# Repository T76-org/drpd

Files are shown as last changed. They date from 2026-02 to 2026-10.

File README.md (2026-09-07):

# Dr. PD - Open-source USB Power Delivery Analyzer and Programmable Sink

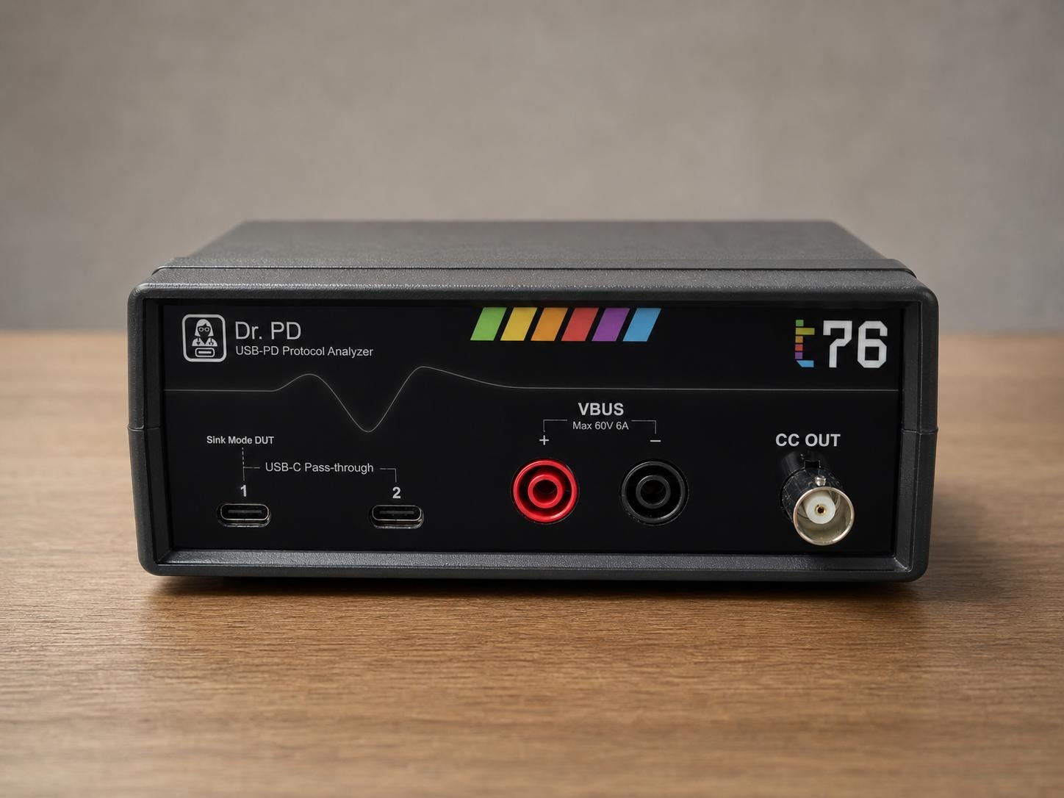
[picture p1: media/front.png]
DRPD Case Render


Dr. PD is a fully-featured USB Power Delivery (USB-PD) analyzer and programmable sink. It is designed to help characterize and troubleshoot USB-PD devices like chargers, cables, and sink devices. 

> [!NOTE]
> **Dr. PD will be available for crowdfunding soon through Crowd Supply.** Visit our [prelaunch page](https://www.crowdsupply.com/t76-org/dr-pd) to sign up and receive updates on the project, including the crowdfunding launch.
>
> Have any questions? [Drop us a note](mailto:hello@t76.org)!

## Features

Dr. PD can capture and decode USB-PD messages, measure voltage and current, and even emulate a USB-PD sink device to test chargers and cables under various conditions.

You can find out more about its features in the [online datasheet](./media/datasheet.md), but here are some important highlights:

### USB-PD protocol analysis

- Real-time message decoding with detailed protocol analysis
- Correlation of messages with VBUS voltage and current measurements
- Sophisticated search and trigger capabilities based on message types, device attach/detach events, power level changes, or external signals

### Programmable sink mode

- Emulate specific sink behavior, trigger faults, or test edge cases without a dedicated test fixture
- Analyze and test modern USB-PD implementations **up to 48V / 5A / 240W** with support for standard power delivery (SPR), extended power range (EPR), and programmable power supply modes (PPS/AVS)

### Software

- Real-time control software that runs in Chrome or Edge on Windows, macOS, Linux, and Android with no drivers or installation required
- First-class automation support with Python and JavaScript host libraries, plus support for industry-standard SCPI and USBTMC command interfaces
- Open-source hardware, firmware, and software with schematics and source code available on in this repo
- USB-PD stack implemented in firmware (instead of depending on a dedicated external chip) for maximum flexibility and updatability

## Documentation

You can access the full documentation for Dr. PD [on the T76 website](https://t76.org/drpd/docs). The documentation includes a user manual, hardware and firmware design files, and software API references.

Downloadable hardware schematics in PDF and KiCAD format are available in the [hardware folder](./hardware) of this repository. The current hardware version is [R2605-A](./hardware/R2605-A).

**Interactive online schematics and PCB layout** are available in [the docs](https://t76.org/drpd/docs/category/internals), which also contain a detailed, step-by-step description of the hardware design.

## Screenshots

Click on the images below to view them in full size.

<table width="810">
  <tr>
    <td width="270" align="center"><a href="./media/front.png">Dr. PD front panel</a></td>
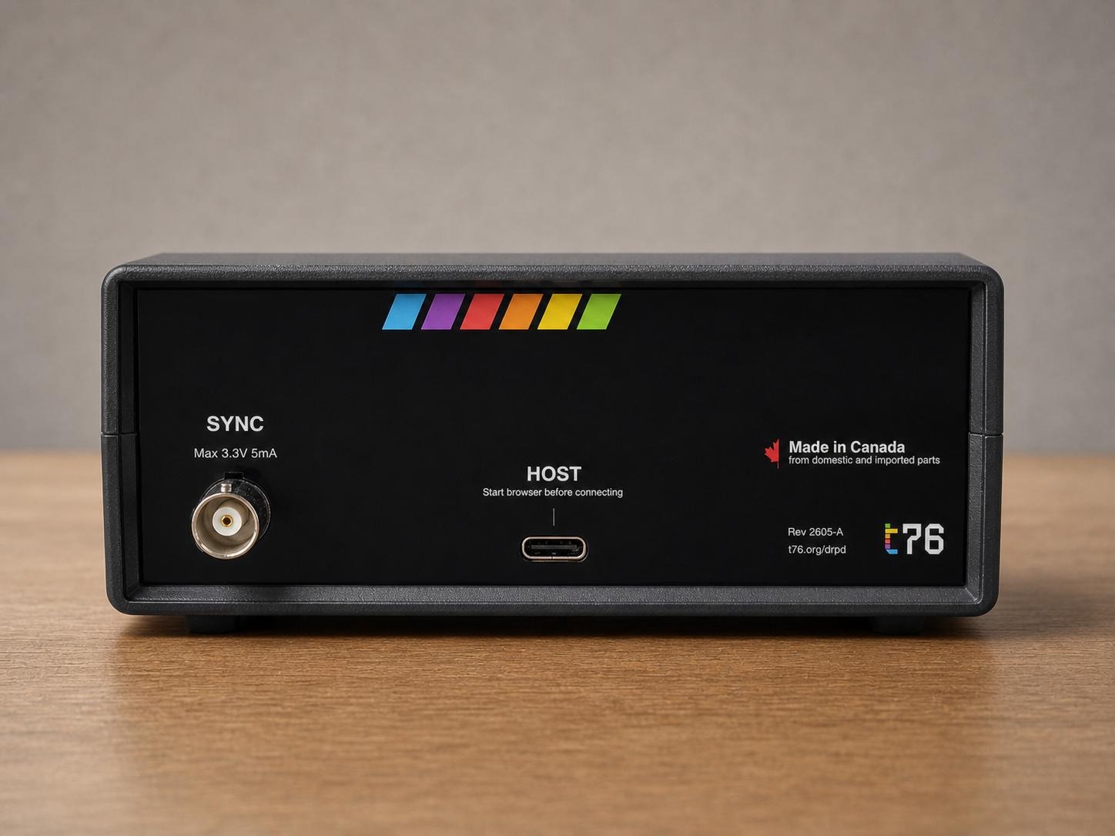
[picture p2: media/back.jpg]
Dr. PD back panel
    <td width="270" align="center"></td>
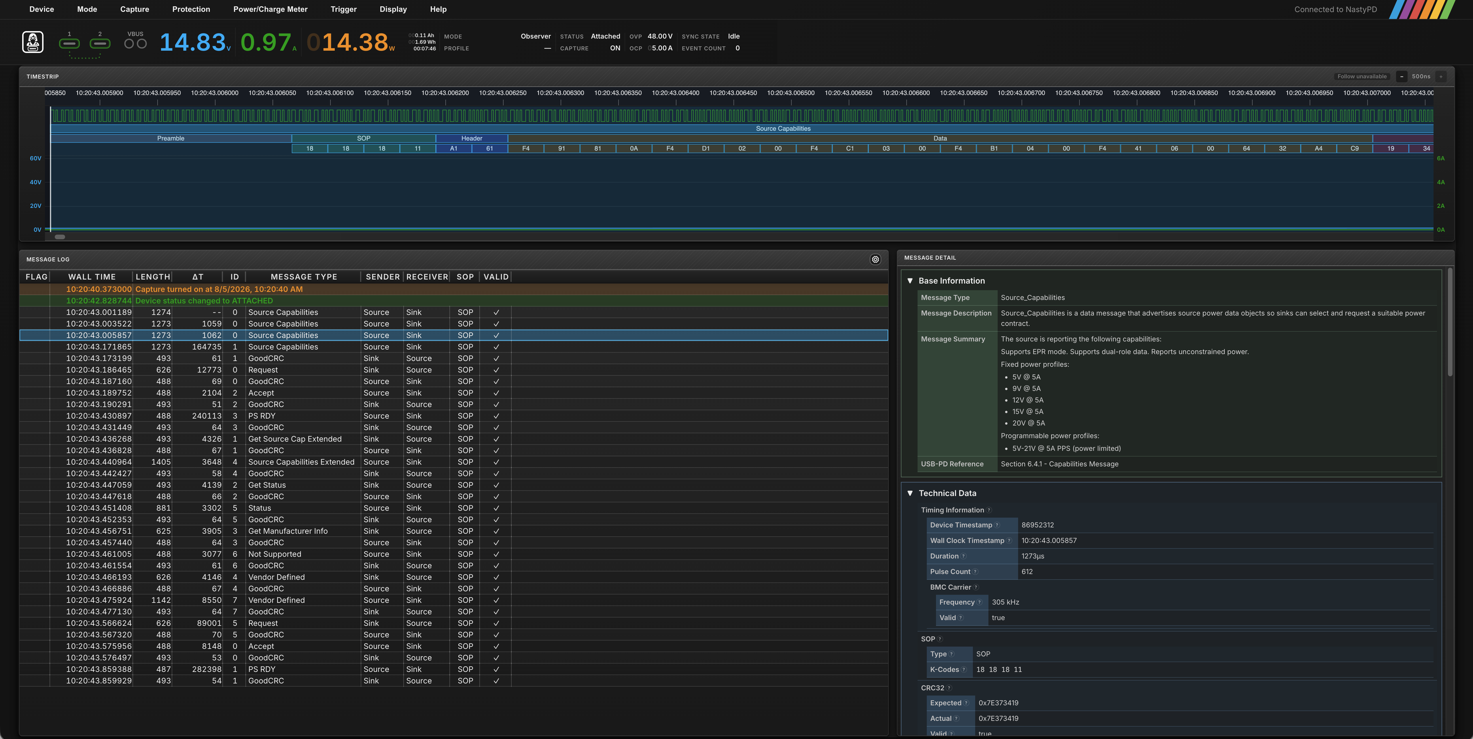
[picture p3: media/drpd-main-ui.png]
Dr. PD main interface
    <td width="270" align="center"></td>
  </tr>
  <tr>
    <td width="270" align="left" valign="top"><sub><strong>Front panel</strong></sub></td>
    <td width="270" align="left" valign="top"><sub><strong>Back panel</strong></sub></td>
    <td width="270" align="left" valign="top"><sub>The <strong>Main interface</strong> runs in your browser and shows live analog measurement, message capture, and analysis.</sub></td>
  </tr>
  <tr>
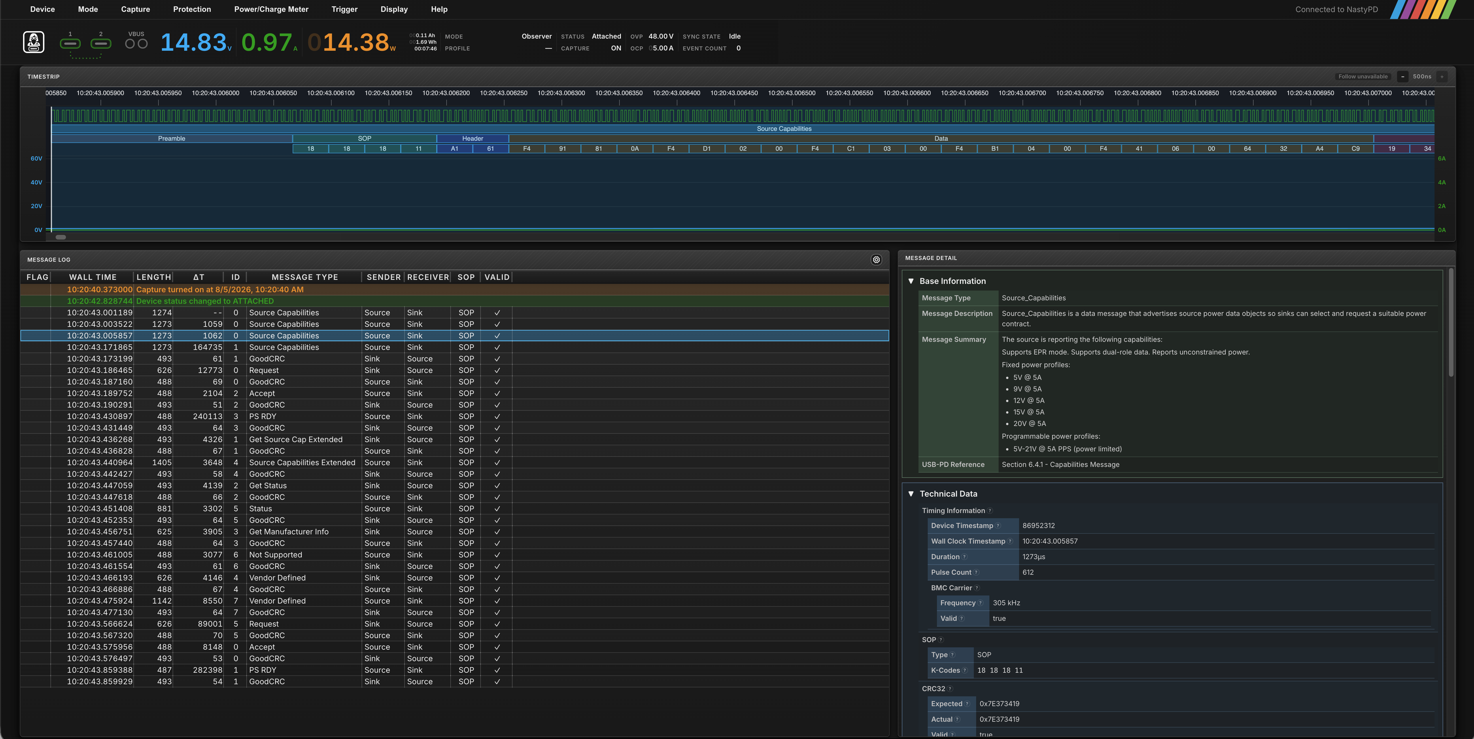
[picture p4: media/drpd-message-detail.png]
USB-PD message details
    <td width="270" align="center"></td>
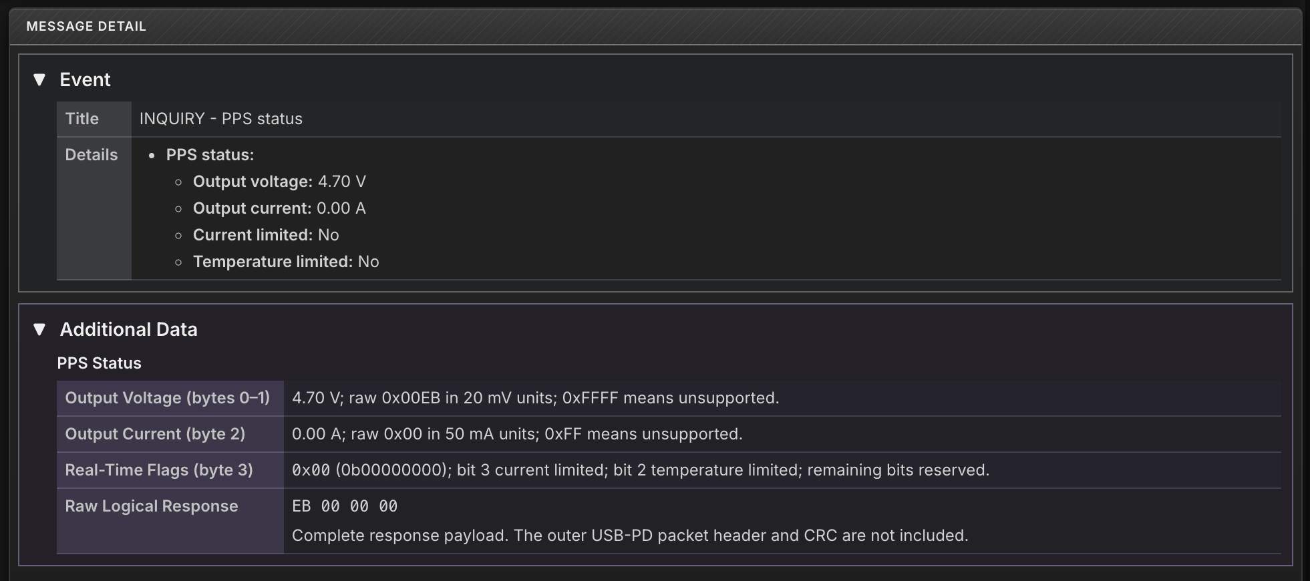
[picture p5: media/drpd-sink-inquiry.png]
Sink inquiry workflow
    <td width="270" align="center"></td>
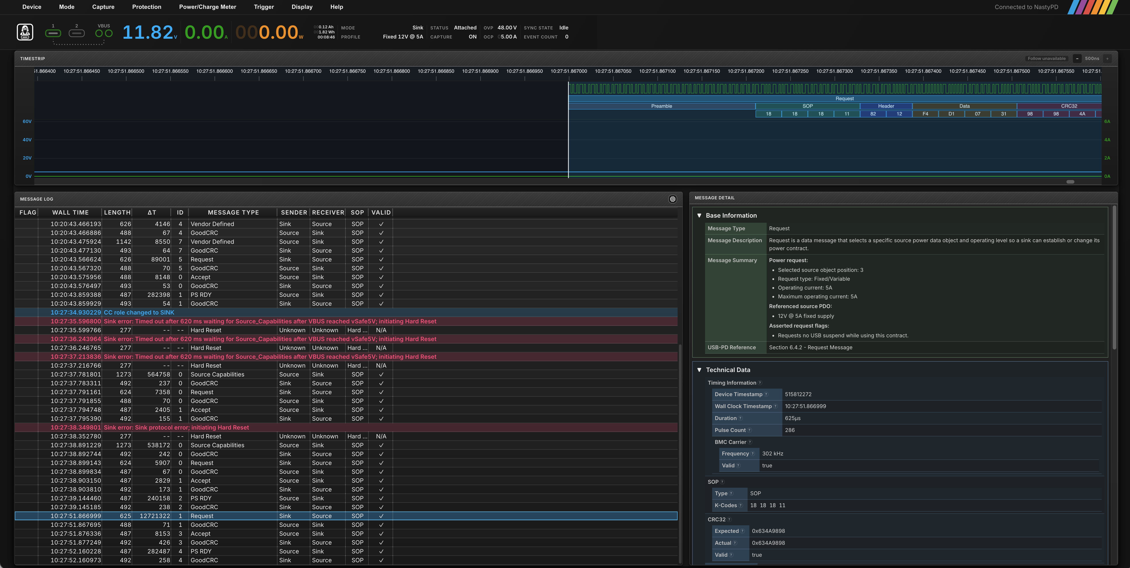
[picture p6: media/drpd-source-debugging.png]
Source debugging workflow
    <td width="270" align="center"></td>
  </tr>
  <tr>
    <td width="270" align="left" valign="top"><sub>The <strong>Message Detail</strong> breaks down each message into its constituent fields, timing data, CRC checks, and specification references.</sub></td>
    <td width="270" align="left" valign="top"><sub>In <strong>Sink Mode</strong>, Dr. PD can interrogate the source by sending arbitrary messages to it.</sub></td>
    <td width="270" align="left" valign="top"><sub><strong>Source debugging:</strong> Dr. PD can correlate protocol traffic, electrical activity, errors, and recovery attempts to help troubleshoot connectivity between sources and sinks.</sub></td>
  </tr>
  <tr>
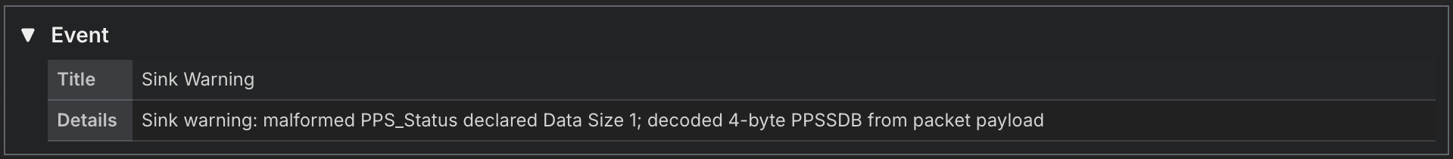
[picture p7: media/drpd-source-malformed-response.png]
Malformed source response analysis
    <td width="270" align="center"></td>
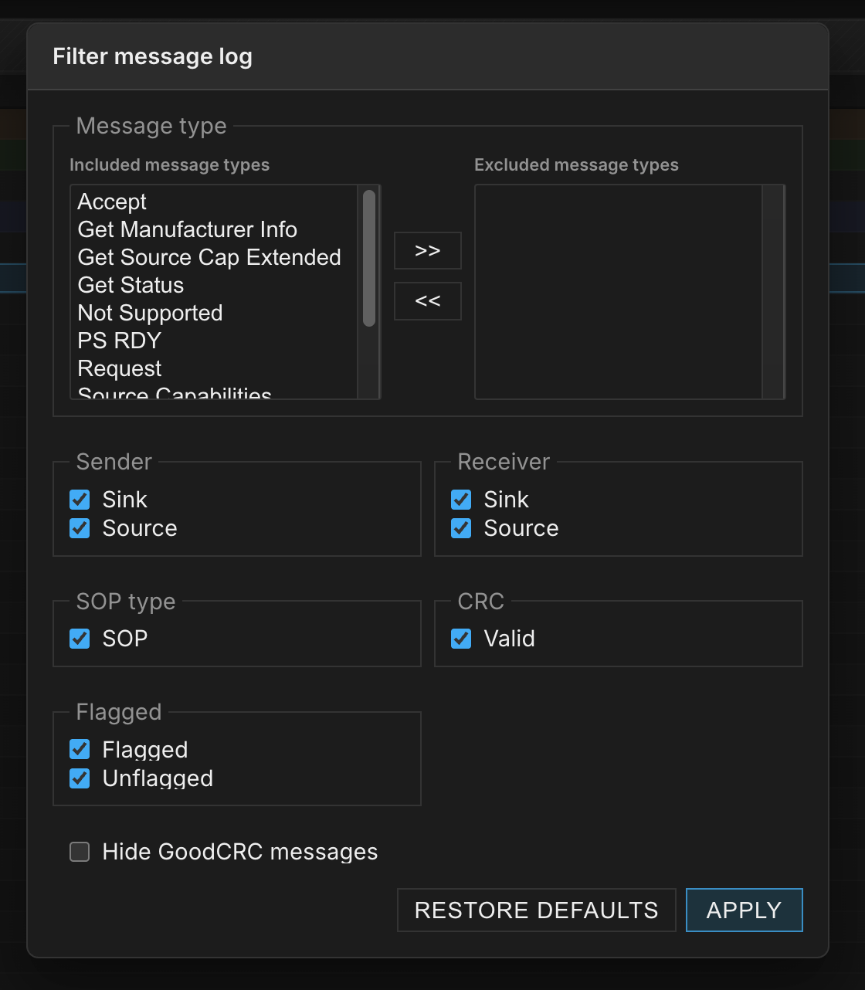
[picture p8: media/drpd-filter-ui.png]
Message log filters
    <td width="270" align="center"></td>
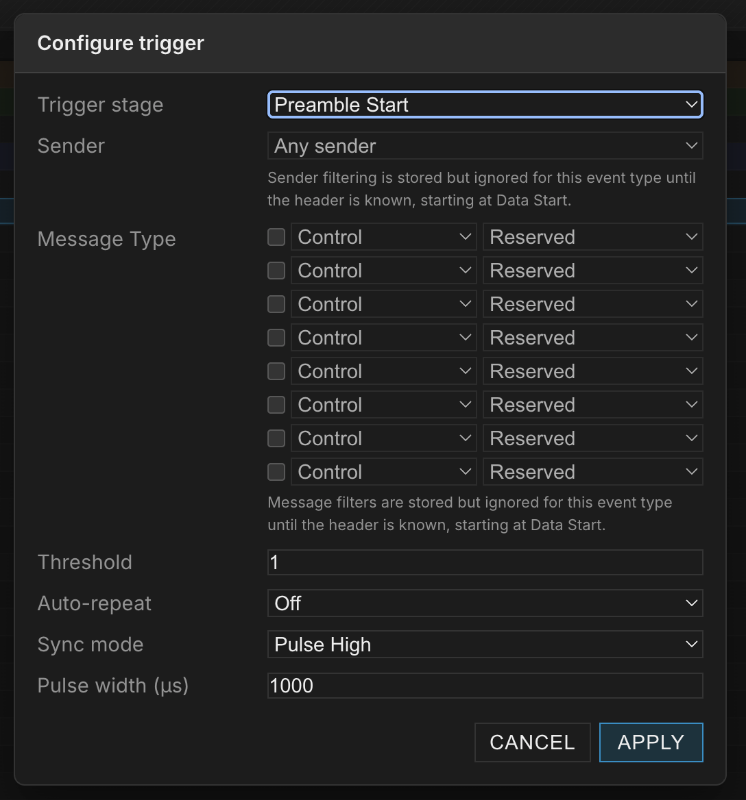
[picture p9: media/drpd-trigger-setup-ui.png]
Capture trigger setup
    <td width="270" align="center"></td>
  </tr>
  <tr>
    <td width="270" align="left" valign="top"><sub><strong>Response analysis:</strong> Here, Dr. PD has discovered that the connected source sent a non-compliant response.</sub></td>
    <td width="270" align="left" valign="top"><sub><strong>Message log filters</strong><br>Filter by message type, sender, receiver, SOP type, CRC, and flags.</sub></td>
    <td width="270" align="left" valign="top"><sub><strong>Capture trigger setup</strong><br>Trigger on protocol stages, message types, thresholds, or synchronized pulses.</sub></td>
  </tr>
</table>

## Project status

Dr. PD is currently undergoing device validation testing and will be available for crowdfunding soon through Crowd Supply. Visit our [prelaunch page](https://www.crowdsupply.com/t76-org/dr-pd) to sign up and receive updates on the project, including the crowdfunding launch.

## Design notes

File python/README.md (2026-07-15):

# `t76` Python Package

Python tooling for DRPD devices, including:

- A Python API for device discovery and control
- USB-PD message decoding helpers
- A Textual terminal app UI

Requires Python 3.11 or newer.

## Install from PyPI

> **Publication status:** `t76` is not published on PyPI yet. Until the first
> release is available, use the repository installation below.

```bash
python -m pip install t76
```

## Install from the Repository

From a clone of the repository:

```bash
python3 -m venv .venv
source .venv/bin/activate
python -m pip install --upgrade pip
python -m pip install -e ./python
```

For development dependencies:

```bash
python -m pip install -e "./python[dev]"
```

To leave the environment:

```bash
deactivate
```

Maintainers publish releases locally using the process in
[RELEASING.md](RELEASING.md).

## Run the Textual App

Launch the Dr. PD terminal app with:

```bash
drpd
```

The module entry point remains available:

```bash
python3 -m t76.drpd
```

If your `.venv` is active, `python -m t76.drpd` works as well.

You can also list available top-level apps with:

```bash
python -m t76 --apps
```

## Library Usage

### Discover and Connect to a DRPD Device

```python
import asyncio

from t76.drpd.device import find_drpd_devices

async def main() -> None:
    devices = find_drpd_devices()
    if not devices:
        print("No DRPD devices found.")
        return

    device = devices[0]
    await device.connect()
    try:
        mode = await device.mode.get()
        print(f"Connected to {device.name}, mode={mode}")
    finally:
        await device.disconnect()

asyncio.run(main())
```

### Decode USB-PD Messages

The `t76.drpd.message` package exposes message classes and decoding helpers.

Example imports:

```python
from t76.drpd.message import Message, SourceCapabilitiesMessage, VendorDefinedMessage
```

For captured BMC/PD data, see `BMCSequence.from_scpi_response(...)` in `t76.drpd.message.bmc_sequence`.

## Run Tests

With the `.venv` active:

```bash
bash run_tests.sh
```

Or directly:

```bash
python -m pytest t76/drpd/tests/ -v --tb=short
```

## License

The `t76` Python package is licensed under the GNU Affero General Public
License v3.0 only (`AGPL-3.0-only`). Source is available from the
[T76-org/drpd repository](https://github.com/T76-org/drpd).

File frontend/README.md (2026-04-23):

# Frontend

Primary docs:

- [Designer getting started](./docs/designer-getting-started.md)
- [Rack and instruments](./docs/rack-instruments.md)
- [Dr. PD device model](./docs/drpd-device.md)
- [Dr. PD worker runtime](./docs/drpd-worker-runtime.md)
- [Dr. PD firmware updater](./docs/drpd-firmware-updater.md)

Run locally:

```bash
npm run dev
```

For LAN debugging from another machine, start the HTTPS dev server:

```bash
npm run dev:https
```

The server stays on port `5173`. If you want to use the generated development
certificate, set `DRPD_DEV_PUBLIC_HOST` to a hostname that resolves to the dev
machine and use the exact HTTPS URL Vite prints, for example
`https://drpd.local:5173/`. If you want to use a raw LAN IP or a different
certificate name, point `DRPD_DEV_HTTPS_CERT` and `DRPD_DEV_HTTPS_KEY` at a
certificate whose SANs include that address or hostname.

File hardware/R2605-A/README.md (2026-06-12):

# Hardware revision R2605-A

Revision 2605-A is the first PVT revision of the Dr. PD hardware. It is based largely on R2603-A, with some important changes:

- The host port is now USB-C, rather than microUSB.
- The OVC/OCP circuit is bidirectional
- The banana connectors now include reverse-polarity protection
- There is a new slew control circuit for the BMC encoder outputs, which should better conform to the USB-PD standard and reduce EMI.

You can use the [virtual BOM](./virtual-bom/bom.html) to see the components used in this revision and how they are placed on the board.

The schematic is available in [PDF format](./pdf/Dr.PD.pdf) and in [KiCad format](./kicad/DrPD.kicad_sch), which can be viewed using [KiCanvas](https://kicanvas.org/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).

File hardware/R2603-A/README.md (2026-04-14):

# Hardware revision R2603-A

Revision 2603-A is the final prototype revision before production. It is the version that is in the hands of beta testers as of March 2026.

You can use the [virtual BOM](./virtual-bom/bom.html) to see the components used in this revision and how they are placed on the board.

The schematic is available in [PDF format](./pdf/Dr.PD.pdf) and in [KiCad format](./kicad/DrPD.kicad_sch), which can be viewed using [KiCanvas](https://kicanvas.org/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).

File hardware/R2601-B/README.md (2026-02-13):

# Hardware revision R2601-B

This was an early Dr. PD prototype that is unlikely to be in anyone's hands, so this schematic and layout is here primarily for historical reasons.

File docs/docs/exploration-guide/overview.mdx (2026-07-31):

---
sidebar_position: 1
---

# Start exploring Dr. PD

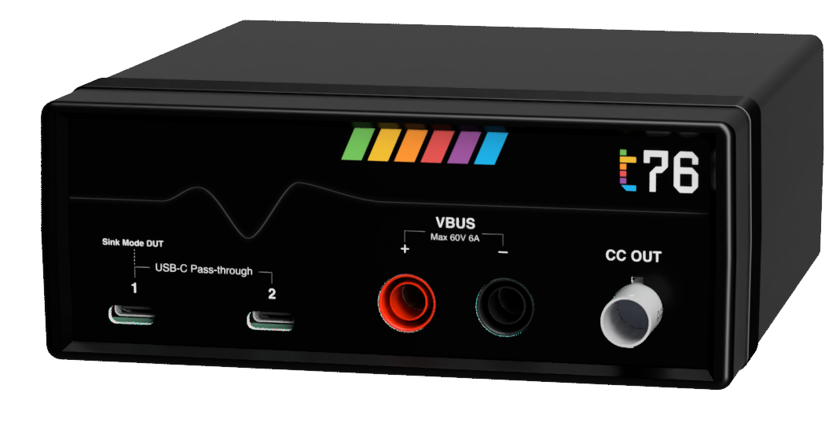
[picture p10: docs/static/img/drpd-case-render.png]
Dr. PD case render


Dr. PD is an open-source USB Power Delivery analyzer and programmable sink for
characterizing USB-PD sources, sinks, and cables. It captures decoded USB-PD
traffic, correlates protocol activity with VBUS voltage and current
measurements, and can act as a controllable sink when you want to see how a
source responds to different power requests.

This guide is a map of useful paths through the instrument. You can follow one
path end to end, skip to the workflow that matches your bench setup, or use the
links as a starting point before branching into your own tests.

## What you can explore

- **Protocol captures:** watch Source Capabilities, Requests, Accepts, PS RDY,
  GoodCRC messages, resets, and errors in the Message Log.
- **Power behavior:** correlate those messages with VBUS voltage and current
  while a source attaches, changes contract, disconnects, or trips protection.
- **Sink mode:** connect a USB-PD source to Port 1 and request advertised fixed,
  PPS, AVS, or EPR contracts when the source and cable support them.
- **Observer mode:** put Dr. PD inline between an existing source and sink to
  watch what those devices negotiate with each other.
- **Bench integration:** use the banana connectors, protection settings, sync
  output, exports, and automation interfaces when you want deeper measurements.

Dr. PD can work with USB-PD sources and cables up to 48 V / 5 A / 240 W when
the source, cable, negotiated protocol state, load, and safety setup all support
those conditions. EPR, PPS, and AVS behavior depends on what the attached source
and cable advertise and what you explicitly enable.

## Your first capture

For a first look, use a known-good USB-PD charger and cable.

1. Connect Dr. PD to the host computer with a USB-C cable capable of USB 2.0 communications, open the control software
   in Chrome or Edge, and pair the device. If your browser offers it, you can
   [install Dr. PD as an app](../how-to/installing-as-app.mdx) and launch the
   same control software in a standalone app window later.
2. Select **Capture → Enable Capture**.
3. Select **Mode → Sink**.
4. Connect the USB-PD source to Port 1.
5. Watch the Message Log populate with decoded USB-PD messages and correlated
   VBUS measurements.
6. Open **Mode → Choose power contract...** if you want to compare another
   contract that the source advertises.
7. Select a few messages and use **Capture → Export Selected → CSV...** or
   **Capture → Export Selected → JSON...** if you want data for notes or
   external analysis.

If the source was already connected when capture started, select **Mode → Cycle
USB Connection** before reviewing the log so the attach and initial negotiation
are captured.

For an inline observation path, put Dr. PD in **Mode → Observer**, connect it
between a source and sink with two USB-C cables, select **Capture → Enable
Capture**, and then attach the second device to capture the negotiation.

## Useful next paths

- [Front and back panels](./front-and-back-panels.mdx) for a visual tour of
  every physical connection on Dr. PD.
- [Quickstart overview](../quickstart/overview.mdx) for basic setup and first
  connection.
- [Testing a USB-PD source](../quickstart/testing-usb-source.mdx) for the first
  Sink mode walkthrough.
- [Capturing USB-PD messages](../how-to/capturing-messages.mdx) for capture,
  filtering, message details, and export.
- [Operating Dr. PD as a sink](../how-to/operating-as-sink.mdx) for programmable
  sink behavior, contract selection, PPS/AVS, and EPR notes.
- [Observing a USB connection](../how-to/observing-connection.mdx) for inline
  Observer mode setup.
- [Important warnings and safety precautions](../important-warnings.mdx) before
  high-power or unknown-device tests.

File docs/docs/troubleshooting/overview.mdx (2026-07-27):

---
sidebar_position: 1
title: Troubleshooting Dr. PD
---

# Troubleshooting Dr. PD

Start with the symptom that best matches what you see:

- If Dr. PD does not appear in the browser's device picker, disconnects from the control software, or cannot be paired, see [Computer connection](./computer-connection).
- If the control software opens but does not update or behave as expected, see [Control software](./control-software).
- If Dr. PD cannot attach to a source or negotiate the power contract you expect, see [Sink mode](./sink-mode).
- If the devices on either side of Dr. PD do not connect, or the capture is missing messages, see [Observer mode](./observer-mode).
- If you need to report a problem, see [Diagnostics and support](./diagnostics-and-support) for the information to collect.

## Basic checks

Before investigating a specific symptom:

1. Confirm that the control cable is connected to Dr. PD's control port, not Port 1 or Port 2.
2. Use a control cable that supports USB 2.0 data. A charge-only cable can power Dr. PD without making it available to the computer.
3. Disconnect and reconnect Dr. PD, then reopen the control software.
4. Confirm that Chrome or Edge is up to date.
5. Remove other USB-C devices and test with the simplest possible setup.

Change one cable, port, device, or setting at a time. This makes it much easier to identify which part of the setup caused the problem.

## Use the status indicators

The control software's MODE and STATUS indicators are useful starting points. First confirm that MODE shows the intended operating mode. Then note the exact STATUS value, such as **Unattached**, **Source Found**, or **Attached**, before changing the setup.

Also note whether VBUS, PROFILE, and the Message Log change when you attach a device. These observations help distinguish an electrical attachment problem from a power-negotiation or capture problem.

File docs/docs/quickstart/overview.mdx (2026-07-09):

---
sidebar_position: 1
---

# Get started in 5 minutes (or less)

Connecting Dr. PD to your computer and getting your first USB-PD capture is quick and easy. This guide will walk you through the steps to get up and running in no time.

## Things you will need

1. A computer with a recent version of Chrome or Edge and a USB port. Dr. PD runs on Windows, macOS, Linux, and Android.
2. A USB-C cable to connect Dr. PD to your computer or tablet. This cable must support USB 2.0 communications in order to run the control software, but it does not need to support USB-PD or high-speed data transfer.
3. A USB-PD source to test, such as a charger, power bank, or USB-C port on a laptop.
4. A USB-C cable.

## First steps

1. [Connecting Dr. PD](./connecting-dr-pd)
2. Pairing your device
3. Testing a USB-PD source

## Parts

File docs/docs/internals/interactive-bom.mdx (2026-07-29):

---
sidebar_position: 2
slug: /internals/interactive-bom/
hide_table_of_contents: true
title: Interactive BOM
description: Explore the Dr. PD R2605-A bill of materials and board placement.
---

import InteractiveBom from '@site/src/components/InteractiveBom';

# Interactive BOM

Use the component table and board view together to inspect the R2605-A bill of materials and locate parts on the PCB.

<InteractiveBom />

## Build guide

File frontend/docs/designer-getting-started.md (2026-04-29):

# Designer Getting Started

## What USB-PD Is

USB Power Delivery (USB-PD) is the negotiation protocol that runs over a USB-C connection so two devices can agree on power direction, voltage, current, and, in some cases, data mode changes. Instead of a cable always delivering one fixed power level, USB-PD lets a source and a sink negotiate profiles such as 5 V, 9 V, 15 V, or 20 V and coordinate capabilities, requests, and status updates.

For this project, the important UX implication is that the UI is not just showing static electrical readings. It is showing an active conversation between two USB-C partners: what power is available, what was requested, what role each side is playing, and what messages are moving across the link.

## What Dr. PD Does

Dr. PD is the hardware device this frontend talks to. In the codebase it appears as the device identifier `com.mta.drpd` and the display name `Dr. PD`.

At a high level, Dr. PD acts as a USB-PD analysis and control instrument. It can:

- monitor live VBUS measurements such as voltage and current
- observe CC line state
- capture USB-PD messages
- expose message logs and time-based visualizations
- let the operator configure sink behavior, triggers, and related test settings

That is why the UI looks more like a bench instrument rack than a conventional dashboard. It is presenting several specialized views onto one physical device.

## Core UI Concepts

### Rack

The main UI metaphor is a rack. A rack is the top-level visual workspace. It contains:

- a list of physical devices attached to the rack
- a list of rows
- persisted flex weights for rows and instruments
- draggable splitters between adjacent instruments and rows

The rack definition is persisted in local storage, so layout changes survive reloads.

### Device

A device is a physical hardware entry known to the rack. Right now the main device is Dr. PD. Devices are stored separately from instruments so multiple UI panels can bind to the same hardware record.

### Instrument

An instrument is one UI panel. Examples in this frontend include:

- `VBUS`
- `Device Status`
- `CC Lines`
- `Sink Control`
- `Sync Trigger`
- `Message Log`
- `Timestrip`
- `Message Detail`

Each instrument has a default flex weight plus minimum CSS width/height constraints. Users can resize instruments freely without a grid.

### Row

A row is a horizontal strip in the rack. Instruments sit side by side inside a row. The space between instruments is a draggable splitter that shifts flex weight from one neighbor to the other.

Rows also determine height. The space between rows is a draggable splitter. Dragging it grows one row and shrinks the adjacent row while honoring instrument minimum heights.

### Edit Mode

The rack has an edit mode for layout changes. In edit mode:

- instruments become draggable
- close buttons appear
- drop zones appear between rows
- drag operations can reorder within a row or create new rows
- changes are transactional until the user saves

Resize splitters are always active, even outside edit mode.

This matters for design work because layout affordances, focus states, glow treatments, and empty/drop states all live in this mode.

## How The Frontend Is Organized

### Main entry points

- `src/main.tsx`: bootstraps the app
- `src/App.tsx`: very thin shell around the rack view
- `src/index.css`: global design tokens, colors, typography, spacing, and rack sizing tokens
- `src/App.css`: root viewport layout

### Rack feature area

Most layout and UX work happens in `src/features/rack/`.

- `RackView.tsx`: page-level rack experience, header, theme toggle, add-device and add-instrument menus, edit mode, and persistence wiring
- `RackRenderer.tsx`: rack canvas sizing, scroll/fit behavior, row rendering, full-screen overlay handling
- `RowRenderer.tsx`: per-row instrument sizing, resize splitters, drag/drop insertion logic, and dispatch to concrete instrument views
- `layout.ts`: legacy unit helpers plus flex/min-size helpers
- `rackCanvasSize.ts`: computes the base rack canvas width and height
- `rackSizing.ts`: reads sizing tokens from CSS so TypeScript layout logic and CSS stay aligned

### Instrument implementations

Concrete instrument UIs live in `src/features/rack/instruments/`.

Each instrument typically has:

- a `.tsx` file for behavior and structure
- a `.module.css` file for scoped styling

If you are redesigning the chrome shared by all instruments, start with:

- `src/features/rack/InstrumentBase.tsx`
- `src/features/rack/InstrumentBase.module.css`

If you are redesigning a specific panel, work in that instrument’s `.tsx` and `.module.css`.

### Data and definitions

- `src/lib/rack/types.ts`: rack, row, instrument-instance, and device-record data model
- `src/lib/rack/loadRack.ts`: local storage persistence
- `src/lib/instrument/types.ts`: instrument definition model including default flex and minimum CSS sizes
- `src/features/rack/instrumentCatalog.ts`: the catalog of supported instruments and their default sizes
- `src/lib/device/drpd.ts`: Dr. PD device definition

## How Layout Works

### Flex-based layout

The rack uses CSS flex for instruments and rows. Legacy unit fields still exist for compatibility, but the renderer no longer allocates space with a grid or explicit panel sizes.

Default sizing tokens are:

- 1 horizontal unit = `20px`
- 1 vertical rack unit = `100px`
- maximum row width = `60` horizontal units

In practice the standard bench layout keeps a 1200 px reference width for header alignment. The rack canvas itself fills the viewport, with row heights and instrument widths coming from CSS flex weights.

### Width allocation and resizing

Instrument widths come from `instrumentCatalog.ts`.

- `defaultFlex`: default horizontal weight for new or migrated instances
- `minWidth`: minimum width CSS length during resizing

`RowRenderer.tsx` renders a splitter between adjacent instruments. Dragging it increases one instrument's flex weight and decreases the neighbor's flex weight. The browser handles final sizing through CSS flex.

The saved `RackInstrument.flex` value wins over catalog defaults.

### Height allocation

Each row and instrument uses flex for height distribution. Instruments declare `minHeight`.

`RackRenderer.tsx` renders a splitter between rows. Dragging it shifts flex weight between adjacent rows.

### Full-screen mode

An instrument instance can be marked `fullScreen: true`. When that happens, `RackRenderer.tsx` stops showing the standard rows and instead renders a full-screen overlay for that instrument.

## CSS Setup

### Global tokens first

`src/index.css` is the foundation. It defines:

- typography tokens (UI font: **Inter** via Google Fonts, with system-ui fallbacks in `--font-family-base`)
- spacing tokens
- radius and border tokens (including `--radius-instrument` for instrument panels, `--radius-control` for buttons and controls)
- rack sizing tokens
- light and dark theme colors
- elevation shadows: `--shadow-instrument` (instrument panels; dark uses inset top highlight + outer shadow), `--shadow-rack-canvas` (rack canvas), `--shadow-header` (page header; light theme)
- dark default look: charcoal / neomorphic-inspired surfaces (`#121212` page, `#1e1e1e` panels, instrument body uses `--color-surface-instrument` gradient only); instrument **title bars** use `--texture-instrument-header` (subtle diagonal stripes) plus a light gradient; light theme restores a larger `--radius-instrument`

Most shared dimensions are expressed through CSS custom properties in `src/index.css`. Use those tokens directly instead of reintroducing global scaling.

### Scoped styles second

Feature and instrument styles use CSS modules:

- `RackView.module.css`
- `RackRenderer.module.css`
- `RowRenderer.module.css`
- `InstrumentBase.module.css`
- instrument-specific `*.module.css`

The intended layering is:

1. `index.css` defines the shared system
2. feature CSS modules apply structure and component-level styling
3. instrument CSS modules handle panel-specific layout and visuals

### Important styling conventions

- Use tokens from `src/index.css` instead of hardcoded pixel or `rem` values when possible.
- Header popovers should use the shared popup typography tokens, not custom font sizes per instrument.
- Most instrument spacing and sizing should inherit from shared tokens so the interface stays coherent across displays.
- Shared panel chrome belongs in `InstrumentBase.module.css`; avoid duplicating it inside each instrument.

## How The UI Scales Across Resolutions

### Fixed tokens

The app uses fixed design tokens from `src/index.css`. Browser zoom remains native browser behavior; the app does not compute or write a global UI scale.

Because the scale is written into CSS variables, typography, spacing, borders, splitters, popovers, and many instrument-specific measurements all scale together.

### Practical effect

On smaller screens:

- text, controls, gaps, and instrument dimensions shrink together
- the rack still preserves its proportional structure
- some instruments will feel denser rather than switching to a separate mobile layout

On larger screens:

- the same visual system expands proportionally
- flex panels render larger in the scaled UI
- popovers and dense data tables also scale up

This frontend is therefore better described as a scaled desktop instrument UI than as a breakpoint-heavy responsive website.

### Scroll versus fit behavior

`RackRenderer.tsx` also adapts vertically based on available viewport height.

- if the viewport is shorter than the computed rack canvas height, the rack enters scroll mode
- if the viewport is tall enough, the rack fits without vertical scrolling

The renderer lets CSS flex stretch the rack canvas to the viewport. If minimum sizes exceed the viewport, the containing viewport handles overflow.

### Popovers and overlays

Header menus and instrument popovers use viewport-aware positioning from `RackView.tsx` and sizing tokens from `rackSizing.ts`. Their dimensions come from fixed tokens, and their position is clamped so they stay on-screen.

## Where A Designer Should Start

If your task is mainly visual polish:

- start with `src/index.css` for tokens and theme values
- then inspect `src/features/rack/InstrumentBase.module.css` for shared panel chrome
- then adjust `RackView.module.css`, `RackRenderer.module.css`, and `RowRenderer.module.css` for overall composition

If your task is panel-specific UX:

- work inside the target instrument under `src/features/rack/instruments/`
- check whether the issue is structural in the `.tsx` file or purely visual in the `.module.css`

If your task is changing spatial behavior:

- inspect `instrumentCatalog.ts` for default widths/heights
- inspect `layout.ts` for row allocation rules
- inspect `rackCanvasSize.ts` and `rackSizing.ts` for global size math

## Useful Additional Context

### Persistence

The rack document is stored in local storage under `drpd:rack:document`. If a layout change seems to “stick” unexpectedly while you are iterating, you may be seeing persisted local state rather than code changes.

### Theme support

The app supports dark and light themes through root-level CSS variables in `src/index.css`. Theme switching happens in `RackView.tsx` by setting `data-theme` on the document root.

The **dark (default)** palette layers neomorphic-style elevation (inset highlight + drop shadow) on instruments and the rack canvas; instrument **headers** use `--texture-instrument-header` (subtle stripes). **Light** theme uses a larger `--radius-instrument`. You can archive reference mockups alongside the repo under `docs/assets/` if useful.

### Current design bias

The current UI is intentionally instrument-like:

- dense information
- strong borders
- compact uppercase headers
- panelized layout instead of card grids

When redesigning, it is usually better to preserve the rack metaphor and improve clarity, hierarchy, and task flow than to flatten the product into a generic dashboard.

### Running the frontend

From the `frontend/` directory:

```bash
npm run dev
```

The sample rack lives at `public/racks/sample-rack.json`, and the active rack state is then persisted locally in the browser.

## Related docs

- `docs/rack-instruments.md`: rack and instrument architecture
- `docs/drpd-device.md`: Dr. PD command groups and device model
- `docs/drpd-worker-runtime.md`: frontend runtime and worker architecture

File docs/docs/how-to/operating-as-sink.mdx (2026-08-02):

---
sidebar_position: 2
---

# Operating Dr. PD as a sink

In addition to [observer mode](./observing-connection.mdx), Dr. PD can also be used in _Sink Mode,_ where it acts as a USB-PD sink device that can be powered by a compatible source. 

This mode allows you to safely test and characterize source devices and cables without risking damage to your actual devices, and with more control over power contracts and energy use than you would have with a real sink.

## Set up

To enter sink mode, click on **Mode → Sink** from the menu, or press the `S` key on your keyboard. You should see the MODE indicator in the control app's header change to "Sink," and the STATUS indicator will read "Unattached" until you connect a source device.

Connect your source device to Port 1 (the left port) using a USB-C cable of your choice. If all goes well, you should see the STATUS indicator change to “Attached,” and the VBUS voltage and PROFILE indicator will show the current power contract between the source and Dr. PD, which will normally be the default 5V/3A contract that most sources will offer to a sink that does not have any special capabilities.

## Changing the power contract

In sink mode, Dr. PD takes note of the contracts that the source offers, and allows you to establish a new contract with the source by selecting one of the offered contracts from the Sink power contract selection dialog (**Mode → Choose power contract...**). This allows you to test the behavior of the source under different power conditions, and to perform energy measurements at different power levels.

## Sending inquiries to the source

While Dr. PD is attached as a sink, select **Mode → Sink behaviour → Send inquiry to source** to ask the source for information such as its capabilities, status, revision, manufacturer information, country information, battery information, supported USB modes, or Type-C authentication data. The available inquiries depend on the negotiated USB-PD revision and active power contract.

Each selection starts one explicit inquiry. The source may return the requested information, reject the request, report that it is not supported, or fail to respond. Dr. PD records the request, response, and final outcome in the Message Log; keep capture enabled if you want to inspect or export that evidence. These inquiries normally leave the active power contract unchanged.

:::caution

Some inquiries have protocol-defined side effects. In particular, **Get status** clears the source's latched overcurrent, overvoltage, and overtemperature event indicators after reading them. Dr. PD asks for confirmation before sending an inquiry with a known side effect.

:::

## Drawing power from the source

In sink mode, you can use the banana connectors to monitor the VBUS voltage with an external voltmeter, and to draw current from the source using an external load—for example, to perform energy measurements or test the source's protection mechanisms.

:::note

In this mode, Port 2 is disconnected from the USB-PD bus and VBUS line in order to protect any device that you might have inadvertently left connected to that port, and so you will not be able to use Port 2 for any USB-PD communication or power delivery while in sink mode.

:::

:::warning[Safety mechanisms]

In addition to the protection mechanisms implemented by your source device, Dr. PD implements its own set of [overvoltage/overcurrent protections](./protection-mechanisms). You can use them in tandem with native protections in order to make sure that you don't damage your source device or Dr. PD itself while testing, but Dr. PD does not automatically set any protection mechanisms for you (beyond the default 60V / 6A limits that are hardcoded into the firmware to prevent damage to Dr. PD itself), so you should make sure to set appropriate limits for your tests in order to avoid damage to your source device or Dr. PD.

:::

## Using PPS and AVS contracts

The USB-PD protocol includes some special types of power contracts that allow for more granular control over the voltage and current levels, which can be useful for testing sources that support these contracts:

- PPS (Programmable Power Supply) contracts allow the sink to request specific voltage and current levels within a certain range, which can be useful for testing sources that support PPS and for avoiding triggering the protection mechanisms of the source when drawing power at higher levels.
- AVS (Adjustable Voltage Supply) contracts similarly allow the sink to request specific voltage levels within a certain range, but they are designed for higher voltage levels (up to 48V) and are typically used for applications like USB-PD power delivery to laptops and other high-power devices.

Dr. PD is fully compatible with both PPS and AVS. If your source supports PPS or AVS contracts, you can use them to test the source's behavior under different voltage and current conditions, and to perform energy measurements at different power levels without triggering the source's protection mechanisms.

:::tip[Requesting PPS status information]
With an active PPS contract, select **Mode → Sink behaviour → Send inquiry to source → Get PPS status** to request the voltage, current, and operating status reported by the attached Source. This sends one explicit `Get_PPS_Status` inquiry.
:::

## Enabling support for EPR

Recent versions of the USB-PD protocols have introduced _Extended Power Range_ (EPR) contracts, which allow for power delivery at voltages up to 48V and currents up to 5A. Dr. PD is compatible with EPR, and we designed its hardware specifically to support voltage and current ranges _in excess_ of the USB-PD 3.1 specification in order to allow you to test EPR sources and cables without risking damage to Dr. PD itself.

:::warning
At 48V and 5A, high-end EPR sources pack quite the punch and can deliver some 240W of power (in our experience, they will often even _exceed_ this level by a small amount). This is more than enough to cause serious damage to devices that are not designed to handle such power levels, and even cause a fire if something goes wrong.

When you test EPR sources at high power levels, make sure to use appropriate safety precautions, such as using a high-quality USB-C cable that is rated for EPR, making sure that your source and Dr. PD are on a non-flammable surface, and keeping a fire extinguisher nearby just in case.
:::

EPR support is off by default. In order to enable it, choose **Mode → Sink behaviour → Support EPR mode**. Once you have enabled EPR support, Dr. PD will be able to negotiate EPR contracts with compatible sources, and you will be able to test the source's behavior under EPR conditions.

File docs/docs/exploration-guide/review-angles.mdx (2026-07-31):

---
sidebar_position: 3
---

# Choose an exploration path

Dr. PD can be approached from several directions. The paths below are not
scripts; they are starting points for deciding what you want to learn first.
Each one points to the parts of the instrument that tend to be most useful for
that kind of exploration.

## Embedded and software path

This path is useful when you care about repeatability, exported data, and how
USB-PD behavior can fit into a development workflow.

Things to try:

- Capture and decode USB-PD messages while a device attaches, negotiates, and
  changes state. The [message capture guide](../how-to/capturing-messages.mdx)
  explains the decoded fields, timing information, and export flow.
- Export selected captures as CSV for fixed summary columns, or as JSON for
  stored raw capture rows and annotations that can be imported and decoded
  again.
- Compare repeated attach or **Mode → Cycle USB Connection** runs to see
  whether the same source capabilities and contracts appear each time.
- Use Python, JavaScript, SCPI, or USBTMC for small repeatable checks, such as
  setting a mode, enabling capture, cycling the connection, and recording the
  resulting negotiation.

Look for how protocol state, exported data, and VBUS measurements line up. When
automation enters the picture, treat it as a way to repeat the same setup more
consistently, not as a guarantee that every attached source, sink, cable, and
load will behave identically.

## Bench power path

This path is useful when you want to understand how a USB-PD source behaves
under real load.

Things to try:

- Operate Dr. PD in [sink mode](../how-to/operating-as-sink.mdx), select an
  offered source contract, and draw current through the banana connectors using
  an external electronic load.
- Correlate USB-PD messages with VBUS voltage and current during contract
  changes, load steps, or disconnects.
- Configure [OVP/OCP protection](../how-to/protection-mechanisms.mdx) before
  tests that may exceed expected limits.
- Use the [calibration workflow](../how-to/calibrating.mdx) when absolute
  agreement with reference instruments matters.

Useful comparisons include requested contract versus measured VBUS, voltage sag
during load changes, recovery after a load step, and agreement between Dr. PD,
the electronic load, and any external meter or power analyzer.

## Diagnostics path

This path is useful when a charger, dock, cable, laptop, power bank, or adapter
does not negotiate the way you expect.

Things to try:

- Use [observer mode](../how-to/observing-connection.mdx) inline between two
  USB-C devices to watch their negotiation.
- Capture a working setup and a suspect setup, then compare Source
  Capabilities, Requests, GoodCRC behavior, resets, detach events, and VBUS
  changes.
- Add manual markers in the Message Log when you swap a cable, connect a load,
  or change the physical setup.
- Use sink mode separately when you want to isolate a source from the rest of a
  system.

This path is best at narrowing possibilities. A capture can point toward a cable
issue, a rejected request, repeated resets, or a missing capability, and the next
step is usually a comparison with known-good hardware.

## Protocol and signal path

This path is useful when you want to relate decoded USB-PD packets to physical
timing or external instruments.

Things to try:

- Configure the [sync output and triggers](../how-to/using-triggers.mdx) for
  packet starts, message completion, hard resets, CRC errors, runt pulses, or
  selected message types.
- Connect the sync output to an oscilloscope or logic analyzer alongside CC,
  VBUS, or an external load monitor.
- Compare the trigger event, decoded Message Log row, and VBUS change in the
  same run.
- Use **Capture → Filter...** to focus on the message types relevant to the
  case you are exploring.

The sync output is firmware-managed and has measurable latency. For precise
timing or signal-integrity work, pair Dr. PD's decoded log with a scope capture
of the relevant physical signals.

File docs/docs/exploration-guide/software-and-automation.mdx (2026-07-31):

---
sidebar_position: 6
---

# Software and automation tour

The browser app is the easiest place to begin. It lets you connect the
instrument, choose a mode, capture traffic, change USB-PD behavior, and export
evidence. Once a workflow is familiar, the same ideas can move into scripts for
repeatable exploration.

## Browser requirements and pairing

The control app runs in Chrome or Edge because it uses browser USB access to
talk to the instrument. Use a recent desktop browser on Windows, macOS, or
Linux, or a compatible Android browser setup, and connect Dr. PD to the host
through the control port on the back of the device.

A typical first connection looks like this:

1. Open the Dr. PD control software in Chrome or Edge.
2. Connect Dr. PD over the control port and wait for the browser to detect it.
3. Select **Device → Pair new device...**.
4. Choose the Dr. PD USB device in the browser permission prompt and approve
   the connection.
5. Confirm that the app shows the paired device and live instrument status.

Pairing is a browser permission step, not a driver install. Once paired, the app
can reconnect to the same instrument from the Device menu.

## Installing as an app

Chrome and Edge can offer Dr. PD as an installable web app when the current
browser, URL, and app state meet their installability requirements. When that is
available, choose **Help → Install Dr. PD as app...** and follow the browser
prompt.

Installing the app does not add a driver or change the USB permission model. It
gives the same control software a standalone app window and launcher entry. The
menu item is intentionally conditional: it is hidden when the browser has not
made installation available, when Dr. PD is already installed, or when the app
is already running in standalone mode.

See [Installing Dr. PD as an app](../how-to/installing-as-app.mdx) for the
step-by-step notes.

## App tour

With a known-good USB-PD source and cable, you can explore the main app surfaces
quickly:

1. Select **Mode → Sink**.
2. Select **Capture → Enable Capture** before attaching the source if you
   want the full attach and negotiation sequence.
3. Connect the USB-PD source to Port 1.
4. Watch the Message Log populate with decoded USB-PD messages, event rows, and
   correlated VBUS voltage/current samples.
5. Select a negotiation message to inspect decoded fields, raw data, warnings,
   and timing details in the message detail view.
6. Open **Mode → Choose power contract...** to explore **Sink power contract
   selection** and request one of the source's advertised contracts.
7. Select relevant rows and use **Capture → Export Selected → CSV...** or
   **Capture → Export Selected → JSON...** when you want output.

The **Sink power contract selection** dialog lists available PDOs and exposes
voltage/current inputs where the selected PDO type allows a user-selected value.
Fixed PDO voltage is shown read-only; PPS, AVS, variable, and battery style
entries expose the relevant editable request fields.

## Message Log workflow

The Message Log is the main surface for protocol evidence.

- **Capture → Enable Capture** starts recording decoded USB-PD traffic,
  analog VBUS samples, and app-injected events.
- Click the **Configure** button in the Message Log panel header to control
  visible table columns and capture buffer depth. Column widths and layout
  choices are remembered by the app.
- **Capture → Filter...** narrows the view by message properties, while
  the filter dialog also provides a **Hide GoodCRC Messages** control.
- **Capture → Hide GoodCRC Messages** keeps acknowledgements out of the
  working view without changing the underlying capture.
- **Capture → Add marker** inserts a manual event row when the physical
  setup changes, such as swapping a cable or adding load.
- **Capture → Export Selected → JSON...** exports stored capture rows,
  including raw data and annotations, for later re-import and decoding.
- **Capture → Export Selected → CSV...** exports a fixed,
  spreadsheet-friendly summary table.

JSON is useful for reopening a capture in the app or processing stored raw
records and annotations. It does not include the complete expanded Message
Detail field tree. CSV is useful for compact summaries and quick comparisons
between runs; its columns do not depend on the current Message Log layout.

## Sink and Observer paths

Sink mode makes Dr. PD the USB-PD sink. It is useful for exploring how a
charger, laptop port, power bank, or cable responds to specific contracts. The
app path is **Mode → Sink**, followed by **Mode → Choose power
contract...** when the source has advertised PDOs.

Observer mode puts Dr. PD inline between an existing source and sink so you can
capture a real device negotiation. Use **Mode → Observer**, select
**Capture → Enable Capture**, connect one side, and then connect the other
side to record the attach sequence.

In either Sink or Observer mode, **Mode → Cycle USB Connection** simulates a
USB detach and reconnect from the app. This is useful when you want another
negotiation capture without rewiring the bench.

## Protection and calibration

Set protection limits before high-voltage or high-current tests. Select
**Protection → Set thresholds...** to open **OVP/OCP settings**, then enter
overvoltage and overcurrent thresholds within the ranges shown by the dialog.
Treat those values as setup parameters, not as operating targets.

Calibration is exposed per paired device through the Device menu:

- **Device → [paired device] → Calibrate → Voltage...**
- **Device → [paired device] → Calibrate → Current...**

Use the calibration workflow when agreement with a reference DMM, load, or power
analyzer matters. For a general workflow tour, it is enough to know where
calibration lives and avoid relying on absolute accuracy without a cross-check.

## Triggers and sync output

The Trigger menu controls the external sync output and protocol-event triggers.
Select **Trigger → Configure...** to choose the trigger stage, sender filter,
optional message-type filters, auto-repeat behavior, sync output mode, and pulse
width. Select **Trigger → Reset** after a one-shot trigger fires.

One useful path is to connect the sync output to an oscilloscope or logic
analyzer and compare three things in the same run: the physical trace, the
Message Log row, and any VBUS change. The sync output is firmware-managed and
has measurable latency, so it should not be treated as a zero-latency copy of
the CC waveform.

## Automation interfaces

The same instrument behavior is available below the UI for repeatable tests.
Current docs and source support these automation paths:

- Python host code is present in the repository under `python/`, alongside SCPI
  helpers.
- The web app is implemented in TypeScript/JavaScript and includes host-side
  device, transport, parser, logging, and export code used by the browser UI.
  Do not imply a separately published JavaScript package unless you are citing
  a specific release artifact.
- The firmware exposes SCPI commands for identity, status, analog measurement,
  role control, capture control, sink PDO selection, protection thresholds,
  trigger configuration, sync output configuration, calibration, and reset
  workflows.
- Browser transport code can use the instrument over USBTMC-compatible and
  WinUSB-style paths through WebUSB, depending on the platform and device
  interface.

Small scripted paths are often the most useful: query identity, set Sink or
Observer mode, enable capture, cycle the USB connection, request a selected sink
PDO, read status or measurements, then export or retrieve captured data.

## Evidence exports

For manual exploration, select rows in the Message Log and use **Capture →
Export Selected → JSON...** or **Capture → Export Selected → CSV...**. JSON
preserves structure and decoded details; CSV gives a compact table for notes,
plotting, or comparisons.

For scripted exploration, tie exported files or captured SCPI responses to the
source, cable, selected mode, requested contract, load, and protection
thresholds. That makes later comparisons easier to understand.

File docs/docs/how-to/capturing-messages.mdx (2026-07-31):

# Capturing USB-PD messages

In either Observer or Sink mode, Dr. PD can capture and log USB-PD messages. This can be useful both for debugging purposes and to understand how a particular device behaves.

## Setting up the capture

You can turn capture on and off at any time by selecting **Capture → Enable Capture** or **Capture → Disable Capture** from the menu, or by pressing the `C` key on your keyboard.

When capture is enabled, Dr. PD will log both analog VBUS information (voltage and current) and the decoded USB-PD messages, and correlate both so that you can visualize how messaging affects the power delivery.

Capture can remain on at all times, even when no device is connected to Dr. PD. When the capture buffer is full, the oldest data points will be overwritten by new ones.

:::note

In Sink mode, if you want to capture what happens when you connect a device to Dr. PD, you should enable capture _before_ connecting the device. This way, you can capture the entire connection process, including the initial power negotiation.

In Observer mode, you should connect one of the two devices, enable capture, and then connect the other device to complete the USB-PD connection.

In both modes, you can click on **Mode → Cycle USB Connection**, or press the `T` key, to simulate a physical disconnection and reconnection of the devices. This can be useful to trigger a new USB-PD negotiation, and to capture the messages that are exchanged during the connection process.

:::

## Viewing the captured messages

Captured messages are displayed in the Message Log panel. The log shows:

- The timestamp of each message, referenced to the wall clock of your computer.
- The duration of the message in microseconds.
- The the time difference, again in microseconds, between the current message and the previous one (Δt). This can be useful to understand the timing of messages and identify any delays or gaps in communication.
- The USB-PD ID of the message. This is a unique, three-bit identifier that is incremented for each new message, and can be used to track the sequence of messages in a conversation.
- The type of message, which can be either a USB-PD control message (e.g. GoodCRC, Accept, etc.) or a data message (e.g. Source Capabilities, Request, etc.).
- The sender (Source or Sink) of the message.
- The receiver (Source or Sink) of the message.
- The Start-of-Packet (SOP) type, which indicates the type of USB-PD communication (e.g. SOP, SOP', etc.).
- Whether the message has a valid CRC32 checksum.

If you select one of the messages in the log, you can see a detailed breakdown of its contents in the Message Detail panel. This includes the raw message data, the decoded fields of the message, and any errors or warnings associated with it. The Message Detail view contains a lot of information, and can be overwhelming at first, but it can be very useful to understand the inner workings of USB-PD communication and to debug any issues that may arise. Most of the fields in the Message Detail provide a tooltip with an explanation of their meaning and how they are decoded from the raw message data.

## Configuring the message log

Clicking the **Configure** button in the Message Log panel header will open a dialog where you can configure the fields that are shown in the message log table. You can also resize the various columns in the log by dragging their edges, and the software will remember your preferences for the next time you open it. This can be useful to focus on the specific information that is relevant to your analysis, and to hide any fields that you find less useful.

You can quickly restore the table to its default configuration by clicking on the **Capture → Restore Table Layout** menu item.

:::note[Adjusting capture duration]
The configuration dialog controls how many captured message and event rows the
Message Log retains, up to 1,000,000. This count does not control the separate
analog-sample retention limit. Because USB-PD traffic rates vary, a retained
message count does not correspond to a fixed capture duration. Larger limits
use more storage and may affect performance.
:::

## Filtering messages

Some captures can be very long and contain a lot of messages, which can make it
difficult to find the specific messages you are interested in. Select
**Capture → Filter...**, or press `F`, to filter by message type, sender,
receiver, SOP type, CRC validity, or flagged state. The filter dialog also
contains the **Hide GoodCRC Messages** control. Filtering changes the working
view without deleting captured rows.

:::note[Hiding GoodCRC messages]
GoodCRC messages are control messages that are sent by the receiver to acknowledge the receipt of a message. They are very common in USB-PD communication, and can clutter the log if you are not interested in them. You can choose to hide GoodCRC messages from the log by clicking on **Capture → Hide GoodCRC Messages**, or by pressing the `G` key. This will make it easier to focus on the more relevant messages in the capture.
:::

## Logging events

Dr. PD injects _events_ in the message log when certain conditions occur during a capture. These include starting or stopping a capture, changes in the connection state, and overvoltage/overprotection triggers. These events are marked with a different color in the log, and can be used to correlate changes in the connection state or power delivery with the messages being exchanged between the devices.

:::note[Adding manual markers]
You can add a “Manual Marker” event to the log by clicking on **Capture → Add marker**, or by pressing the `M` key. This can be useful to mark a specific point in the capture, for example when you perform a specific action on the device, or when you want to highlight a particular message or sequence of messages.
:::

## Clearing the log

You can clear the message buffer at any time by clicking on **Capture → Clear Log**, or by pressing the `X` key.

## Exporting a capture

You can export any selected messages from the log to either CSV or JSON files by selecting **Capture → Export Selected → CSV...** or **Capture → Export Selected → JSON...**. This can be useful to analyze the captured messages in other tools, or to share them with others for debugging purposes.

The two export formats serve different purposes:

- CSV uses a fixed export schema: Type, Wall time, Length, Δt, ID, Message type,
  Sender, Receiver, SOP, CRC32, Valid, and Message Summary. It does not change
  when you configure which columns are visible in the Message Log. Use it for
  spreadsheet analysis and compact sharing.
- JSON preserves the selected stored capture rows, including raw capture data,
  parse errors, flags, comments, and timestamps. The app can re-import this
  format and decode the raw messages again. It does not contain the complete
  expanded field tree or every warning shown by Message Detail.

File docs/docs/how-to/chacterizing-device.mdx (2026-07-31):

---
sidebar_position: 5
---

# Characterizing USB-PD source and sinks

Dr. PD can be used to characterize the behavior of a USB-PD device to understand how it behaves in different scenarios, and to identify any issues or anomalies in its behavior. This can be useful both for debugging purposes and to understand how a particular device behaves.

There are, fundamentally, two ways to characterize a device with Dr. PD:

- For sources, you can use Sink mode and an electronic load to determine how the source behaves under different load conditions, and to identify any issues with its power delivery capabilities. For power banks, the energy and power accumulators can be used to determine the total capacity of the power bank, and to identify any issues with its energy delivery capabilities.
- For sinks, you can use Observer mode to monitor the amount of energy required to charge a device, and to identify any issues with its power consumption. For example, you can use Dr. PD to monitor the charging of a smartphone, and to identify any issues with its charging behavior, such as excessive power consumption or overheating.

:::tip[If you don't have an electronic load]
An electronic load will give you the highest degree of control over load conditions; more advanced electronic loads can even simulate dynamic load conditions and can be controlled programmatically to automate testing. However, they can be expensive and may not be accessible to everyone.

If you don't have an electronic load, you can use a USB-PD sink device (such as a laptop or a smartphone) to draw power from your sources, and use Dr. PD in Observer mode to monitor the energy delivered by the power bank. This method gives you less control over the load conditions, but it can still provide useful information about the power bank's capacity and performance.
:::

:::warning
Dr. PD implements its own set of [safety mechanisms](./protection-mechanisms) to protect both itself and your devices. Make sure that the overvoltage and overcurrent protection thresholds are set so that they do not interfere with your measurements.
:::

## Testing a source's power delivery and safety mechanisms

USB-PD compliance requires that sources implement certain safety mechanisms to protect against overvoltage, overcurrent, and other abnormal conditions. Dr. PD can be used alongside an electronic load to test these safety mechanisms by simulating different scenarios and observing how the source responds:

1. Select **Capture → Enable Capture** before connecting the source.
2. Select **Mode → Sink**, then connect the source you want to test to Port 1 (the left port).
3. Connect an electronic load to the banana jacks.
4. Select **Mode → Choose power contract...** to [negotiate a power contract](./operating-as-sink) with the source, and select a power profile that matches your requirements.
5. Gradually increase the load on the electronic load, and observe how the source responds to the increasing power demand. Once the load exceeds the power contract, the source should respond by either limiting the current or (more commonly) by shutting down the power delivery to protect itself and the connected devices. You can use the analog trace to see exactly when the protection mechanism kicks in, as well as the current level at which it happens.

If the source was already connected when capture started, select **Mode → Cycle
USB Connection** before choosing a power contract so the initial negotiation is
recorded.

:::tip
USB-PD is pretty forgiving when it comes to overcurrent conditions, and you may find that some sources will allow the current to exceed the power contract for a short period of time before shutting down. This is because USB-PD allows for a certain amount of tolerance in the power delivery, and some sources may be designed to handle short-term overcurrent conditions without triggering their protection mechanisms. However, if you continue to increase the load, you should eventually see the source shut down the power delivery to protect itself and the connected devices.

If this behaviour is not acceptable for your application, and the source supports at least one PPS or AVS contract, these allow you to have more granular control over the voltage and current levels, and to avoid triggering the protection mechanisms of the source.
:::

## Testing a battery bank's capacity

The batteries in a power bank degrade over time, and their capacity decreases as they are used. Dr. PD can be used to test the capacity of a power bank by measuring the amount of energy it can deliver before it is depleted:

1. Select **Power/Charge Meter → Reset**, then select **Capture → Enable Capture** before connecting the power bank.
2. Select **Mode → Sink**, then connect the fully-charged power bank you want to test to Port 1 (the left port).
3. Connect an electronic load to the banana jacks, and set it to draw a constant current that is within the power bank's specifications.
4. If the power bank was already connected when capture started, select **Mode → Cycle USB Connection** to record a fresh attach and negotiation.
5. Start the electronic load, and let it draw power from the power bank until it is depleted. You can use the energy accumulator in Dr. PD to measure the total amount of energy delivered by the power bank before it is depleted. This will give you an estimate of the power bank's capacity, and you can compare it to the manufacturer's specifications to see how much the capacity has degraded over time.

You can repeat this process with different power contracts and current levels to see how the power bank performs under different conditions, and to identify any issues with its energy delivery capabilities. For example, you may find that the power bank delivers less energy at higher current levels, which could indicate that the batteries are degrading or that there are issues with the power delivery circuitry.

:::tip
Remember that a power bank's stated capacity is usually given in mAh at a specific voltage (often 3.7V, which is the nominal voltage of the internal lithium-ion batteries). This doesn't mean that the power bank will deliver that capacity at the USB output voltage (5V, 9V, etc.), due to the efficiency losses in the voltage conversion process. When testing a power bank's capacity, it's important to take into account the voltage at which you are drawing power, and to convert the measured energy back to mAh at the nominal voltage if you want to compare it to the manufacturer's specifications.
:::

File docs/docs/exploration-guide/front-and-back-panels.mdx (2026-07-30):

---
sidebar_position: 2
---

import frontPanel from '@site/static/img/drpd-front-panel.png';
import frontPanel2x from '@site/static/img/drpd-front-panel@2x.png';
import backPanel from '@site/static/img/drpd-back-panel.png';
import backPanel2x from '@site/static/img/drpd-back-panel@2x.png';

# Front and back panels

Dr. PD separates the USB-PD connection under test from its host connection and
bench interfaces. The front panel carries the two USB-C test ports, VBUS access,
and the CC monitoring output. The back panel carries the host USB connection and
the configurable sync output.

## Front panel

Front panel of Dr. PD showing USB-C Ports 1 and 2, positive and negative VBUS banana jacks, and the CC OUT connector

### Port 1 — Sink Mode DUT

Port 1 is the primary USB-C port for the device under test. Connect a USB-PD
source here when using Dr. PD in
[**Sink mode**](../how-to/operating-as-sink.mdx). Dr. PD can then discover the
source's capabilities, request a supported power contract, capture the USB-PD
exchange, and measure VBUS voltage and current.

Port 1 is also one side of the pass-through connection in
[**Observer mode**](../how-to/observing-connection.mdx).

:::warning
Before testing high-power or unfamiliar devices, read the
[important warnings and safety precautions](../important-warnings.mdx).
:::

### Port 2 — USB-C pass-through

Port 2 is the other side of the USB-C pass-through path. In **Observer** mode,
connect Dr. PD inline between a source and a sink using Ports 1 and 2. Dr. PD
then observes their USB-PD communication and measures the power flowing through
the connection.

:::tip
In Observer mode, both ports are bidirectional, so the source
and sink can be connected to either port. They can also swap power roles while
remaining connected (as required by the USB-PD spec).

The power diagram in the control software will show the direction in which
power is flowing, and the Message Log will show which device is currently
acting as the source and which is acting as the sink.
:::

In **Sink** mode, Port 2 is disconnected from the USB-PD bus and VBUS line. Even
with that lockout, it's a good idea to avoid connecting a USB-PD source to Port 2
to prevent accidental power delivery to it.

### VBUS banana jacks

The positive and negative banana jacks provide access to VBUS. In Sink mode,
use them to connect an external electronic load, a meter, or other suitably
rated bench equipment to the negotiated supply. In Observer mode, use them to
measure the voltage and current flowing through the USB-C connection.

:::important
Always observe the polarity and the limits printed on the panel: **60 V maximum and
6 A maximum** at the connectors. Dr. PD's specified VBUS measurement range is
0–60 V and ±6 A; the supported USB-PD sink request is also limited by
the source, cable, negotiated contract, and applicable power rating. Configure
OVP and OCP before connecting an unfamiliar source or load.
:::

### CC OUT

CC OUT is a dedicated monitoring tap for the active USB-C Configuration Channel
signal. Connect it to suitably rated oscilloscope or logic-analyzer equipment
when you want to compare the physical CC waveform with decoded messages or the
SYNC output.

:::tip
Dr. PD automatically accounts for cable orientation and exposes the correct CC
connection on both ports. Therefore, the CC OUT signal always corresponds to the
active CC line on the USB-C connection under test.
:::

## Back panel

Back panel of Dr. PD showing the SYNC connector and HOST USB-C port

### SYNC

SYNC is the configurable hardware trigger output. Connect it to an oscilloscope,
logic analyzer, or other compatible instrument to correlate an external capture
with events such as packet starts, message completion, hard resets, or protocol
errors.

The SYNC connector is limited to **3.3 V and 5 mA**. Its pulse behavior, event,
threshold, and repeat settings are configured in the control software. See
[Using triggers and the sync output](../how-to/using-triggers.mdx) for setup and
timing considerations.

### HOST

The HOST USB-C port powers Dr. PD and connects it to the control computer. Use a
USB-C cable that supports USB 2.0 data, not a charge-only cable. Open the Dr. PD
control software in Chrome or Edge before connecting the instrument, then pair
it when prompted.

The host connection is separate from Ports 1 and 2: attach the computer here,
and reserve the front USB-C ports for the USB-PD connection under test.

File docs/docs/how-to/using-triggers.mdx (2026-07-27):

# Using triggers and the sync output

Dr. PD features a sync output on the back panel that can be used to synchronize external devices with specific events within a USB-PD connection. For example, you can connect an oscilloscope to both the CC and sync output to visualize the precise timing of a device's signalling, identify runt pulses, or measure the duration of specific events.

## Sync modes

The sync output can be configured to use one of four modes:

- Pulse High: The sync output pulses high for a configured duration when the specified event occurs.
- Pulse Low: The sync output pulses low for a configured duration when the specified event occurs.
- Toggle: The sync output toggles its state (from high to low or low to high) each time the specified event occurs.
- Pull-Down: The sync output remains high-impedance by default, then pulls down for a configured duration when the specified event occurs.

For Pulse High, Pulse Low, and Pull-Down, you can configure the pulse width in microseconds. Toggle ignores the pulse width.

:::danger
When using the pull-down trigger mode, ensure that the sync port is not connected to a voltage that exceeds its specifications, as this could damage your Dr. PD unit.

The sync port is limited to 3.3 V and 5 mA. It includes a series resistor to limit current, and a shunt diode to protect against voltage spikes, and so can resist brief exposure to higher voltages, but it is not designed to handle continuous exposure to voltages above 3.3 V.
:::

## Configuring triggers

You can configure the sync mode and trigger events in the control app by selecting **Trigger → Configure...** from the menu. This will open a dialog where you can choose the desired trigger mode and specify which events should activate the sync output.

You can trigger on the following events:

- **Preamble start:** Triggers at the very beginning of a USB-PD communication, when the preamble is transmitted.
- **SOP start:** Triggers at the start of a Start of Packet (SOP) transmission, which is the point when the first bit of the packet is sent.
- **Header start:** Triggers at the start of the packet header, which is the point when the first bit of the header is sent.
- **Data start:** Triggers at the start of the data payload, which is the point when the first bit of the data is sent. Note that this trigger will not activate for packets that do not contain a data payload, such as control messages.
- **Message Complete:** Triggers at the end of a USB-PD communication, when the last bit of the packet is transmitted and the communication is complete.
- **Hard Reset:** Triggers when a Hard Reset signal is detected on the CC line, which indicates a reset of the USB-PD communication.
- **Invalid K-Code:** Triggers when an invalid K-code is detected in the USB-PD communication, which can indicate a communication error or a non-compliant device.
- **CRC Error:** Triggers when a CRC error is detected in the USB-PD communication, which can indicate data corruption or a communication issue.
- **Timeout Error:** Triggers when a timeout occurs during the USB-PD communication, which can indicate a communication failure or a non-responsive device.
- **Runt Pulse:** Triggers when a runt pulse is detected on the CC line, which can indicate a signal integrity issue or a non-compliant device.
- **Any Error:** Triggers when any of the above errors (Invalid K-Code, CRC Error, Timeout Error) are detected in the USB-PD communication.

You can also trigger based on the sender of a packet, and filter on up to 8 specific message types.

:::info
Not all event types can be filtered by sender or message type, because Dr. PD needs to successfully receive a full header in order to determine which device sent it or what kind of message it represents.
:::

## Trigger latency

The trigger mechanism is managed in firmware, and there is a small—but not negligible—amount of latency between the occurrence of the specified event and the activation of the sync output caused by the time it takes for the firmware to process and decode the USB-PD communication stream. This latency is typically less than 30µs, but can vary based on the complexity of the communication and the specific events being triggered on. When using the sync output for precise timing measurements, it's important to take this latency into account.

## Using threshold and autorepeat

Certain events can occur multiple times during a USB-PD negotiation, and so it might be convenient to only trigger on the nth occurrence of an event, or to automatically repeat the trigger every n occurrences. For example, you might want to trigger on the 3rd SOP start event, which would correspond to the 3rd packet in a negotiation, or you might want to trigger on every 5th SOP start event.

You can configure these options in the trigger configuration dialog. The threshold option allows you to specify that the trigger should only activate on the nth occurrence of the selected event(s). The Auto-repeat option allows you to specify that the trigger should automatically repeat every n occurrences of the selected event(s) after the initial trigger.

## Resetting the trigger

Under normal circumstances, the trigger will stay active until you manually reset it by clicking on **Trigger → Reset** from the menu or pressing the `R` key. You can see the status of the trigger in the header under “Sync State,” which will show as “Triggered” in red when the trigger has been activated.

A notable exception to this behaviour occurs when autorepeat is set. In this case, the trigger will automatically reset itself after each activation and will be ready to trigger again on the next occurrence of the specified event(s) based on the autorepeat configuration.

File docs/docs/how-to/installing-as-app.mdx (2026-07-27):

---
sidebar_position: 6
---

# Installing Dr. PD as an app

Dr. PD runs in Chrome or Edge, but supported browsers can also install the
control software as a standalone app. This gives Dr. PD its own app window and
launcher entry while keeping the same browser-based USB access model.

## Install from the Help menu

After opening the control software in Chrome or Edge, choose **Help → Install
Dr. PD as app...** and follow the browser prompt.

This does not install a driver or change how Dr. PD communicates with your
computer. Pairing, USB permissions, and device access still work through the
browser. The installed app is simply another way to launch the same control
software.

## When the menu item appears

The install menu item is shown only when the browser reports that Dr. PD can be
installed. It may be hidden when:

- The app is already installed.
- Dr. PD is already running in standalone app mode.
- The current browser, URL, or browser state does not offer web-app
  installation.

If the menu item is not visible, you can still use Dr. PD normally from Chrome
or Edge.

## After installation

Launch Dr. PD from the app entry created by your operating system or browser.
If your device is already paired, the app can reconnect to it from the Device
menu. If it is not paired yet, choose **Device → Pair new device...** and
approve the browser USB permission prompt.

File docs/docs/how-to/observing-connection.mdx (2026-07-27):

---
sidebar_position: 1
---

# Observing a USB connection

In _Observer Mode,_ Dr. PD can be used to observe and analyze the USB-PD communication between two USB-C devices without interfering with the connection. This is useful for debugging and understanding the behavior of USB-PD devices, as well as for learning about the USB-PD protocol.

## Set up

In order to observe a USB connection, you will need to connect Dr. PD inline between two devices, and this requires two USB-C cables.

The observation mechanism is bidirectional, and so you can connect each device at either end, regardless of which one is going source and sink power (in fact, in some cases, the source and sink roles may change dynamically during the connection, and Dr. PD will be able to observe this as well).

### Picking the right cables

Since you need to connect _two_ devices to Dr. PD, you will need two USB-C cables. The USB-PD protocol is not designed for this kind of operation—in many configurations, the cable incorporates a chip called an [e-marker](https://en.wikipedia.org/wiki/USB-C#E-marker) that actively participates in the communication between the devices, and there is no provision for two distinct cables to be part of the same connection.

Therefore, it is best if one of the cables in the connection chain is a simple, passive USB-C cable, without an e-marker chip. This fools the two devices into thinking they are connected through a single cable, and prevents any issues that may arise from having two e-markers in the connection. The other cable can be any USB-C cable, including one with an e-marker.

Note that it is using two e-marked cables may still work, but in our experience it can cause weird issues as both e-markers try to respond to being interrogated from the devices, and the devices may get confused about the capabilities of the connection. If you have two e-marked cables and are experiencing issues with observing a connection, try swapping one of them out for a passive cable and see if that resolves the issue.

## Entering observer mode

To enter observer mode, select **Mode → Observer** from the menu, or press the `O` key on your keyboard. You should see the MODE indicator in the control app's header change to "Observer," and the STATUS indicator change to reflect the current conditions of the connection:

- If no devices are detected at either end, the STATUS indicator will read "Unattached.” This can also occur if a device that is only capable of acting as a sink is attached at one end, since Dr. PD is not able to detect a connection in that case.
- If a device that is capable of acting as a source is detected at one end, and the other end is unattached, the STATUS indicator will read "Source Found."
- When both a source and a sink are detected and they have established a USB-PD connection, the STATUS indicator will read "Attached," and the VBUS voltage and PROFILE indicators will show the current power contract between the devices.

## Observing the connection

Once you have successfully entered observer mode, you can perform various actions on the source and sink devices:

- Capture USB-PD messages and VBUS voltage and current measurements in real time
- Troubleshoot a connection that is not working as expected
- Discover the capabilities of your devices and cables
- Perform energy measurements and power profiling of your devices

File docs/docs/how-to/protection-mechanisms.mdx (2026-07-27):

# Using Dr. PD's protection mechanisms

The USB-PD protocol includes a set of safety mechanisms that are designed to protect both the source and sink devices from damage in case of abnormal conditions, such as overvoltage, overcurrent, or short circuits. These have their limitations, but are normally “good enough” for most applications.

Dr. PD is designed to let you explore and test USB-PD devices in ways that are not always compatible with these protection mechanisms, and so it implements its own set of protections that are designed to work in tandem with their native counterparts, and to allow you to safely test and characterize USB-PD devices without risking damage to Dr. PD itself or to the devices you are testing.

:::danger
While Dr. PD's protection mechanisms are designed to prevent damage to Dr. PD and to the devices you are testing, they are not foolproof, and there is always a risk of damage when testing USB-PD devices, especially if you are testing at high power levels or with devices that have unknown or poorly implemented protection mechanisms.

Therefore, it's important to always take appropriate safety precautions when testing USB-PD devices with Dr. PD, such as using high-quality cables and connectors, making sure that your devices are on a non-flammable surface, and keeping a fire extinguisher nearby just in case. We also recommend not leaving Dr. PD unattended while testing, especially when testing at high power levels or with devices that have unknown or poorly implemented protection mechanisms.
:::

## Overvoltage and overcurrent protection

Dr. PD implements its own set of configurable overvoltage and overcurrent protections. These protections are designed to exhibit a very specific set of behaviours:

- They act as on/off switches that cut the power delivery between ports 1 and 2 and between port 1 and the banana connectors when triggered. Dr. PD does not implement any kind of current limiting or voltage clamping behavior, and instead relies on cutting the power delivery to protect itself and the devices you are testing.
- They are implemented in firmware; while this means that they remain active even when Dr. PD is not connected to a host device, it also means that there is a small delay between the moment when the overage condition occurs and when the protection mechanism is triggered—typically on the order of 100µs.
- They have no built-in tolerance, and will trigger as soon as the voltage or current exceeds the configured threshold.
- They are bidirectional, and will cut the power delivery in both directions between ports 1 and 2 and between port 1 and the banana connectors when triggered. This means that if you have a device connected to port 2 or to the banana connectors while testing a source device on port 1, they will also be protected by the overvoltage and overcurrent protections of Dr. PD.
- Once triggered, they will _never_ reset automatically, and will require a manual reset by the user in order to resume normal operation. This is to prevent any kind of “auto-retry” behaviour that could potentially cause damage to Dr. PD or to the devices you are testing.

You can configure the overvoltage and overcurrent protection thresholds in the control app by selecting **Protection → Set thresholds...** to open **OVP/OCP settings**. The thresholds are set in terms of voltage and current levels, and you can set them to any values that are appropriate for your tests, as long as they are within the limits of Dr. PD's hardware (60 V and 6 A).

When a protection mechanism is triggered, the OVP or OCP indicator in the control app's header will flash red until you reset it. You can reset the protection mechanism by selecting **Protection → Reset** from the menu.

:::info
The OVP/OCP thresholds that you set in the control app are stored in non-volatile memory on Dr. PD, and will persist across power cycles. This means that if you set a threshold and then power cycle Dr. PD, the threshold will still be in effect when you power it back on. This can be useful for ensuring that your tests are always protected by the same thresholds, even if you forget to set them before each test, but it also means that you should be careful when setting the thresholds, and make sure to set them to appropriate values for your tests in order to avoid accidentally triggering the protection mechanisms and having to reset them before you can resume testing.
:::

## Port 2 lock-out

In addition to the overvoltage and overcurrent protections, Dr. PD also implements a port 2 lock-out mechanism that is designed to protect any device that you might have inadvertently left connected to port 2 while testing a source device on port 1 in Sink mode.

When the port 2 lock-out is enabled, Dr. PD will disconnect the USB-PD bus and the VBUS line from port 2, effectively preventing any power delivery or communication between port 1 and port 2. This means that if you have a device connected to port 2 while testing a source device on port 1, it will be protected from any potential damage that could occur if the source device were to malfunction or if you were to accidentally set inappropriate overvoltage or overcurrent thresholds.

## Reverse polarity protection

The banana connectors also feature a reverse polarity protection mechanism that is designed to prevent damage to Dr. PD and to the devices you are testing in case you accidentally connect the positive and negative of an external power source or load in reverse while testing a source device on port 1.

When the reverse polarity protection is triggered, Dr. PD will disconnect the VBUS line from the banana connectors, effectively preventing any power delivery between both ports and the banana connectors. There is no indication in the control app when the reverse polarity protection is triggered, but you will notice that the VBUS voltage on the banana connectors will drop to 0V, and that any devices connected to the banana connectors will stop receiving power.

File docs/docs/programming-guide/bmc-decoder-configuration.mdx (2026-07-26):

---
sidebar_position: 40
title: BMC decoder configuration
---

# BMC decoder configuration

Dr. PD exposes advanced physical-layer controls through **Device → Calibrate → Internal settings…**.
These controls tune the CC comparator reference generated by PWM. Incorrect values can stop
Dr. PD from decoding USB Power Delivery traffic, so the app displays a safety warning before
opening the settings. Selecting **Do not show this again** suppresses that warning only in the
current browser profile.

| Setting | Default | Allowed values | Unit |
| --- | ---: | --- | --- |
| CC reference voltage | 0.70 | 0.20–2.50 in 0.05 increments | V |
| VREF PWM frequency | 100000 | 10000–500000 in 1000 increments | Hz |

Edits remain local until **OK** is selected. Accepted changes apply immediately and persist in
device flash, so they remain active after restart. Each **Reset** button stages the
firmware build-time default; select **OK** to save it.

If communication becomes unreliable, reconnect Dr. PD and restore both defaults through the same
dialog or use the corresponding SCPI `:RESet` commands. Firmware rejects values outside the listed
ranges and increments.

Python callers can use `device.system.configuration.bmc_decoder`; TypeScript callers can use
`device.system.configuration.bmcDecoder`. See generated API and SCPI references for exact methods
and commands.

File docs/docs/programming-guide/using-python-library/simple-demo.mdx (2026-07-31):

---
sidebar_position: 20
---

# Simple Python demo

This script discovers Dr. PD devices, connects to the first device, reads basic status, checks capture state, and disconnects cleanly.

It does not request a sink power contract or change VBUS behavior.

```python
import asyncio

from t76.drpd.device import find_drpd_devices

async def main() -> None:
    devices = find_drpd_devices()
    if not devices:
        print("No Dr. PD devices found.")
        return

    device = devices[0]
    await device.connect()

    try:
        info = await device.system.identify()
        mode = await device.mode.get()
        mode_status = await device.mode.get_status()
        capture_status = await device.capture.get_status()
        analog = await device.analog_monitor.get_status()

        device_label = device.name or f"{info.model} {info.serial_number}"
        print(f"Connected to {device_label}")
        print(f"Model: {info.model}")
        print(f"Serial number: {info.serial_number}")
        print(f"Firmware version: {info.firmware_version}")
        print(f"Hardware revision: {info.hardware_revision or 'unknown'}")
        print(f"Mode: {mode.value}")
        print(f"Mode status: {mode_status.value}")
        print(f"Capture: {capture_status.value}")
        print(f"VBUS: {analog.vbus:.3f} V, {analog.ibus:.3f} A")
    finally:
        await device.disconnect()

if __name__ == "__main__":
    asyncio.run(main())
```

## Running the script

Save the file as `drpd_demo.py`, then run:

```bash
python drpd_demo.py
```

If the browser control app is connected to Dr. PD, choose
**Device → [device name] → Disconnect** and wait for it to release the USB
interface before running the script. Closing the app or browser tab is a
fallback. Only one application can claim the device interface at a time.

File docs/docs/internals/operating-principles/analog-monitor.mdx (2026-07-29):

---
title: Analog Monitor
sidebar_position: 3
---

import ComponentRef from '@site/src/components/ComponentRef';

# Analog Monitor

The Analog Monitor section measures VBUS voltage and current, the CC-line voltages of both USB-C ports, system ground, the 1.65 V current-sense reference, the +3.3 V supply rail, and the separate 3.3 V ADC reference voltage.

## VBUS current monitoring

The shunt resistor <ComponentRef revision="R2605-A" reference="R202" /> sits in series with the VBUS line at Port 1, producing a 5mV/A voltage drop proportional to the current flowing through it.

<ComponentRef revision="R2605-A" reference="U303" />, an INA240A2 bidirectional current-sense amplifier, amplifies this voltage drop by a factor of 50V/V. At Dr. PD's maximum supported current of 6A, the 30mV voltage drop across <ComponentRef revision="R2605-A" reference="R202" /> therefore corresponds to a 1.5V change at the output of <ComponentRef revision="R2605-A" reference="U303" />. This is sufficient to cover the 0-5A range of the USB-PD specification, with some headroom to make characterizing the response of DUTs to overcurrent events.

Since the current can flow in both directions, <ComponentRef revision="R2605-A" reference="U303" /> is biased with a 1.65 V reference voltage generated by <ComponentRef revision="R2605-A" reference="U304" />, a TL432B adjustable shunt regulator. This allows the output of <ComponentRef revision="R2605-A" reference="U303" /> to swing above and below the 1.65 V reference voltage. Across Dr. PD's supported current range of −6 A to +6 A, the designed output range is approximately 0.15 V to 3.15 V, suitable for the microcontroller's ADC to read and process.

We chose <ComponentRef revision="R2605-A" reference="R202" /> to minimize the burden voltage on the VBUS line while still producing a reasonable voltage drop for <ComponentRef revision="R2605-A" reference="U303" /> to amplify. To minimize noise and maximize the accuracy of the circuit, we use Kelvin connections of exactly the same length between the shunt resistor and the amplifier.

Despite this, there are still enough factors at play that reduce the absolute accuracy of the current measurement, including amplifier offset voltage, resistor and shunt reference tolerances, and PCB trace resistance. 

To account for these errors, factory calibration records the raw current reading at 0.5 A intervals from 0 A through 6 A. The firmware stores this calibration table in the device's non-volatile memory. During normal operation, it determines the calibrated current magnitude by linearly interpolating between the two surrounding table entries, then reapplies the measured current direction. During each VBUS acquisition, the firmware also samples system ground and the 1.65 V reference. It uses the ground sample as the ADC baseline and the measured 1.65 V reference as the zero point for the current measurement.

## VBUS voltage monitoring

Resistors <ComponentRef revision="R2605-A" reference="R301" /> and <ComponentRef revision="R2605-A" reference="R302" /> form a voltage divider that scales VBUS by a theoretical factor of 1/18.405, producing a 0-3.26V swing for the 0-60V range that Dr. PD supports. Since USB-PD maxes out at 48V when in EPR mode, this is more than sufficient to cover the entire range of voltages that can be applied to the VBUS line. The resulting sense voltage is buffered by <ComponentRef revision="R2605-A" reference="U301" label="U301A" />, and fed to the ADC of the microcontroller for processing.

Naturally, the voltage divider is not perfect, and the actual scaling factor will be different based on tolerances, voltage offsets, device on-time, temperature, and so on. Just like the current-sensing signal, VBUS voltage is factory-calibrated using a persisted correction table with one entry for each raw integer-voltage bucket from 0 V through 60 V. 

For readings of 1 V or greater, the firmware linearly interpolates between the two surrounding correction entries and adds the result to the raw scaled voltage. Readings below 1 V bypass the correction table because the calibration fixture cannot provide a reliable calibration point at 0 V due to the reference voltage to <ComponentRef revision="R2605-A" reference="U303" /> bleeding through.

## Voltage monitoring multiplexer

Since they are critical measurements for which the highest accuracy is required, current and voltage sensing on VBUS both have separate circuitry that feeds directly into a dedicated ADC channel of the microcontroller.

Several other voltages in the system are not as critical, and so they are multiplexed using <ComponentRef revision="R2605-A" reference="U302" />, a 74HC4051D analog switch. The microcontroller selects an input using the `CC_VSENSE_x` signals. <ComponentRef revision="R2605-A" reference="U301" label="U301B" /> buffers the selected output from <ComponentRef revision="R2605-A" reference="U302" />, after which <ComponentRef revision="R2605-A" reference="R303" /> and <ComponentRef revision="R2605-A" reference="R304" /> scale it by approximately 0.662 before it reaches the microcontroller's ADC. This allows the measurement path to accommodate inputs of up to approximately 5 V within the ADC's 3.3 V range.

In addition to the individual CC lines on both ports, the multiplexer monitors system ground, the 1.65 V current-sense reference, the +3.3 V supply rail, and the separate 3.3 V ADC reference voltage. The +3.3 V channel measures the system supply rail, while the ADC-reference channel measures the voltage used as the ADC's reference.

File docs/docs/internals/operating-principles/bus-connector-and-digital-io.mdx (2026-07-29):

---
title: Bus Connector and Digital IO
sidebar_position: 5
---

import ComponentRef from '@site/src/components/ComponentRef';

# Bus Connector and Digital IO

This section of the schematic is responsible for handling the interconnection between the two CC lines on the USB-C ports, as well as all digital USB-PD communications.

## Cable orientation detection

Even though USB-C cables feature two CC lines, only one of them is used for communication at a time; the other is either left floating or used to power the cable's e-marker. 

Thus, when a cable is connected to Port 1 and the device is in Sink mode, it needs to figure out which CC line is actually usable for communication. In Observer mode, the device needs to figure out which CC line is being used _by either port,_ and then connect them accordingly so that the attached devices can communicate with each other.

To accomplish this dance, Dr. PD uses three small 2:1 multiplexers, <ComponentRef revision="R2605-A" reference="U503" />, <ComponentRef revision="R2605-A" reference="U504" />, and <ComponentRef revision="R2605-A" reference="U505" />. Each of these multiplexers has two inputs and one output, and can be configured to connect either input to the output:

- <ComponentRef revision="R2605-A" reference="U503" /> is capable of redirecting either CC line from Port 1 on to one of the inputs of <ComponentRef revision="R2605-A" reference="U504" />.
- <ComponentRef revision="R2605-A" reference="U505" /> is likewise capable of redirecting either CC line from Port 2 on to the other input of <ComponentRef revision="R2605-A" reference="U504" />.
- <ComponentRef revision="R2605-A" reference="U504" /> is then responsible for either connecting the two selected CC lines together or leaving them isolated from each other.

The cable orientation mechanism works in slightly different ways depending on whether the device is in Sink mode or Observer mode.

### Sink mode

In Sink mode, <ComponentRef revision="R2605-A" reference="U504" /> is always configured to isolate the two CC lines from each other, since only Port 1 is used for communication. This prevents a device or cable connected to Port 2 from interfering with the signaling between Port 1 and Dr. PD's own internal transmitter.

When Dr. PD enters Sink mode, the PD Role Resistors circuit first places the appropriate pull-down resistor on both CC lines of Port 1. The Analog Monitor then measures both lines. If a source is connected, its pull-up resistor and Dr. PD's pull-down resistor establish a characteristic voltage on the active CC line. The firmware currently recognizes an attached source when the measured CC voltage is greater than 0.75 V and less than 2.0 V, then debounces the detection before selecting that line for communication. The firmware then configures <ComponentRef revision="R2605-A" reference="U503" /> to route that line to Dr. PD's receiver and transmitter. If the source is working correctly, it starts sending PD messages that can then be processed by the firmware.

### Observer mode

In Observer mode, <ComponentRef revision="R2605-A" reference="U504" /> is initially configured to isolate the two ports. The firmware activates a state machine that examines all four CC lines for one whose voltage exceeds the configured 0.75 V source-detection threshold. After debouncing the detection, it records that line and port as the source candidate, then cycles through the two CC lines of the other port, connecting them through <ComponentRef revision="R2605-A" reference="U504" /> to the selected CC line of the source port in turn until it finds one that pulls down the line to a voltage consistent with the presence of a sink device's 5.1kΩ pull-down resistor. Once it finds a valid CC line on the sink port, it locks that as the port choice for the sink, and leaves <ComponentRef revision="R2605-A" reference="U504" /> configured to connect the two selected CC lines together.

The process has several failure modes, which the firmware handles by backing the state machine off of its port assignments as needed. This may be necessary, for example, if one or both of the devices attached to the USB-C ports are dual-role devices, in which case they alternate their connectivity between source and sink mode, and several attach cycles may be required until both devices align in a compatible way.

:::info
Note that this is a non-standard process that is not part of the USB-PD specification, since the specification assumes that the two devices are connected directly to each other, and thus can communicate with each other directly. 

Dr. PD defeats this assumption by interposing itself between the two devices and requiring two cables, which may be of different lengths and orientations, and thus may not be able to communicate with each other directly.
:::

## CC edge detector

<ComponentRef revision="R2605-A" reference="U502" label="U502A" /> converts the analog CC waveform into the digital `CC_IN` signal by comparing it with a programmable reference voltage. Its output changes state on both upward and downward threshold crossings. The firmware treats the first low-to-high transition after an idle period as the start of a frame, then measures the time between successive falling and rising transitions to decode the BMC signal. The reference is created by feeding a PWM signal from the firmware into <ComponentRef revision="R2605-A" reference="R508" />, <ComponentRef revision="R2605-A" reference="R509" />, <ComponentRef revision="R2605-A" reference="R510" />, <ComponentRef revision="R2605-A" reference="C503" />, <ComponentRef revision="R2605-A" reference="C504" />, and <ComponentRef revision="R2605-A" reference="C506" />, which, together with <ComponentRef revision="R2605-A" reference="U501" label="U501A" />, form a second-order active low-pass filter.

By default, the reference voltage is set to 0.7 V, which has proven to work with the vast majority of the USB-C devices that we have tested. It can be adjusted through **Device → Calibrate → Internal settings…** in the frontend's BMC Decoder configuration or by using the corresponding SCPI command.

## CC transmission circuit

The last bit of functionality contained in this section of the schematic is used by the firmware when it needs to transmit data on the CC lines. <ComponentRef revision="R2605-A" reference="R501" />, <ComponentRef revision="R2605-A" reference="R502" />, and <ComponentRef revision="R2605-A" reference="R503" /> form a simple voltage divider that generates a reference voltage of about 1.1V. This, in turn, is buffered by <ComponentRef revision="R2605-A" reference="U501" label="U501B" />, providing a stiff voltage source that represents the “high” state of the CC line, as required by the USB-PD specification.

The transmitter uses separate `CC_OUT` and `CC_OUT_EN` signals. During transmission, `CC_OUT` carries the BMC waveform while `CC_OUT_EN` enables the analog output stage. Between messages, the firmware deasserts `CC_OUT_EN`, placing the transmitter in a high-impedance state so that it does not disturb the CC line's normal bias voltage.

`CC_OUT` controls two complementary current-mirror branches. When `CC_OUT` is low, the PNP pair <ComponentRef revision="R2605-A" reference="Q502" /> and <ComponentRef revision="R2605-A" reference="Q505" /> sources current from the buffered 1.1 V reference into the transmitter output. When `CC_OUT` is high, the NPN pair <ComponentRef revision="R2605-A" reference="Q504" /> and <ComponentRef revision="R2605-A" reference="Q503" /> sinks current from the output to ground. <ComponentRef revision="R2605-A" reference="R14" />, <ComponentRef revision="R2605-A" reference="R504" />, and <ComponentRef revision="R2605-A" reference="R505" /> establish the reference currents. By charging and discharging the CC-line capacitance with controlled currents, the mirrors limit the waveform's slew rate, reducing high-frequency energy, ringing, and EMI while producing edges compatible with the USB-PD physical-layer requirements.

There is one more wrinkle to deal with: The CC lines are normally held at a voltage between approximately 0.9V and 1.5V by the combination of the source's pull-up resistor and the sink's pull-down resistor. Because the transmission current mirrors are fairly low impedance, this means that they would normally tend to pull down the line voltage below the normal range, which might inhibit communication on the line or even be interpreted as a disconnection event.

<ComponentRef revision="R2605-A" reference="Q501" /> connects the current-mirror output to the selected CC line only while transmission is enabled. <ComponentRef revision="R2605-A" reference="R506" /> pulls <ComponentRef revision="R2605-A" reference="Q501" />'s gate to ground by default, keeping it off and isolating the transmitter. When the firmware asserts `CC_OUT_EN`, the signal drives <ComponentRef revision="R2605-A" reference="Q501" />'s gate through <ComponentRef revision="R2605-A" reference="R16" />, turning it on and allowing the sourcing and sinking branches to drive the CC line. Deasserting `CC_OUT_EN` turns <ComponentRef revision="R2605-A" reference="Q501" /> off and returns the transmitter to its high-impedance state.

:::note
<ComponentRef revision="R2605-A" reference="Q501" /> may appear backwards compared with a typical N-channel MOSFET switch, but its orientation is deliberate: when <ComponentRef revision="R2605-A" reference="Q501" /> is off, its body diode is oriented to prevent current from entering the output stage from the CC line. When <ComponentRef revision="R2605-A" reference="Q501" /> is on, its channel allows the transmitter to both source and sink current.
:::

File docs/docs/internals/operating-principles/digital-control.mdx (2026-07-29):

---
title: Digital Control
sidebar_position: 6
---

import ComponentRef from '@site/src/components/ComponentRef';

# Digital Control

This section of the schematic contains the digital control logic for the system. It is based on the RP2354, a member of the same RP2350 microcontroller family as the RP2350A used in the Raspberry Pi Pico 2. Unlike the Pico 2's RP2350A and external flash arrangement, the RP2354 uses a different package and integrates flash memory.

With some minor differences, the circuitry here is essentially the same as that found in the Pico 2 reference design. We have replaced the Pico 2's buck converter with a linear regulator to reduce noise, since this is more important than power conversion efficiency in our design.

## Hardware revision detection

GPIO24 is strapped to ground on R2605-A. During startup, the firmware configures this input with an internal pull-up: a low level identifies R2605-A, while an unstrapped high level identifies the earlier R2603-A revision. The detected revision determines whether the firmware uses R2605-A's single-output-plus-enable BMC transmitter or the earlier dual-pin transmitter, and whether it enables the R2605-A status LED. The detected board revision can be queried with `SYSTem:HW:REVision?`.

## Reset and debug circuits

The <ComponentRef revision="R2605-A" reference="SW601" /> and <ComponentRef revision="R2605-A" reference="SW602" /> switches can be used to enter the RP2354's ROM USB boot mode and reset it, respectively. In the event of a firmware fault that “bricks” the device, hold <ComponentRef revision="R2605-A" reference="SW601" />, then press and release <ComponentRef revision="R2605-A" reference="SW602" /> to reset the RP2354 into BOOTSEL mode. You can then reflash the firmware using the Raspberry Pi Imager or other tools.

<ComponentRef revision="R2605-A" reference="J601" /> exposes the RP2354's SWD interface for debugging and programming. You can use a Raspberry Pi Pico or other SWD programmer to connect to this header and flash firmware or debug the device.

## Status LED

<ComponentRef revision="R2605-A" reference="LED601" /> can be used to debug the device. While it is not exposed on the front panel, it flashes a series of blinks to indicate the device's current status. The blink patterns are described in the [firmware's source code](https://github.com/T76-org/drpd/blob/main/firmware/lib/app/status_led.hpp).

## Voltage references

<ComponentRef revision="R2605-A" reference="U605" /> is a TL432B adjustable shunt regulator configured with a resistor divider to generate a nominal 3.3 V reference voltage for the RP2354's ADC. 

## ADC channels

As discussed in the [Analog Monitor section](./analog-monitor), two separate ADC channels are dedicated to VBUS voltage and current sense measurements, while a third one is used for all other analog measurements. We did this because VBUS measurements are the most critical for the device's operation, and we wanted to ensure that they would have the most direct and accurate paths to the ADC. The other analog measurements are less critical, and can tolerate a bit more noise and inaccuracy.

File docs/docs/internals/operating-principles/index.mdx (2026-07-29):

---
title: Operating principles
sidebar_position: 1
---

import ComponentRef from '@site/src/components/ComponentRef';

# Operating principles

In this section, we describe how Dr. PD's hardware is designed, with a focus on the principles that guide its development and operation.

## Basic philosophy

We wanted Dr. PD to be easy to use and reliable, but also open to experimentation and modification. To achieve this, we adopted a few key principles:

- **No protocol black boxes**: We implemented the USB-PD stack in firmware rather than relying on a dedicated USB-PD controller chip. The supporting CC, measurement, and power-control circuits use discrete or general-purpose components whose behavior can be understood from the schematic and their datasheets. This makes it easier to inspect, modify, and extend Dr. PD without being limited by the fixed capabilities of a dedicated controller.
- **Jellybean components**: We've used common components that are easy to source and replace from multiple vendors. Dr. PD is built almost entirely from standard parts. Where a function depends on a single-source part—most notably the RP2354 microcontroller—we favor devices that are widely available, feature open-source tooling, and are supported by a large community of developers.
- **Ease of repair**: Where practical, we've used large SMD packages—typically 1206 for passive components—and avoided packages that are difficult to solder or replace when suitable alternatives are available. To make troubleshooting easier, we also placed components on a widely-spaced grid and added plenty of test points for critical signals.

## Basic architecture

If you look at the [schematic](../interactive-diagram), you'll see that Dr. PD is built around 5 main functional blocks:

- **[USB Ports](./usb-ports)** (2xx-series components) defines the front-panel USB-C connectors, as well as the associated power switching and sensing circuitry.
- The **[Analog Monitor](./analog-monitor)** (3xx-series components) is responsible for measuring critical voltages and currents on VBUS and various signal lines.
- The **[PD Role Resistors](./pd-role-resistors)** (4xx-series components) contain two multiplexed sets of resistors that are used to configure the USB-PD role of the device in Sink mode (as well as a possible future Source mode). These resistors are switched in and out of the circuit by a pair of analog switches, which are controlled by the microcontroller.
- The **[Bus Connector and Digital IO](./bus-connector-and-digital-io)** (5xx-series components) is responsible for detecting the orientation of the USB-C cables in both front-panel ports, capturing CC line edges, and actively driving the CC output in Sink mode. It also provides a digital interface to the microcontroller for controlling the analog switches and reading the analog monitor.
- Finally, the **[Digital Control](./digital-control)** (6xx-series components) section contains the microcontroller and its associated circuitry, including internal power rails and voltage references.

To make it a bit easier to follow the logical layout of the system, 1xx-series components are all located in the main schematic sheet, while 2xx-6xx-series components are located in a separate sub-sheet for each functional block.

## Protection mechanisms

Dr. PD implements ESD protection on all exposed lines, including the front- and back-panel USB-C connectors, the CC OUTPUT port, and the SYNC port.

<ComponentRef revision="R2605-A" reference="D101" /> and <ComponentRef revision="R2605-A" reference="D102" /> are TVS diodes that protect the CC OUT and SYNC ports. The CC lines on ports 1 and 2 are similarly protected by <ComponentRef revision="R2605-A" reference="D501" />, while <ComponentRef revision="R2605-A" reference="D601" /> protects the USB 2.0 data and VBUS lines on the Host USB-C port.

<ComponentRef revision="R2605-A" reference="D301" /> is a 60 V stand-off TVS diode that provides a discharge path for transient overvoltage events on the VBUS line.

In addition to ESD protection, Dr. PD also implements reverse-polarity protection on the VBUS line; the P-channel MOSFET <ComponentRef revision="R2605-A" reference="Q101" /> is used to block current flow if the VBUS line is connected with the wrong polarity. Zener diode <ComponentRef revision="R2605-A" reference="D103" /> limits the gate-to-source voltage of <ComponentRef revision="R2605-A" reference="Q101" /> to around 12V, preventing damage to the MOSFET when the voltage on VBUS exceeds the maximum gate-to-source voltage of 20V, with extra headroom for safety. <ComponentRef revision="R2605-A" reference="R103" /> pulls <ComponentRef revision="R2605-A" reference="Q101" />'s gate toward ground. With correctly polarized VBUS, this produces a negative gate-to-source voltage that turns <ComponentRef revision="R2605-A" reference="Q101" /> on. If the banana connectors are reverse-polarized, <ComponentRef revision="R2605-A" reference="Q101" /> remains off and blocks current through the VBUS path.

Finally, <ComponentRef revision="R2605-A" reference="R101" /> and <ComponentRef revision="R2605-A" reference="R102" /> are used to limit current on the SYNC port. At a total of 20Ω, these resistors offer only limited protection, but this compromise is necessary because the port can be used to both drive a load and sink current from a pull-up resistor on the other end, and so it would be undesirable to increase their value further.

Additional protection is provided by bidirectional switches on both Port 1 and Port 2; these are controlled by the microcontroller and are used to disconnect ports when they are not in use and to implement Dr. PD's programmable [overvoltage and overcurrent protection](../../how-to/protection-mechanisms).

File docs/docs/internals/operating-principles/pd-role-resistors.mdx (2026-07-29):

---
title: PD Role Resistors
sidebar_position: 4
---

import ComponentRef from '@site/src/components/ComponentRef';

# PD Role Resistors

This section of the Dr. PD schematic allows the firmware to present one of several configurations on the CC lines of both USB-C ports, depending on the role that the device is currently playing in a USB-PD connection. 

By manipulating the `CC_ROLE_SEL_x` lines, the firmware can control the state of two identical multiplexers (<ComponentRef revision="R2605-A" reference="U401" /> and <ComponentRef revision="R2605-A" reference="U402" />) that select the appropriate resistors to present on the CC lines. The resistors present cover both sink and source roles in one of several configurations, as explained in the table that accompanies the schematic.

Resistors <ComponentRef revision="R2605-A" reference="R401" />, <ComponentRef revision="R2605-A" reference="R402" />, <ComponentRef revision="R2605-A" reference="R405" />, <ComponentRef revision="R2605-A" reference="R408" />, <ComponentRef revision="R2605-A" reference="R409" />, and <ComponentRef revision="R2605-A" reference="R410" /> pull down the multiplexer selection lines to ground, ensuring that the default input channel is Y0, which is floating.

<ComponentRef revision="R2605-A" reference="Q401" /> and <ComponentRef revision="R2605-A" reference="Q402" /> are gate drivers controlled by the `CC_VCONN_EN_x` signals. When enabled, they pull down the gates of the P-channel MOSFETs <ComponentRef revision="R2605-A" reference="U403" /> and <ComponentRef revision="R2605-A" reference="U404" />, which connect the 5 V supply to the corresponding CC lines to provide VCONN. In order not to place too high a burden on the host power supply, VCONN is only powerful enough to power a USB-C cable's e-marker, or a similar device that does not require more than about 5mA of current.

:::note
The capabilities of the multiplexer far exceed what is required for Dr. PD's current functionality, which only really uses <ComponentRef revision="R2605-A" reference="R403" /> and <ComponentRef revision="R2605-A" reference="R404" /> to present a 5.1kΩ resistor on the CC lines in Sink mode. 

The firmware's [`CCRoleManager`](https://github.com/T76-org/drpd/blob/main/firmware/lib/phy/cc_role_manager.hpp) already supports selecting the Off, Sink, E-marker, Source Default, Source 1.5 A, Source 3 A, and VCONN configurations on either CC line. These configurations can be exercised directly using test commands in test-enabled firmware. Dr. PD does not yet provide a complete product-level Source mode, which would also require the corresponding attachment, power-control, protocol, and policy behavior.
:::

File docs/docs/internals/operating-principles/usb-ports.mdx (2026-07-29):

---
title: USB Ports
sidebar_position: 2
---

import ComponentRef from '@site/src/components/ComponentRef';

# USB Ports

The USB Ports section of Dr. PD is responsible for defining the front-panel USB-C connectors and the associated power switching and sensing circuitry. 

In addition to the USB ports, it includes two back-to-back P-channel MOSFET VBUS power switches that isolate either USB-C port from the rest of the system when it is not in use and implement Dr. PD's programmable overvoltage and overcurrent protection.

The section also pulls out the CC lines from the USB-C connectors and routes them to the Bus Connector and Digital IO section, where they are used to detect the orientation of the USB-C cables in both front-panel ports, capture CC line edges, and actively drive the CC output in Sink mode.

## VBUS power switches

<ComponentRef revision="R2605-A" reference="Q202" /> and <ComponentRef revision="R2605-A" reference="Q205" /> form a bidirectional switch that is used to block VBUS from reaching the VBUS banana connector. The firmware acts on the gate of <ComponentRef revision="R2605-A" reference="Q201" /> to turn this switch on during normal operation and turns it off when the device is in Disabled mode or when the overvoltage or overcurrent protection is triggered. 

<ComponentRef revision="R2605-A" reference="D201" /> limits the magnitude of the gate-to-source voltage across <ComponentRef revision="R2605-A" reference="Q202" /> and <ComponentRef revision="R2605-A" reference="Q205" /> to approximately 12 V, protecting both MOSFETs from exceeding their maximum gate-to-source voltage rating of 20 V. When <ComponentRef revision="R2605-A" reference="Q201" /> is on, <ComponentRef revision="R2605-A" reference="R204" /> and <ComponentRef revision="R2605-A" reference="R205" /> limit the current flowing through <ComponentRef revision="R2605-A" reference="D201" /> and <ComponentRef revision="R2605-A" reference="Q201" /> to ground.

<ComponentRef revision="R2605-A" reference="R203" /> pulls the shared gates of <ComponentRef revision="R2605-A" reference="Q202" /> and <ComponentRef revision="R2605-A" reference="Q205" /> toward their shared source node. When <ComponentRef revision="R2605-A" reference="Q201" /> is off, this keeps their gate-to-source voltage near zero and holds both MOSFETs off. <ComponentRef revision="R2605-A" reference="C202" /> adds capacitance between the shared gate and source nodes of <ComponentRef revision="R2605-A" reference="Q202" /> and <ComponentRef revision="R2605-A" reference="Q205" />, slowing changes in their gate-to-source voltage and moderating the VBUS switching transition.

A similar bidirectional switch is formed by <ComponentRef revision="R2605-A" reference="Q204" /> and <ComponentRef revision="R2605-A" reference="Q206" />. Its purpose is to isolate Port 2 when the device is in Disabled or Sink mode so that a USB-C sink inadvertently left connected to Port 2 does not receive an unexpected voltage on its VBUS line. Like the other switch, it is controlled by the microcontroller and also serves as protection when an overvoltage or overcurrent event is detected.

These switches are bidirectional because, in a USB-PD connection, current can flow in both directions: Not only can source and sink be connected to either port in Observer mode, but they can also swap their roles at any time if they support dual-role power. This is less of a concern in Sink mode, but the [PD Role Resistors](./pd-role-resistors) section is designed to support a future Source mode, and so the switches must be able to handle current flowing in either direction anyway.

## CC line routing

The individual CC lines for both USB-C ports are routed to the Bus Connector and Digital IO section, where they are used to detect the orientation of the USB-C cables, capture CC line edges, and actively drive the CC output in Sink mode.

<ComponentRef revision="R2605-A" reference="R206" />, <ComponentRef revision="R2605-A" reference="R207" />, <ComponentRef revision="R2605-A" reference="R208" />, and <ComponentRef revision="R2605-A" reference="R209" /> provide weak pull-down paths for the CC lines, preventing them from floating when no stronger termination or active drive is present. Their 1 MΩ resistance is high enough to avoid materially affecting normal CC detection.

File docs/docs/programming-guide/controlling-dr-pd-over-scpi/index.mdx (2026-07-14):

---
sidebar_position: 10
sidebar_label: Overview
---

# Controlling Dr. PD over SCPI

Dr. PD exposes SCPI commands over two USB interfaces:

- **USBTMC** for standard instrument-control tools.
- **WinUSB** for the browser control app and host software that uses Dr. PD's framed control protocol.

Both interfaces execute the same SCPI command catalog. Choose the interface based on host software support, not command availability.

## USBTMC interface

USBTMC is the instrument-style interface. Use it when your host environment already understands USB Test and Measurement Class devices, or when you want to script Dr. PD like lab equipment.

USBTMC requests are passed directly into the SCPI interpreter. When a USBTMC transfer is marked complete, firmware finalizes the command by adding a newline. Query responses are returned on the USBTMC bulk IN endpoint, and service-request notifications are sent through the USBTMC interrupt endpoint when device status is pending.

Typical host flow:

1. Open the Dr. PD USBTMC interface from your instrument-control library.
2. Send one SCPI command or query per completed transfer.
3. Read the response for queries that end in `?`.
4. Poll `SYSTem:ERRor?` if a command failed or if you need to drain the error queue.

## WinUSB interface

WinUSB is the framed control interface used by the Dr. PD app-side protocol. It carries SCPI payloads inside Dr. PD frames rather than exposing raw instrument transfers.

Each WinUSB frame has a request type and tag. Command requests acknowledge with a command-ack frame when they complete without producing data. Query requests must produce a text or binary response frame. If a command request produces data, or a query request produces no response, firmware returns an error frame.

Supported WinUSB request types include:

- command request
- query request
- session reset request

WinUSB can also return protocol errors such as `Device busy`, `Unsupported frame`, `Command request produced data response`, and `Missing query response`.

## Command termination and responses

Send one complete SCPI command at a time. Firmware feeds received bytes into the SCPI interpreter and finalizes each completed transport request with a newline.

For text responses, Dr. PD appends a newline at the transport boundary. Binary responses are returned as binary payloads on the active transport.

Query commands end in `?` and return data. Non-query commands change device state and normally return no SCPI data. On WinUSB, this distinction is enforced by separate command and query request frame types.

## Interface arbitration

Only one SCPI transport owns the interpreter at a time. If USBTMC and WinUSB requests overlap, firmware rejects or ignores the second owner until the active request completes. WinUSB reports `Device busy` when it cannot acquire command ownership.

## Command reference

See the generated SCPI command reference pages, starting with [common commands](./reference/common), for commands grouped by top-level namespace.

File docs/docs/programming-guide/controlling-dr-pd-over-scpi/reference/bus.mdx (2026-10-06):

---
sidebar_position: 50
sidebar_label: BUS
---

# BUS Commands

:::info[Generated reference]
This page is generated from `firmware/lib/app/scpi.yaml`. Do not edit it by hand; update the catalog or generator instead.
:::

## Common parser errors

These parser-level errors can apply before a command handler runs.

| Code | Message | Meaning |
| --- | --- | --- |
| `-100` | Command error | Malformed command syntax or command not recognized by the SCPI interpreter. |
| `-102` | Syntax error | Unexpected token or separator in command input. |
| `-104` | Data type error | Parameter could not be parsed as required type. |
| `-109` | Missing parameter | Required parameter was omitted. |
| `-222` | Data out of range | Numeric parameter was outside supported range. |
| `-224` | Illegal parameter value | Parameter parsed correctly but value was not accepted for this command. |

## `BUS:CC:ROLE?`

**Type:** Query

**Syntax:**

```scpi
BUS:CC:ROLE?
```

### Accepted forms

| Form | Syntax |
| --- | --- |
| Long form | `BUS:CC:ROLE?` |
| Short form | `BUS:CC:ROLE?` |

Query the CC bus controller role

### Parameters

No parameters.

### Response

Returns query-specific data described above.

### Command-specific errors

No command-specific errors documented. Common SCPI parser errors may still apply.

### Source

- Catalog handler: `_queryCCBusControllerRole`
- Handler source: `firmware/lib/app/app_scpi_bus.cpp`

## `BUS:CC:ROLE`

**Type:** Command

**Syntax:**

```scpi
BUS:CC:ROLE
```

### Accepted forms

| Form | Syntax |
| --- | --- |
| Long form | `BUS:CC:ROLE` |
| Short form | `BUS:CC:ROLE` |

Set the CC bus role. CABLE_TEST requires R2605-A and persists as DISABLED; other roles persist normally.

### Parameters

| Name | Type | Values/default | Description |
| --- | --- | --- | --- |
| `role` | enum | `DISABLED`, `OBSERVER`, `SINK`, `CABLE_TEST` | The desired role for the CC bus controller. |

### Response

No SCPI data response. Successful command execution completes without a payload.

### Command-specific errors

| Code | Message | Meaning |
| --- | --- | --- |
| `-224` | Illegal parameter value | The role value was unsupported. |
| `-200` | Cable Test requires R2605-A | Extracted from handler implementation. |
| `-104` | Data type error | The role parameter was missing or was not parsed as a valid enumerated value. |

### Source

- Catalog handler: `_setCCBusControllerRole`
- Handler source: `firmware/lib/app/app_scpi_bus.cpp`

## `BUS:CC:ROLE:STATus?`

**Type:** Query

**Syntax:**

```scpi
BUS:CC:ROLE:STATus?
```

### Accepted forms

| Form | Syntax |
| --- | --- |
| Long form | `BUS:CC:ROLE:STATus?` |
| Short form | `BUS:CC:ROLE:STAT?` |

Query the CC bus controller role status. Returns one of: UNATTACHED, SOURCE_FOUND, ATTACHED

### Parameters

No parameters.

### Response

Returns query-specific data described above.

### Command-specific errors

No command-specific errors documented. Common SCPI parser errors may still apply.

### Source

- Catalog handler: `_queryCCBusControllerRoleStatus`
- Handler source: `firmware/lib/app/app_scpi_bus.cpp`

## `BUS:CC:CAPture:CYCLETIME?`

**Type:** Query

**Syntax:**

```scpi
BUS:CC:CAPture:CYCLETIME?
```

### Accepted forms

| Form | Syntax |
| --- | --- |
| Long form | `BUS:CC:CAPture:CYCLETIME?` |
| Short form | `BUS:CC:CAP:CYCLETIME?` |

Query the length of a capture cycle in nanoseconds

### Parameters

No parameters.

### Response

Returns query-specific data described above.

### Command-specific errors

No command-specific errors documented. Common SCPI parser errors may still apply.

### Source

- Catalog handler: `_queryCCBusCaptureCycleTime`
- Handler source: `firmware/lib/app/app_scpi_bus.cpp`

## `BUS:CC:CAPture:COUNT?`

**Type:** Query

**Syntax:**

```scpi
BUS:CC:CAPture:COUNT?
```

### Accepted forms

| Form | Syntax |
| --- | --- |
| Long form | `BUS:CC:CAPture:COUNT?` |
| Short form | `BUS:CC:CAP:COUNT?` |

Query the number of captured CC bus messages

### Parameters

No parameters.

### Response

Returns query-specific data described above.

### Command-specific errors

No command-specific errors documented. Common SCPI parser errors may still apply.

### Source

- Catalog handler: `_queryCCBusCapturedMessageCount`
- Handler source: `firmware/lib/app/app_scpi_bus.cpp`

## `BUS:CC:CAPture:DATA?`

**Type:** Query

**Syntax:**

```scpi
BUS:CC:CAPture:DATA?
```

### Accepted forms

| Form | Syntax |
| --- | --- |
| Long form | `BUS:CC:CAPture:DATA?` |
| Short form | `BUS:CC:CAP:DATA?` |

Query the CC bus for the next available captured message.
If no messages are available, returns an error.
Messages are returned as arbitrary data blocks with the following
format:

- Start timestamp (8 bytes, uint64_t): The timestamp of when message capture started, in microseconds.
- End timestamp (8 bytes, uint64_t): The timestamp of when message capture ended, in microseconds.
- Message decoding result (4 bytes, uint32_t): The result of decoding the message.
  Possible values are:
  - 0: Success
  - 1: Invalid K-code
  - 2: CRC error
  - 3: Timeout error
  - 4: Incomplete message
- SOP (4 bytes): The Start of Packet identifier.
- Pulse count (4 bytes, uint32_t): The number of pulses in the captured message.
- Pulse widths (N * 2 bytes, uint16_t): An array of pulse widths in PIO cycles.
- Data length (4 bytes, uint32_t): The length of the decoded data in bytes.
- Decoded data (M * 1 bytes, uint8_t): The decoded message

### Parameters

No parameters.

### Response

Returns query-specific data described above.

### Command-specific errors

| Code | Message | Meaning |
| --- | --- | --- |
| `-200` | Execution error | No captured CC bus messages are available to return. |

### Source

- Catalog handler: `_queryCCBusNextCapturedMessage`
- Handler source: `firmware/lib/app/app_scpi_bus.cpp`

## `BUS:CC:CAPture:EN`

**Type:** Command

**Syntax:**

```scpi
BUS:CC:CAPture:EN
```

### Accepted forms

| Form | Syntax |
| --- | --- |
| Long form | `BUS:CC:CAPture:EN` |
| Short form | `BUS:CC:CAP:EN` |

Enable or disable CC bus message capture

### Parameters

| Name | Type | Values/default | Description |
| --- | --- | --- | --- |
| `state` | enum | `ON`, `OFF` | The desired capture state. |

### Response

No SCPI data response. Successful command execution completes without a payload.

### Command-specific errors

| Code | Message | Meaning |
| --- | --- | --- |
| `-224` | Illegal parameter value | The capture state value was not ON or OFF. |

### Source

- Catalog handler: `_setCCBusMessageCaptureState`
- Handler source: `firmware/lib/app/app_scpi_bus.cpp`

## `BUS:CC:CAPture:EN?`

**Type:** Query

**Syntax:**

```scpi
BUS:CC:CAPture:EN?
```

### Accepted forms

| Form | Syntax |
| --- | --- |
| Long form | `BUS:CC:CAPture:EN?` |
| Short form | `BUS:CC:CAP:EN?` |

Query the CC bus message capture status

### Parameters

No parameters.

### Response

Returns query-specific data described above.

### Command-specific errors

No command-specific errors documented. Common SCPI parser errors may still apply.

### Source

- Catalog handler: `_queryCCBusMessageCaptureState`
- Handler source: `firmware/lib/app/app_scpi_bus.cpp`

## `BUS:CC:CAPture:CLEAR`

**Type:** Command

**Syntax:**

```scpi
BUS:CC:CAPture:CLEAR
```

### Accepted forms

| Form | Syntax |
| --- | --- |
| Long form | `BUS:CC:CAPture:CLEAR` |
| Short form | `BUS:CC:CAP:CLEAR` |

Clear the captured CC bus message buffer

### Parameters

No parameters.

### Response

No SCPI data response. Successful command execution completes without a payload.

### Command-specific errors

No command-specific errors documented. Common SCPI parser errors may still apply.

### Source

- Catalog handler: `_clearCCBusCapturedMessages`
- Handler source: `firmware/lib/app/app_scpi_bus.cpp`

## `BUS:VBUS:STATus?`

**Type:** Query

**Syntax:**

```scpi
BUS:VBUS:STATus?
```

### Accepted forms

| Form | Syntax |
| --- | --- |
| Long form | `BUS:VBUS:STATus?` |
| Short form | `BUS:VBUS:STAT?` |

Query the VBUS status and latched protection event timestamps.
Returns three comma-separated fields:
- Status token: ENABLED, DISABLED, OVP, or OCP
- Most recent OVP event timestamp in microseconds, or NONE
- Most recent OCP event timestamp in microseconds, or NONE
If OVP or OCP is returned, the VBUS controller is in a FAULT state and must be reset.

### Parameters

No parameters.

### Response

- Returns three comma-separated fields:

### Command-specific errors

No command-specific errors documented. Common SCPI parser errors may still apply.

### Source

- Catalog handler: `_queryVBusStatus`
- Handler source: `firmware/lib/app/app_scpi_vbus.cpp`

## `BUS:VBUS:RESET`

**Type:** Command

**Syntax:**

```scpi
BUS:VBUS:RESET
```

### Accepted forms

| Form | Syntax |
| --- | --- |
| Long form | `BUS:VBUS:RESET` |
| Short form | `BUS:VBUS:RESET` |

Reset the VBUS controller from a FAULT state.

### Parameters

No parameters.

### Response

No SCPI data response. Successful command execution completes without a payload.

### Command-specific errors

No command-specific errors documented. Common SCPI parser errors may still apply.

### Source

- Catalog handler: `_resetVBus`
- Handler source: `firmware/lib/app/app_scpi_vbus.cpp`

## `BUS:VBUS:OVPThreshold`

**Type:** Command

**Syntax:**

```scpi
BUS:VBUS:OVPThreshold
```

### Accepted forms

| Form | Syntax |
| --- | --- |
| Long form | `BUS:VBUS:OVPThreshold` |
| Short form | `BUS:VBUS:OVPT` |

Set the VBUS overvoltage protection threshold in volts.
For example, BUS:VBUS:OVPThreshold 12.5 configures a
12.5 V threshold.

### Parameters

| Name | Type | Values/default | Description |
| --- | --- | --- | --- |
| `threshold_v` | number | — | The desired OVP threshold in volts, from 0 V through 60 V. |

### Response

No SCPI data response. Successful command execution completes without a payload.

### Command-specific errors

| Code | Message | Meaning |
| --- | --- | --- |
| `-222` | Data out of range | The OVP threshold was negative or greater than the supported 60 V limit. |

### Source

- Catalog handler: `_setVBusOVPThreshold`
- Handler source: `firmware/lib/app/app_scpi_vbus.cpp`

## `BUS:VBUS:OVPThreshold?`

**Type:** Query

**Syntax:**

```scpi
BUS:VBUS:OVPThreshold?
```

### Accepted forms

| Form | Syntax |
| --- | --- |
| Long form | `BUS:VBUS:OVPThreshold?` |
| Short form | `BUS:VBUS:OVPT?` |

Query the VBUS overvoltage protection threshold.
Returns the configured threshold in volts.

### Parameters

No parameters.

### Response

- Returns the configured threshold in volts.

### Command-specific errors

No command-specific errors documented. Common SCPI parser errors may still apply.

### Source

- Catalog handler: `_queryVBusOVPThreshold`
- Handler source: `firmware/lib/app/app_scpi_vbus.cpp`

## `BUS:VBUS:OCPThreshold`

**Type:** Command

**Syntax:**

```scpi
BUS:VBUS:OCPThreshold
```

### Accepted forms

| Form | Syntax |
| --- | --- |
| Long form | `BUS:VBUS:OCPThreshold` |
| Short form | `BUS:VBUS:OCPT` |

Set the VBUS overcurrent protection threshold in amps.
For example, BUS:VBUS:OCPThreshold 3 configures a
3 A threshold.

### Parameters

| Name | Type | Values/default | Description |
| --- | --- | --- | --- |
| `threshold_a` | number | — | The desired OCP threshold in amps, from 0 A through 6 A. |

### Response

No SCPI data response. Successful command execution completes without a payload.

### Command-specific errors

| Code | Message | Meaning |
| --- | --- | --- |
| `-222` | Data out of range | The OCP threshold was negative or greater than the supported 6 A limit. |

### Source

- Catalog handler: `_setVBusOCPThreshold`
- Handler source: `firmware/lib/app/app_scpi_vbus.cpp`

## `BUS:VBUS:OCPThreshold?`

**Type:** Query

**Syntax:**

```scpi
BUS:VBUS:OCPThreshold?
```

### Accepted forms

| Form | Syntax |
| --- | --- |
| Long form | `BUS:VBUS:OCPThreshold?` |
| Short form | `BUS:VBUS:OCPT?` |

Query the VBUS overcurrent protection threshold.
Returns the configured threshold in amps.

### Parameters

No parameters.

### Response

- Returns the configured threshold in amps.

### Command-specific errors

No command-specific errors documented. Common SCPI parser errors may still apply.

### Source

- Catalog handler: `_queryVBusOCPThreshold`
- Handler source: `firmware/lib/app/app_scpi_vbus.cpp`

## `BUS:VBUS:CALibrate?`

**Type:** Query

**Syntax:**

```scpi
BUS:VBUS:CALibrate?
```

### Accepted forms

| Form | Syntax |
| --- | --- |
| Long form | `BUS:VBUS:CALibrate?` |
| Short form | `BUS:VBUS:CAL?` |

Query the full VBUS correction table.
Returns 61 comma-separated correction values ordered by
raw VBUS bucket from 0V through 60V.

### Parameters

No parameters.

### Response

- Returns 61 comma-separated correction values ordered by

### Command-specific errors

No command-specific errors documented. Common SCPI parser errors may still apply.

### Source

- Catalog handler: `_queryVBusCalibration`
- Handler source: `firmware/lib/app/app_scpi_vbus.cpp`

## `BUS:VBUS:CALibrate`

**Type:** Command

**Syntax:**

```scpi
BUS:VBUS:CALibrate
```

### Accepted forms

| Form | Syntax |
| --- | --- |
| Long form | `BUS:VBUS:CALibrate` |
| Short form | `BUS:VBUS:CAL` |

Capture the current live VBUS reading and store the
resulting correction for the specified raw VBUS bucket.
The command stores bucket - measured_vbus for the selected
integer raw bucket and persists the updated correction table.

### Parameters

| Name | Type | Values/default | Description |
| --- | --- | --- | --- |
| `bucket` | number | — | Raw integer-voltage VBUS bucket to update, from 0 to 60. |

### Response

No SCPI data response. Successful command execution completes without a payload.

### Command-specific errors

| Code | Message | Meaning |
| --- | --- | --- |
| `-224` | Illegal parameter value | The calibration bucket was not an integer value. |
| `-222` | Data out of range | The calibration bucket was outside the supported range of 0 through 60. |
| `-109` | Missing parameter | No calibration bucket parameter was provided. |

### Source

- Catalog handler: `_setVBusCalibrationPoint`
- Handler source: `firmware/lib/app/app_scpi_vbus.cpp`

## `BUS:VBUS:CALibrate:TABle`

**Type:** Command

**Syntax:**

```scpi
BUS:VBUS:CALibrate:TABle
```

### Accepted forms

| Form | Syntax |
| --- | --- |
| Long form | `BUS:VBUS:CALibrate:TABle` |
| Short form | `BUS:VBUS:CAL:TAB` |

Set one persisted VBUS correction table entry directly.
This is intended for importing a previously exported
calibration table; unlike BUS:VBUS:CALibrate it does not
read the live VBUS measurement.

### Parameters

| Name | Type | Values/default | Description |
| --- | --- | --- | --- |
| `bucket` | number | — | Raw integer-voltage VBUS bucket to update, from 0 to 60. |
| `correction_v` | number | — | Additive VBUS correction in volts for the selected bucket. |

### Response

No SCPI data response. Successful command execution completes without a payload.

### Command-specific errors

| Code | Message | Meaning |
| --- | --- | --- |
| `-224` | Illegal parameter value | The calibration bucket was not an integer value or the correction was not finite. |
| `-222` | Data out of range | The calibration bucket was outside the supported range of 0 through 60. |

### Source

- Catalog handler: `_setVBusCalibrationTablePoint`
- Handler source: `firmware/lib/app/app_scpi_vbus.cpp`

## `BUS:VBUS:CALibrate:DEFault`

**Type:** Command

**Syntax:**

```scpi
BUS:VBUS:CALibrate:DEFault
```

### Accepted forms

| Form | Syntax |
| --- | --- |
| Long form | `BUS:VBUS:CALibrate:DEFault` |
| Short form | `BUS:VBUS:CAL:DEF` |

Restore the full VBUS correction table to its default
firmware-defined values and persist the updated table.

### Parameters

No parameters.

### Response

No SCPI data response. Successful command execution completes without a payload.

### Command-specific errors

No command-specific errors documented. Common SCPI parser errors may still apply.

### Source

- Catalog handler: `_resetVBusCalibration`
- Handler source: `firmware/lib/app/app_scpi_vbus.cpp`

## `BUS:VBUS:CALibrate:CURRent?`

**Type:** Query

**Syntax:**

```scpi
BUS:VBUS:CALibrate:CURRent?
```

### Accepted forms

| Form | Syntax |
| --- | --- |
| Long form | `BUS:VBUS:CALibrate:CURRent?` |
| Short form | `BUS:VBUS:CAL:CURR?` |

Query the full VBUS current raw calibration table.
Returns 13 comma-separated raw measured current values in
amps, ordered by true current point from 0A through 6A in
500mA intervals.

### Parameters

No parameters.

### Response

- Returns 13 comma-separated raw measured current values in

### Command-specific errors

No command-specific errors documented. Common SCPI parser errors may still apply.

### Source

- Catalog handler: `_queryVBusCurrentCalibration`
- Handler source: `firmware/lib/app/app_scpi_vbus.cpp`

## `BUS:VBUS:CALibrate:CURRent`

**Type:** Command

**Syntax:**

```scpi
BUS:VBUS:CALibrate:CURRent
```

### Accepted forms

| Form | Syntax |
| --- | --- |
| Long form | `BUS:VBUS:CALibrate:CURRent` |
| Short form | `BUS:VBUS:CAL:CURR` |

Capture the current live VBUS current reading and store
the raw measured current for the specified true current.
Runtime current calibration inverts the resulting
piecewise-linear raw-to-true-current curve.

### Parameters

| Name | Type | Values/default | Description |
| --- | --- | --- | --- |
| `target_ma` | number | — | True VBUS current calibration point in milliamps; must be 0 through 6000 in 500mA intervals. |

### Response

No SCPI data response. Successful command execution completes without a payload.

### Command-specific errors

| Code | Message | Meaning |
| --- | --- | --- |
| `-224` | Illegal parameter value | The calibration current was not an integer value or was not aligned to a 500 mA interval. |
| `-222` | Data out of range | The calibration current was outside the supported range of 0 through 6000 mA. |
| `-109` | Missing parameter | No calibration current parameter was provided. |

### Source

- Catalog handler: `_setVBusCurrentCalibrationPoint`
- Handler source: `firmware/lib/app/app_scpi_vbus.cpp`

## `BUS:VBUS:CALibrate:CURRent:TABle`

**Type:** Command

**Syntax:**

```scpi
BUS:VBUS:CALibrate:CURRent:TABle
```

### Accepted forms

| Form | Syntax |
| --- | --- |
| Long form | `BUS:VBUS:CALibrate:CURRent:TABle` |
| Short form | `BUS:VBUS:CAL:CURR:TAB` |

Set one persisted VBUS current raw calibration table entry
directly. This is intended for importing a previously
exported calibration table; unlike BUS:VBUS:CALibrate:CURRent
it does not read the live VBUS current measurement.

### Parameters

| Name | Type | Values/default | Description |
| --- | --- | --- | --- |
| `target_ma` | number | — | True VBUS current calibration point in milliamps; must be 0 through 6000 in 500mA intervals. |
| `raw_current_a` | number | — | Raw measured current in amps for the selected true-current point. |

### Response

No SCPI data response. Successful command execution completes without a payload.

### Command-specific errors

| Code | Message | Meaning |
| --- | --- | --- |
| `-224` | Illegal parameter value | The calibration current was not an integer value, was not aligned to a 500 mA interval, or the raw current was negative or not finite. |
| `-222` | Data out of range | The calibration current was outside the supported range of 0 through 6000 mA. |

### Source

- Catalog handler: `_setVBusCurrentCalibrationTablePoint`
- Handler source: `firmware/lib/app/app_scpi_vbus.cpp`

## `BUS:VBUS:CALibrate:CURRent:DEFault`

**Type:** Command

**Syntax:**

```scpi
BUS:VBUS:CALibrate:CURRent:DEFault
```

### Accepted forms

| Form | Syntax |
| --- | --- |
| Long form | `BUS:VBUS:CALibrate:CURRent:DEFault` |
| Short form | `BUS:VBUS:CAL:CURR:DEF` |

Restore the full VBUS current raw calibration table to its
default firmware-defined values and persist the updated
table. The VBUS voltage correction table is preserved.

### Parameters

No parameters.

### Response

No SCPI data response. Successful command execution completes without a payload.

### Command-specific errors

No command-specific errors documented. Common SCPI parser errors may still apply.

### Source

- Catalog handler: `_resetVBusCurrentCalibration`
- Handler source: `firmware/lib/app/app_scpi_vbus.cpp`

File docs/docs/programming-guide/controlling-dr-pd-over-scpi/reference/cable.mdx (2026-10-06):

---
sidebar_position: 55
sidebar_label: CABLE
---

# CABLE Commands

:::info[Generated reference]
This page is generated from `firmware/lib/app/scpi.yaml`. Do not edit it by hand; update the catalog or generator instead.
:::

## Common parser errors

These parser-level errors can apply before a command handler runs.

| Code | Message | Meaning |
| --- | --- | --- |
| `-100` | Command error | Malformed command syntax or command not recognized by the SCPI interpreter. |
| `-102` | Syntax error | Unexpected token or separator in command input. |
| `-104` | Data type error | Parameter could not be parsed as required type. |
| `-109` | Missing parameter | Required parameter was omitted. |
| `-222` | Data out of range | Numeric parameter was outside supported range. |
| `-224` | Illegal parameter value | Parameter parsed correctly but value was not accepted for this command. |

## `CABLE:TEST?`

**Type:** Query

**Syntax:**

```scpi
CABLE:TEST?
```

### Accepted forms

| Form | Syntax |
| --- | --- |
| Long form | `CABLE:TEST?` |
| Short form | `CABLE:TEST?` |

Read coherent Cable Test snapshot and renew its three-second host lease. Returns generation,outcome,VCONN contact (0/1/2),GoodCRC seen (0/1),PD header revision (1=2.0 or 2=3.x),hex response body including VDM header. Outcomes: DISABLED, WAITING, DISCOVERING, IDENTITY, NO_RESPONSE, RESPONSE_TIMEOUT, NAK, MALFORMED, POWER_FAULT, UNSUPPORTED_CONNECTION. No Ra cannot distinguish an unmarked cable from empty/damaged.

### Parameters

No parameters.

### Response

Returns query-specific data described above.

### Command-specific errors

No command-specific errors documented. Common SCPI parser errors may still apply.

### Source

- Catalog handler: `_queryCableTest`
- Handler source: `firmware/lib/app/app_scpi_bus.cpp`

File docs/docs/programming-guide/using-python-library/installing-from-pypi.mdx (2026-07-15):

---
sidebar_position: 10
---

# Installing from PyPI

The Python package name is `t76`. It requires Python 3.11 or newer.

:::warning[PyPI publication in progress]
The `t76` package is not published on PyPI yet. For now, install it from a
local clone of the repository using the editable-install instructions below.
:::

## Install from PyPI

Once publication is complete, install with:

```bash
python -m pip install t76
```

For a clean project environment:

```bash
python -m venv .venv
source .venv/bin/activate
python -m pip install --upgrade pip
python -m pip install t76
```

## Install from the repository

You can also clone the repository and install the package directly from its
`python` directory. This is the current installation method while PyPI
publication is in progress:

```bash
python -m venv .venv
source .venv/bin/activate
python -m pip install --upgrade pip
python -m pip install -e ./python
```

For development tools:

```bash
python -m pip install -e "./python[dev]"
```

## Run the terminal app

After installation, run the Dr. PD terminal app:

```bash
drpd
```

The module entry point remains available:

```bash
python -m t76.drpd
```

You can also list available top-level apps:

```bash
python -m t76 --apps
```

## Platform notes

The library talks to Dr. PD over USBTMC through PyUSB. Your operating system must allow the Python process to access the Dr. PD USB interface.

On Linux this may require a udev rule. On macOS and Windows, make sure no other app has exclusive access to the device while the script is running.

## License and source

The `t76` Python package is licensed under the GNU Affero General Public
License v3.0 only (`AGPL-3.0-only`). Its source is available in the
[T76-org/drpd repository](https://github.com/T76-org/drpd/tree/main/python).

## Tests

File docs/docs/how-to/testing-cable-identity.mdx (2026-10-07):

---
title: Determine a cable's characteristics
sidebar_position: 6
---

# Determine a cable's characteristics

The Cable Test function reads the identity advertised by an electronically marked
USB-C cable. It supports Dr. PD hardware revision R2605-A and either plug orientation.

1. Select **Mode → Cable Test...** from the menu.
2. Connect either end of the cable to **Port 1 (DUT)**, leaving the other end unplugged.
   Discovery starts automatically.
3. Dr. PD fills the identity and capability fields with the information retrieved
   from the cable's e-marker, if it responds with a valid identity.
4. Close the dialog to return Dr. PD to **Disabled** mode.

The firmware detects the cable's Ra termination, powers the corresponding VCONN
contact, and sends a structured `Vendor_Defined` Discover Identity request to SOP′
on the other CC contact.

The dialog groups the results into **General Information**, **Cable Information**,
and, for active cables that report these details, **Active Cable Features**.
These sections show the cable type, connector type, vendor ID, advertised current
and voltage limits, USB speed class, and other reported capabilities. The speed
indication describes the maximum signalling rate associated with the reported
class; actual transfer speed depends on the connected devices and operating mode.

:::note
The returned information represents the manufacturer's claims stored in the
cable's e-marker. Dr. PD checks the response format, but it does not measure the
cable's performance or verify that it meets those claims.
:::

## Interpret the results

- **“No cable detected, damaged cable, or cable without an e-marker.”** means
  that Dr. PD has not received an identity or a matching `GoodCRC` acknowledgement.
  An empty port, an unmarked cable, or a cable whose e-marker cannot respond can
  produce this message. Ensure that the far end is unplugged and connect the
  cable to Port 1.
- **“E-marked cable detected.”** means that Dr. PD received an identity or a
  matching `GoodCRC` acknowledgement from the cable. The capability fields remain
  blank unless a valid identity response is received.

More detailed outcomes are available through the
[CABLE commands](../programming-guide/controlling-dr-pd-over-scpi/reference/cable):
`NO_RESPONSE` means no matching acknowledgement was received after bounded retries;
`RESPONSE_TIMEOUT` means the request was acknowledged but no identity response
arrived; `NAK` means the responder declined the request; `MALFORMED` means the
identity response was invalid; and `POWER_FAULT` means VCONN did not reach the
required voltage. A power fault does not imply that the cable sent an invalid message.

:::note
Dr. PD's VCONN circuit is designed for low-current e-markers requiring about 5 mA
or less, so compatibility with every active cable is not guaranteed. Testing both
ends and orientations can expose asymmetric faults, but it does not test the
continuity of every conductor.
:::

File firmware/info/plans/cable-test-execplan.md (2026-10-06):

# Cable Test mode

## Purpose and approved scope

Single-ended e-marker identity discovery on Port 1 of R2605-A. Far end stays
unplugged. Both orientations supported. Mode > Cable Test opens a dialog; close
returns Disabled. Identity only; no SVID/mode discovery. User authorized implementation
and live validation on connected Dr. PD (USB serial 2D784F584994A97E).

## Design

A dedicated core-1 controller owns CC probing, VCONN sequencing and SOP-prime
Discover Identity. Sink policy remains disabled. Port 2 and VBUS isolated.
Start through BUS:CC:ROLE CABLE_TEST; poll CABLE:TEST? for one coherent snapshot,
including generation, evidence and raw VDOs. Polling renews a three-second lease;
loss of host, close or role change stops transmission and VCONN. Mode is never
persisted. Discovery finishes by removing VCONN and resuming Ra monitoring so
unplug/replacement clears results without leaving the marker powered.

No Ra cannot distinguish an empty port, unmarked cable or damaged cable. Ra plus
no reply means nonresponding marker or electrical/power fault. Valid GoodCRC
provides stronger evidence of a PD responder. Identity ratings are advertised,
not measured. Initial 3.x discovery supports bounded 2.0 fallback and BUSY retries.

## Work and validation

- [x] Firmware controller, GPIO initialization correction, SCPI snapshot and transient role.
- [x] TypeScript/worker/Python APIs and dialog with complete identity metadata.
- [x] Host protocol and lifecycle tests, frontend/API tests, full builds.
- [x] Generated references and authored usage documentation.
- [x] Exact-device preflight, application image update, live discovery and Disabled cleanup.
- [ ] User-assisted unplug/replug/orientation checks; report physical coverage precisely.

## Discoveries

PLANS.md not present in repository; existing firmware/info/plans format used.
VCONN GPIOs already registered. Existing Sink cable inquiry deliberately rejects
VCONN use, so Cable Test does not relax Sink policy. Documentation states about
5 mA available VCONN current; active cable compatibility requires live qualification.

## Validation evidence (2026-10-06)

- Release firmware build passed; all six host tests passed. Frontend full suite:
  89 files / 841 tests passed; after final UI ordering/revision gating, relevant
  dialog/worker and RackView suites passed again. Frontend production build passed.
- Python suite: 323 passed, one live-device smoke skipped in the sandbox. Separate
  explicitly authorized PyUSB hardware validation ran outside the USB sandbox.
- Documentation generation and production build passed. Cable Test files pass
  ESLint. Full repository lint reports 13 errors / 19 warnings; existing RackView
  errors were reproduced from HEAD through ESLint stdin, and remaining errors are
  in unrelated files.
- USB preflight found one Dr. PD, serial 2D784F584994A97E, R2605-A, firmware 0.9.26.
  Full flash backup saved and verified at
  `/tmp/drpd-before-cable-test-2D784F584994A97E.uf2`. Application-only UF2 was loaded
  and verified; resident bootloader and persistent settings were preserved.
- Actual identity received in approximately 300 ms, VCONN on CC1, communication
  on CC2, matching GoodCRC. Complete body:
  `41A800FF0000601C000000000000000043260A00`.
  Advertised passive cable, 5 A, 50 V, EPR, USB4 Gen3; VID/PID/XID zero.
  These are advertised ratings, not measured cable performance.
- Chrome/WebUSB dialog displayed the real decoded identity. Closing returned
  Disabled. GPIO-role readback confirmed both OFF. VCONN switched off after
  discovery, with both contacts returning to default Rp for removal monitoring.
- Host-loss experiment withheld CABLE:TEST? for 3.5 seconds after successful
  identity. Readback: Disabled/Unattached, CC1 OFF, CC2 OFF.
  Evidence saved at `/tmp/drpd-cable-lease-evidence.json`.
- Live testing exposed and fixed stale ADC samples in the new mode, SOP-only
  power-role filtering incorrectly rejecting cable-plug responses, and missing
  browser-worker RPC routing. Captured SOP-prime header regression is host-tested.
- User-assisted physical removal and flipped insertion remain pending. Both
  orientation classifications pass host tests; only CC1 VCONN has been physically
  demonstrated so far. Unmarked, broken-marker, legacy and active cables have
  not been physically qualified.

## Intermittent stop investigation (2026-10-06)

The existing localhost:5173 Chrome session reproduced `Invalid Cable Test
snapshot`. That is a rejected response, not direct evidence of USB loss. Added
the actual received fields to the parser error so a recurrence is diagnosable.
The malformed reply itself did not recur after refreshing/reconnecting, so its
contents and original cause remain unconfirmed.

Independently, the core-1 lease check sampled the clock before loading the atomic
core-0 renewal timestamp. A renewal crossing a millisecond boundary could look
newer than the sampled clock; unsigned subtraction then wrapped to a huge age
and stopped the session. The controller now samples the lease before the clock
and uses a signed wrap-safe elapsed comparison. Host regression cases cover a
concurrent newer renewal, the exact three-second boundary and timer wrap.

Release build and all six firmware tests pass. Application-only correction was
flashed and verified on serial 2D784F584994A97E. Identity still succeeds, and
withholding polls for 3.5 seconds still returns Disabled with both contacts OFF.
Six dialog tests and ten snapshot/API tests pass; frontend build and changed-file
lint pass. A five-minute sustained Chrome run remained at successful identity
without a read failure. Screenshot: `/tmp/drpd-cable-stable-session.jpg`.
The lease fix must not be asserted as the proven cause of the earlier malformed
response. The user's existing dialog was left open for continued observation.

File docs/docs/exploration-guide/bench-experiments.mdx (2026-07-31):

---
sidebar_position: 4
---

# Things to try on the bench

These bench scenarios are optional starting points. They are intended to make
Dr. PD easier to explore without having to invent every setup from scratch.

Before running high-power tests, read the [important warnings](../important-warnings.mdx),
the [Sink mode guide](../how-to/operating-as-sink.mdx), and the
[protection mechanism guide](../how-to/protection-mechanisms.mdx). The maximum
voltage, current, and power available in any setup is limited by the source,
cable, negotiated protocol mode, external load, and Dr. PD hardware limits.

:::warning
The OVP and OCP settings are cutoff thresholds. They are not current limiting,
voltage clamping, or electronic-load control features. If a threshold is
crossed, Dr. PD disconnects power delivery and requires a manual reset.
:::

## Capture a USB-PD negotiation

A first capture shows three useful views at once: decoded protocol messages,
VBUS measurements, and timing.

You can try this with a known-good USB-PD source connected to Port 1:

1. Select **Mode → Sink**.
2. Select **Capture → Enable Capture** or press `C`.
3. Use **Mode → Cycle USB Connection** or press `T` to start a fresh attach
   sequence.
4. Open the Message Log and look for Source Capabilities, Request, Accept,
   PS RDY, and GoodCRC messages.
5. Select a message to inspect the raw data and decoded fields.

For a simple charger, the first contract will normally be a fixed 5 V profile.
More capable sources may also advertise PPS, AVS, or EPR capabilities.

See [Capturing USB-PD messages](../how-to/capturing-messages.mdx) for the full
capture workflow.

## Observe an inline connection

Observer mode is useful when you want to see what two real USB-C devices
negotiate with each other.

You can put Dr. PD inline between a source and sink with two USB-C cables, set
**Mode → Observer**, select **Capture → Enable Capture**, and then complete the
connection. When possible, use one passive, non-e-marked cable in the chain; two
e-marked cables can confuse some connections.

Things to compare:

- The source capabilities advertised by the source.
- The contract requested by the sink.
- Whether the devices attach once, reset repeatedly, or drop VBUS.
- Whether the same devices behave differently with another cable.

See [Observing a USB connection](../how-to/observing-connection.mdx) for cable
setup details.

## Explore a source in Sink mode

Sink mode lets Dr. PD act as a controllable USB-PD sink. This is useful for
learning how a charger, power bank, dock, or USB-C port responds to specific
power requests.

Starting points:

- Connect the source to Port 1 and select **Mode → Sink**.
- Confirm the header reports `Attached` and shows the current VBUS voltage and
  power profile.
- Open **Mode → Choose power contract...** to see the advertised contracts.
- Select a relevant contract and watch the Request, Accept, PS RDY, and VBUS
  behavior in the Message Log.
- Add manual markers before changing contracts, cables, or load settings.

In Sink mode, Port 2 is disconnected from the USB-PD bus and VBUS line. Keeping
Port 2 clear still makes the setup easier to reason about.

## Compare fixed, PPS, AVS, and EPR contracts

Different sources expose different USB-PD capabilities. A useful exploration is
to compare what the same source offers across cable and load changes.

You can start with a fixed PDO such as 9 V, 15 V, or 20 V when the source
advertises one. If the source advertises PPS or AVS, try a few supported
voltages and watch how the negotiated result appears in the log and VBUS
readings. Enable EPR only when the source, cable, load, and bench setup are
rated for the requested power level.

Look for cases where a source advertises fewer profiles with one cable than
another, refuses an unsupported request, changes behavior under load, or falls
back after a protection event.

:::danger
EPR and other high-power tests can exceed 100 W and may approach 240 W with
suitable equipment. Use an EPR-rated cable, a load rated for the requested
voltage and power, short insulated banana leads, a non-flammable surface, and
continuous supervision.
:::

## Add an electronic load

The banana connectors let you draw controlled current from the negotiated VBUS
rail with an external electronic load.

Useful things to explore:

- Use **Protection → Set thresholds...** to open **OVP/OCP settings**, then set
  conservative OVP and OCP thresholds before connecting the load.
- Start with the electronic load disabled or at zero current.
- Increase load current gradually while watching VBUS voltage, source messages,
  Dr. PD current readings, and the load readback.
- Step the load up and down to observe voltage regulation, current capability,
  and recovery behavior.

Stay within the source rating, cable rating, load rating, and Dr. PD limits.
Use the electronic load to control current draw; Dr. PD's OCP threshold is a
cutoff, not a programmable current limit.

## Compare cables and sources

USB-C behavior often changes with the cable. A simple comparison can make the
available contracts and limitations much easier to see.

Things to compare:

- The same source with passive, e-marked, high-current, or EPR-rated cables.
- The same cable across several sources.
- Source Capabilities, EPR availability, PPS ranges, and successful contracts.
- Captures exported with file names that identify the source, cable, contract,
  and load condition.

This can expose missing high-current profiles, cable-limited EPR availability,
source-specific PPS ranges, or sources that advertise a mode but reject a
request under load.

## Look at protection behavior

Protection behavior is worth understanding before relying on it during more
complex tests.

You can set OVP/OCP thresholds near the expected contract and load range, then
observe what happens when a threshold is crossed. Dr. PD should disconnect power
delivery and require a manual reset before normal operation resumes.

Keep this exploration conservative. Protection trips do not make an unsafe load
safe, and they do not replace the source's protections, cable ratings, or an
appropriately configured electronic load.

## Use the sync output with an oscilloscope

The sync output can correlate USB-PD events with an oscilloscope capture of CC
activity, VBUS movement, or external load behavior.

You can connect one scope channel to the sync output and another to the signal
you want to compare, then select **Trigger → Configure...** and choose an event
such as SOP start, Message Complete, Hard Reset, CRC Error, or Any Error.

The sync port is limited to 3.3 V and 5 mA. In pull-down mode, do not connect
it to a voltage outside its specification. Trigger latency and exact timing
behavior should be verified against the current firmware and datasheet before
making precise timing claims.

See [Using triggers and the sync output](../how-to/using-triggers.mdx) for
trigger configuration details.

## Export CSV and JSON

Exports are useful when you want to compare runs outside the UI.

- Use **Capture → Export Selected → CSV...** for spreadsheet-friendly
  summary tables with a fixed set of exported columns.
- Use **Capture → Export Selected → JSON...** when you want stored raw
  capture rows and annotations that the app can import and decode again.
- Add manual markers before changing cables, contracts, or load settings so the
  exported data is easier to interpret later.

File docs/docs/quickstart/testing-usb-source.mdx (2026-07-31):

---
sidebar_position: 3
---

# Testing a USB-PD source

One of the many uses of Dr. PD is to test and characterize USB-PD sources such as chargers, power banks, and USB-C ports on laptops. 

This section will guide you through the steps required to get your first capture of a USB-PD source, and introduce some of the features of the control software that can help you analyze and understand the captured data.

## Connecting the source

To test a USB-PD source, you will need to connect it to Port 1 (the left port) on the front of Dr. PD using a USB-C cable. For this initial test, any USB-PD source and cable should work. Since our goal is to ensure that your Dr. PD unit is working well, we recommend using a charger and cable that you are confident work correctly. If you have a USB-C laptop charger, that is a great choice for this test. Leave the source disconnected until capture is enabled below so the initial attach and negotiation are recorded.

## Enabling capture

Before connecting the source or entering Sink mode, select **Capture → Enable
Capture** from the menu, or press `C`. Dr. PD will record analog VBUS
measurements and USB-PD messages from the beginning of the connection.

## Placing Dr. PD in sink mode and connecting the source

Dr. PD can behave like a USB-PD sink device, simulating the behaviour of a laptop, phone, or other device that draws power from a USB-PD source. This allows you to capture and analyze the USB-PD messages sent by the source without the need for a physical sink device connected to the other port of Dr. PD.

Select **Mode → Sink** from the menu, or press `S`, then connect the source to
Port 1. You should see the MODE indicator change to “Sink” and the STATUS
indicator change to “Attached.”

At the same time, the VBUS voltage indicator should show 5V, and the PROFILE indicator should read “Fixed 5V @ 3A” or similar. This indicates that the source and Dr. PD have successfully established a USB-PD contract for the default 5V power profile, and that Dr. PD is now ready to capture and decode USB-PD messages from the source.

:::tip
When Dr. PD's VBUS input is floating, the VBUS voltage indicator will show a small, arbitrary voltage level that can fluctuate randomly. This is normal and does not indicate any issue with your Dr. PD unit. Once you connect a source to Port 1, the VBUS voltage should stabilize at the level corresponding to the power profile offered by the source (usually 5V for the default profile).
:::

## Capturing another negotiation

If the source was already connected before you enabled capture, select
**Mode → Cycle USB Connection**, or press `T`, now to record a fresh attach and
negotiation.

With capture enabled, you can interact with the source to trigger more USB-PD
messages. For example, select **Mode → Choose power contract...**, or press
`P`, to negotiate a new contract. If the source supports a 15 V profile, select
it and click **Set PDO**. This should display messages similar to the following
in the capture log:

| Length | Message type | Sender | Receiver | Message Summary |
|---:|---|---|---|---|
| 624µs | Request | Sink | Source | **Power request:**<br/><br/>- Selected source object position: 4<br/>- Operating current: 3A<br/>- Maximum operating current: 3A<br/><br/>**Asserted request flags:**<br/>- Requests no USB suspend while using this contract.<br/>- Supports unchunked extended messages.<br/>- Extended Power Range capable. |
| 492µs | GoodCRC | Source | Sink |  |
| 492µs | Accept | Source | Sink |  |
| 492µs | GoodCRC | Sink | Source |  |
| 493µs | PS RDY | Source | Sink |  |
| 492µs | GoodCRC | Sink | Source |  |

## Where to go from here

This quickstart guide is just the beginning of what you can do with Dr. PD. The control software has many features and settings that allow you to customize your testing and analysis experience, and there are many more use cases for Dr. PD beyond testing USB-PD sources. We encourage you to explore the control software and the documentation to discover all that Dr. PD has to offer, and to experiment with different devices, cables, and testing scenarios. Happy testing!

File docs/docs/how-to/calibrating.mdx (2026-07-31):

# Calibrating Dr. PD

Dr. PD comes calibrated from the factory for accurate voltage and current measurements. However, if you find that the readings are not accurate or want to fine-tune the calibration to match other instruments in your lab, you can follow the steps below to calibrate Dr. PD.

::::warning
The calibration affects the accuracy of _all_ measurements, including the ones that are used to trigger Dr. PD's safety features, such as overvoltage and overcurrent protection. Incorrect calibration may cause Dr. PD to fail to trigger these safety features when they are needed, which could lead to damage to your equipment or even personal injury. Always double-check your calibration settings and ensure that they are correct before using Dr. PD for any measurements.
::::

## How calibration works

Dr. PD's calibration works by linear interpolation between a series of reference intervals (1V for voltage and 500mA for current) that are stored in the device's flash memory. Calibration works by measuring the difference between the actual and measured voltage at the reference intervals, and then calculating a correction factor that is applied to all subsequent measurements.

Therefore, in order to change the calibration coefficients, all you need to is place the device in a known voltage or current condition, and then ask Dr. PD to make a measurement. Dr. PD will then calculate the correction factor based on the difference between the actual and measured voltage or current, and store it in flash memory for future use.

## Preparing protection thresholds

Calibration uses the same measurements that drive overvoltage and overcurrent
protection. Before either voltage or current calibration:

1. Select **Protection → Set thresholds...** to open **OVP/OCP settings**.
2. Record the normal OVP and OCP values so you can restore them afterward.
3. Set OVP above the highest voltage point and OCP above the highest current
   point you intend to calibrate, while keeping both thresholds within the safe
   limits of the reference source, load, cabling, and Dr. PD.

Do not set protection higher than the test setup can safely withstand. An OVP
or OCP trip interrupts calibration.

## Preparing for voltage calibration

1. In order to calibrate Dr. PD's voltage measurement, you will need to first disconnect any devices and cables from both USB-C ports. 
2. Then, connect a known voltage source to the banana jacks, respecting the correct polarity. This voltage source will act as your reference standard for the calibration, and should therefore be accurate and stable. The voltage source should be able to provide a voltage within the range of Dr. PD's measurement capabilities (up to 60V).

## Performing voltage calibration

Select **Device → [paired device] → Calibrate → Voltage...** for the
connected Dr. PD. The app shows a **Calibration warning**, then temporarily
switches Dr. PD to Observer mode and restores its previous mode when the dialog
closes. The voltage table contains points from 0 V through 60 V in 1 V steps.

To update a point, apply the corresponding voltage to the banana jacks and click
**Calibrate** beside that nominal value. If the live measurement is far from the
selected point, the app opens **Confirm calibration point**. Cancel and verify
the reference setup unless the mismatch is expected. Dr. PD then measures the
voltage, calculates the correction, and stores it in flash.

## Preparing for current calibration

Current calibration follows a slightly different procedure:

1. Connect a known-good USB-C source to Port 1.
2. Select **Mode → Sink**, then use **Mode → Choose power contract...** to
   negotiate at least 5 V and enough advertised current for the highest point
   you intend to calibrate. A 5 A contract is needed only for the 5 A point.
3. Connect a known current sink, such as a programmable electronic load, to the
   banana jacks.
4. Confirm that OCP is above the intended calibration current but still within
   the safe limit of every component in the setup.

## Performing current calibration

Select **Device → [paired device] → Calibrate → Current...** for the
connected Dr. PD. The app shows a **Calibration warning** and a table containing
points from 0 A through 6 A in 0.5 A steps.

Set the current sink to the selected nominal current, then click **Calibrate**.
If the live measurement is far from the selected point, the app opens
**Confirm calibration point**. Cancel and verify the load and reference setup
unless the mismatch is expected. Dr. PD then measures the current, calculates
the correction, and stores it in flash.

::::info[Limitations of current calibration]
With this mechanism, you can only calibrate your device up to 5A, which is the maximum current that can be negotiated over USB-C. Higher currents require a custom rig that provides up to 6A on Port 1, which is not available to the general public for safety reasons. Please contact us if you are interested in performing high-current calibration, and we will be happy to assist you.
::::

## Restoring protection

When calibration is complete, select **Protection → Set thresholds...** and
restore the normal OVP and OCP values recorded before calibration. Verify the
calibrated readings against the reference instruments before reconnecting a
device under test. Do not leave elevated calibration thresholds active for
normal operation.

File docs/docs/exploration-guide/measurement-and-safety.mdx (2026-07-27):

---
sidebar_position: 5
---

# Measurement and safety guardrails

Dr. PD makes USB-PD behavior easier to see, but high-power USB-C testing is
still live power work. Use known-good cables, an appropriate load, intentional
protection thresholds, and external instruments when the result matters.

## Electrical and measurement ranges

Use these limits when planning a setup or interpreting a capture.

| Item | Value | Note |
| --- | --- | --- |
| VBUS voltage measurement | 0-60 V | Stay inside the instrument limit and the ratings of the source, cable, load, and fixture. |
| VBUS current measurement | ±6 A | Current direction depends on the test mode and power flow. Confirm sign convention before comparing results. |
| Display and command resolution | 10 mV / 10 mA | Resolution is not the same as absolute accuracy. |
| Preliminary factory-calibrated accuracy | Typical +/-1% voltage and +/-2% current, full-scale | These specifications are preliminary, typical, and subject to change. Cross-check when accuracy matters. |
| Sink requests | Up to 48 V / 5 A / 240 W | Requires compatible protocol state, source capability, cable capability, load, and EPR/PPS/AVS support where applicable. |
| OVP/OCP thresholds | Up to 60 V / 6 A | Thresholds are protection settings, not operating recommendations. |

## Reading captures carefully

Dr. PD correlates decoded USB-PD traffic with VBUS voltage and current readings.
That is useful for attach, contract changes, load steps, disconnects, hard
resets, and protection events.

It helps to keep three kinds of evidence separate:

- **Protocol evidence:** messages observed, decoded, filtered, exported, or
  timed in the Message Log.
- **Electrical readings:** VBUS voltage, current, power, charge, or energy
  reported during the same interval.
- **External confirmation:** what a DMM, oscilloscope, electronic load, or power
  analyzer measured at the same point in the setup.

For timing-sensitive or signal-integrity questions, use an oscilloscope or logic
analyzer with the relevant CC/VBUS nodes. A decoded message log is strong
protocol evidence, but it is not an analog signal-integrity measurement by
itself.

## Calibration caveats

Dr. PD ships factory-calibrated, and the current preliminary typical accuracy
targets are +/-1% voltage and +/-2% current full-scale. Those values are not a
blanket guarantee for every setup, environmental condition, or future hardware
revision.

Calibration affects all measurements and protections. If calibration data is
wrong, VBUS readings can be wrong and OVP/OCP decisions can be wrong. Before
changing calibration, read the [calibration guide](../how-to/calibrating.mdx)
and use stable reference equipment.

For absolute accuracy work, compare more than one operating point. A single 5 V
reading does not characterize the 0-60 V voltage range, and a single load point
does not characterize the current range.

## OVP/OCP behavior

Dr. PD provides configurable overvoltage protection (OVP) and overcurrent
protection (OCP). These protections disconnect power delivery rather than
regulate it:

- OVP/OCP are cut-off protections, not voltage clamps or current limiters.
- Thresholds can be configured up to 60 V for OVP and 6 A for OCP.
- A triggered OVP or OCP condition latches and requires a manual reset before
  normal operation resumes.
- Threshold settings are stored on the device, so check the active limits before
  changing the setup.
- The protections depend on the same measurement calibration used for displayed
  VBUS readings.

Choose thresholds for the specific source, cable, load, and expected contract.
If a protection trip occurs, check the requested contract, cable, load behavior,
Dr. PD calibration, and independent measurements before drawing conclusions.

## EPR and high-power cautions

Sink mode can request high-power USB-PD contracts up to 48 V / 5 A / 240 W when
the source, cable, protocol negotiation, and load all support that condition.
That is enough power to damage equipment or start a fire if the bench setup is
wrong.

Before attempting EPR, AVS, PPS, or other high-power tests:

- Use a cable rated for the requested current and mode.
- Confirm the source actually advertises the requested contract.
- Use an external load rated for the requested voltage, current, and power.
- Set OVP/OCP thresholds intentionally rather than relying on defaults.
- Keep the test attended and stop if cables, connectors, the source, the load,
  or Dr. PD heat unexpectedly.

If a high-power request fails, the limiting factor may be the cable, contract
selection, EPR entry state, load, protection settings, or thermal behavior, not
just the source.

## Port 2 lockout and reverse polarity

When Dr. PD operates as a sink on Port 1, Port 2 is disconnected from the USB-PD
bus and VBUS line. This lockout protects a device that might have been left on
Port 2, but a simple setup with unused devices removed is easier to understand.

The banana connectors include reverse-polarity protection for cases where an
external source or load is connected backwards. If it trips, Dr. PD disconnects
the banana connector VBUS path; the control app does not present this as an
OVP/OCP event. Treat an unexpected 0 V reading at the banana connectors as a
reason to stop and inspect wiring before continuing.

## External cross-checks

Useful cross-checks include:

- Comparing Dr. PD voltage readings with a DMM at the banana connectors.
- Comparing Dr. PD current readings with the electronic load readback or a
  current probe/shunt suitable for the expected current.
- Capturing VBUS and CC with an oscilloscope while Dr. PD records decoded
  protocol traffic.
- Recording cable identity, source model, selected contract, load setting,
  protection thresholds, firmware/software version, and calibration state.

Dr. PD can make USB-PD behavior visible and repeatable. The bench setup,
external validation, and safety decisions still matter.

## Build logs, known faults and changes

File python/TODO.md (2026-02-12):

- **Misc**
    - [ ] Add support for logging events
    - [ ] Detect attach/detach of device and handle gracefully
    - [ ] Do not crash on launch if no device is attached
    - [ ] Verify all message structures against the spec

- **UI**
    - [ ] Fix power display - takes too long to track
    - [ ] Unify VBUS fetching through a single call and event
    - [ ] Truncate VBUS if < 1V and IBUS < 10mA
    - [ ] Unify look and feel of modals
    - [ ] Allow using Enter to submit a modal
    - [ ] Display errors in modals
    - [ ] Add a better menu/command palette

- Message list
    - [ ] Add filtering by message type
    - [ ] Add search functionality
    - [ ] Add export functionality (CSV, JSON)
    - [ ] Show local time for messages
    - [ ] Show device connect/disconnect events
    - [ ] Track device restarts

- **Sink Mode**
    - [ ] Verify that things work with a battery pack
    - [ ] Handle battery PDOs correctly

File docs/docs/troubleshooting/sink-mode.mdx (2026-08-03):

---
sidebar_position: 4
title: Sink mode
---

# Troubleshooting sink mode

Use this page when Dr. PD does not detect a source, does not negotiate the expected power contract, or disconnects while operating as a sink.

## Source remains Unattached

Confirm that MODE reads **Sink** and connect the source to Port 1, the left USB-C port. Port 2 is disconnected from the USB-PD bus and VBUS while Dr. PD is in sink mode.

Then check the source, cable, and power path:

- Confirm that the source is powered and can charge another known-good device.
- Try a known-good USB-C cable.
- Remove adapters and captive-cable extensions.
- Disconnect any external load from the banana connectors while establishing the first contract.

If the source attaches with no external load, add the load only after a stable contract is visible.

## Only the default contract is available

The source decides which power data objects it advertises. Open **Mode → Choose power contract...** and check the offered contracts. If the voltage or current you want is absent, verify the source specification, source input power, and cable rating.

PPS and AVS choices appear only when the source advertises compatible contracts. EPR also requires compatible source and cable support, and Dr. PD's EPR support must be enabled using **Mode → Sink behaviour → Support EPR mode**.

Do not assume that a charger's label guarantees every advertised mode under every input or cable condition. For example, a charger may advertise PPS or AVS but not support those modes at the same time as EPR, or it may require a specific cable rating to support the advertised current. If you are unsure, check the source's datasheet or test with a different cable.

## A requested contract fails or returns to 5 V

Remove the external load and request the contract again. If negotiation then succeeds, the source, cable, or protection settings may be reacting to the load transient or requested power.

Check the Message Log around the request and note whether the source accepts, rejects, waits, resets, or detaches. Compare the requested voltage and current with the exact offer shown in **Choose power contract...**.

For PPS or AVS, confirm that the requested value lies within the advertised range and step size. For EPR, use a cable and source rated for the intended EPR operation.

## Output disconnects under load

Reduce or remove the load first. Then check:

- Whether Dr. PD reported an overvoltage or overcurrent protection event.
- Whether the source reset or removed VBUS.
- Whether the selected contract permits the applied current.
- Whether the cable is rated for the requested current and power.
- Whether connectors, cables, or the source show abnormal heating.

Review [Dr. PD's protection mechanisms](../how-to/protection-mechanisms) and set limits appropriate for the device under test. Dr. PD's hardcoded hardware-protection limits are not substitutes for test-specific limits.

For setup and safety guidance, see [Operating Dr. PD as a sink](../how-to/operating-as-sink).

## Legacy USB-A Chargers Not Recognized / No USB-PD Traffic Detected

Connecting a legacy USB-A power adapter or charger to Port A yields no response, and Dr. PD does not detect a connected device or display power delivery messages.

Dr. PD relies on dedicated Configuration Channel (CC) lines to detect power source attachments and negotiate USB Power Delivery (USB-PD) contracts. Legacy USB-A power sources supply standard VBUS power without CC lines and do not support USB-PD protocol negotiation. Consequently, Dr. PD cannot establish a communication channel or trigger automated sink capabilities over a traditional USB-A connection.

To analyze USB Power Delivery messaging and automated sink profiles (SPR, EPR, PPS, or AVS), connect a native USB Type-C charger or source using a full-featured USB-C to USB-C cable.

If you only need to measure static VBUS voltage and current draw from a USB-A source, ensure a compatible USB-A to USB-C adapter/cable is used, and note that protocol decoding features will remain inactive.

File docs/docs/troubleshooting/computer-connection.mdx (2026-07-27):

---
sidebar_position: 2
title: Computer connection
---

# Troubleshooting the computer connection

Use this page when Dr. PD is not available to the control software, does not appear in the browser's device picker, or repeatedly disconnects.

## Dr. PD does not power on

Confirm that the cable is connected to Dr. PD's control port and to a powered USB port on the computer or tablet. Try another USB port and a known-good USB data cable. A hub, dock, or adapter can introduce a separate power or data problem, so connect Dr. PD directly to the computer while troubleshooting.

## Where is the Dr. PD software?

When you connect Dr. PD, your browser should display a connection notification. Click the notification to open the Dr. PD control software.

If the notification does not appear, open the [Dr. PD control software](https://t76.org/drpd/app) directly in Chrome or Edge.

:::tip[No drivers or installation required]

Dr. PD does not require any drivers or local software installation. If you prefer to run the control software as a local app in its own window, see [Installing Dr. PD as an app](../how-to/installing-as-app).

:::

## Dr. PD does not appear when pairing

Dr. PD requires Chrome or Edge and a USB cable that supports USB 2.0 communication. A cable that charges another device is not necessarily a data cable.

Before troubleshooting the browser, check whether the operating system detects Dr. PD. Disconnect Dr. PD, open the operating system's USB device list, and reconnect it while watching for a new device. On Windows, use Device Manager; on macOS, open System Information and select USB; on Linux, use the system's hardware information tool or run `lsusb`. The exact name may vary, so the important test is whether a USB device appears when Dr. PD is connected and disappears when it is disconnected.

If the operating system does not detect any new USB device, the problem is below the browser level. Replace the control cable with a known-good cable that you have verified can transfer data, connect Dr. PD directly instead of through a hub or dock, and try another USB port. Inspect both USB-C connectors for debris or damage and make sure they are fully seated. A damaged cable, a charge-only cable, or a faulty port may still supply enough power for Dr. PD to turn on while providing no data connection.

If possible, repeat the test with another computer. If Dr. PD appears there, return to the original computer and investigate its USB port, hub, adapter, or operating-system configuration. If Dr. PD is not detected on either computer with multiple known-good data cables, collect the combinations you tested before requesting support.

Once the operating system sees Dr. PD, continue with browser pairing:

1. Connect Dr. PD directly to the computer.
2. Open the [Dr. PD control software](https://t76.org/drpd/app).
3. Choose **Device → Pair new device...**.
4. Select Dr. PD in the browser's device picker and click **Connect**.

If no Dr. PD entry appears, close other browser tabs or applications that might already be using the device. Disconnect Dr. PD, reconnect it, and open the picker again. Then try another known-good data cable and USB port.

For the normal connection procedure, see [Connecting Dr. PD to your computer or tablet](../quickstart/connecting-dr-pd) and [Pairing Dr. PD](../quickstart/pairing-device).

## Pairing succeeds, but Dr. PD does not connect

Reopen the control software and reconnect Dr. PD. If it still does not connect, pair it again using **Device → Pair new device...**. Make sure you select the currently connected Dr. PD rather than another remembered USB device.

Installing the control software as an app does not change pairing or USB access. If the installed app fails to connect, test the same device in a regular Chrome or Edge window. See [Installing Dr. PD as an app](../how-to/installing-as-app).

## Connection drops or reconnects repeatedly

Intermittent connections are commonly isolated by simplifying the USB path:

- Replace the control cable with a short, known-good data cable.
- Connect directly instead of through a hub, dock, monitor, or adapter.
- Try another USB port.
- Check that the connector is fully seated and is not under mechanical strain.
- Disconnect the test setup from Port 1 and Port 2. If the control connection becomes stable, reconnect the test setup one part at a time.

If the problem follows Dr. PD across multiple computers, ports, and cables, collect the details listed in [Diagnostics and support](./diagnostics-and-support).

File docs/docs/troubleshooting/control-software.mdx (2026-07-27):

---
sidebar_position: 3
title: Control software
---

# Troubleshooting the control software

Use this page when Dr. PD connects but the frontend is blank, stale, unresponsive, or missing expected measurements or messages.

## The page is blank or does not finish loading

Reload the page and confirm that Chrome or Edge is up to date. If you installed Dr. PD as an app, close the app completely and reopen it. You can also test the control software in a regular browser window to determine whether the problem is limited to the installed app.

If the page still fails, record the browser name and version and whether the same URL works in a private browsing window or another supported browser. Do not clear browser data until you have recorded the problem and any settings you may need to restore.

## Dr. PD is connected, but values do not update

Confirm that the MODE and STATUS indicators respond when you change mode or attach a device. If none of the indicators update, reconnect Dr. PD using the steps in [Computer connection](./computer-connection).

If STATUS changes but a particular measurement does not, verify that the test setup should produce that measurement. In observer mode, for example, a sink-only device by itself may leave STATUS at **Unattached**. In sink mode, the source must be connected to Port 1.

## The Message Log is empty

An empty Message Log does not always indicate a frontend problem. USB-PD messages only appear when communication occurs after capture is active.

1. Confirm that Dr. PD is in the intended mode.
2. Start capture before connecting or renegotiating the devices.
3. Disconnect and reconnect the device under test to generate a fresh attachment and negotiation.
4. In observer mode, confirm that the devices reach **Attached**.

See [Capturing USB-PD messages](../how-to/capturing-messages) for the normal capture workflow. If devices attach but messages remain missing or malformed, continue with [Observer mode](./observer-mode).

## Settings or layout do not behave as expected

First reload the control software and reproduce the problem with the same sequence of actions. Record the affected setting, its expected value, and what happened instead. If possible, capture a screenshot before resetting settings or clearing browser data.

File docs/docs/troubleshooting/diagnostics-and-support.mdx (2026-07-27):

---
sidebar_position: 6
title: Diagnostics and support
---

# Collecting diagnostics and requesting support

A useful problem report describes both the symptom and the complete setup that produced it. If possible, try to collect the information below before resetting settings or clearing browser data.

## Record the environment

Include:

- Dr. PD hardware and firmware versions. You can obtain these from the Device menu.
- Operating system, browser name, and browser version.
- Whether the control software runs in a browser tab or as an installed app.
- Whether Dr. PD is connected directly or through a hub, dock, monitor, or adapter.

## Record the test setup

List every device in order from source to sink, including Dr. PD's port assignments. Include source and sink model numbers, cable types and ratings, adapters, external loads, and relevant power supplies.

For observer-mode problems, state which device is connected to Port 1 and Port 2 and whether either cable is e-marked. For sink-mode problems, include the source's advertised contracts, selected contract, external load, and protection limits.

## Record what happened

Provide:

1. Exact steps starting from Dr. PD disconnected.
2. Expected result.
3. Actual result.
4. MODE and each STATUS value shown during the test.
5. VBUS and PROFILE values, if present.
6. Any warning or error exactly as displayed.
7. Whether the problem occurs every time or intermittently.

Screenshots are useful for frontend state, but include the written steps and values as well so the problem can be searched and reproduced.

## Preserve captures and comparisons

Start capture before attaching the devices and preserve the original capture. If possible, also provide a comparison capture from one controlled change, such as another cable or a direct source-to-sink connection.

:::tip
You can export captures from the Message Log using **Capture → Export Selected → CSV...** or **Capture → Export Selected → JSON...**. We prefer JSON for support because it preserves the full message structure and timing.
:::

## Send this information to us

Email your problem report and any supporting captures or screenshots to [hello@t76.org](mailto:hello@t76.org). We will use the information above to help diagnose the problem.

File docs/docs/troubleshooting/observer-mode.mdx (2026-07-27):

---
sidebar_position: 5
title: Observer mode
---

# Troubleshooting observer mode

Use this page when the two devices do not connect through Dr. PD, STATUS does not reach **Attached**, or captured USB-PD traffic is missing or malformed.

## STATUS remains Unattached

Confirm that MODE reads **Observer**. Dr. PD must be connected inline between two devices using Port 1 and Port 2. A sink-only device connected by itself may still show **Unattached** because no source is present.

Test each device and cable in a simpler setup first. Confirm that the source and sink connect directly without Dr. PD, then insert Dr. PD and the second cable.

## STATUS stops at Source Found

**Source Found** means Dr. PD detects a source at one end but has not detected a completed source-to-sink attachment. Check the sink-side cable and device. Swap the two USB-C cables, reseat both connections, and confirm that the sink works when connected directly to the source.

## Devices work directly but not through Dr. PD

Observer mode requires two cables, while a normal USB-C connection uses one. If both cables contain e-markers, both e-markers may respond and confuse the attached devices.

Replace one cable with a simple passive USB-C cable without an e-marker. The other cable can remain e-marked. Also remove adapters and extension cables while troubleshooting.

See [Observing a USB connection](../how-to/observing-connection) for cable-selection details and the normal setup.

## Devices attach, but messages are missing

Start capture before attachment. Then disconnect and reconnect the source or sink to generate a complete negotiation. If capture starts after the devices are already attached, the initial capability exchange and contract negotiation will not be present.

:::tip[Cycling the connection without unplugging anything]

Choose **Mode → Cycle USB Connection** or press the `T` key to simulate a physical disconnection and reconnection. Dr. PD will restore the previous mode automatically, allowing you to capture a fresh negotiation without disturbing the cables.

:::

If only some traffic is missing, record which direction and message types are absent. Swap Port 1 and Port 2 or reverse one cable orientation, then repeat the capture. This helps identify a CC orientation, cable, or device-specific problem without changing several variables at once.

## Messages are malformed or decode poorly

First capture the same setup again after reseating the cables. Then:

- Try another passive cable in one half of the observer connection.
- Record which port and CC line carry the affected traffic.
- Preserve the original capture for comparison and support.

For a support report, include the physical topology, cable types, device models, STATUS sequence, and original capture as described in [Diagnostics and support](./diagnostics-and-support).

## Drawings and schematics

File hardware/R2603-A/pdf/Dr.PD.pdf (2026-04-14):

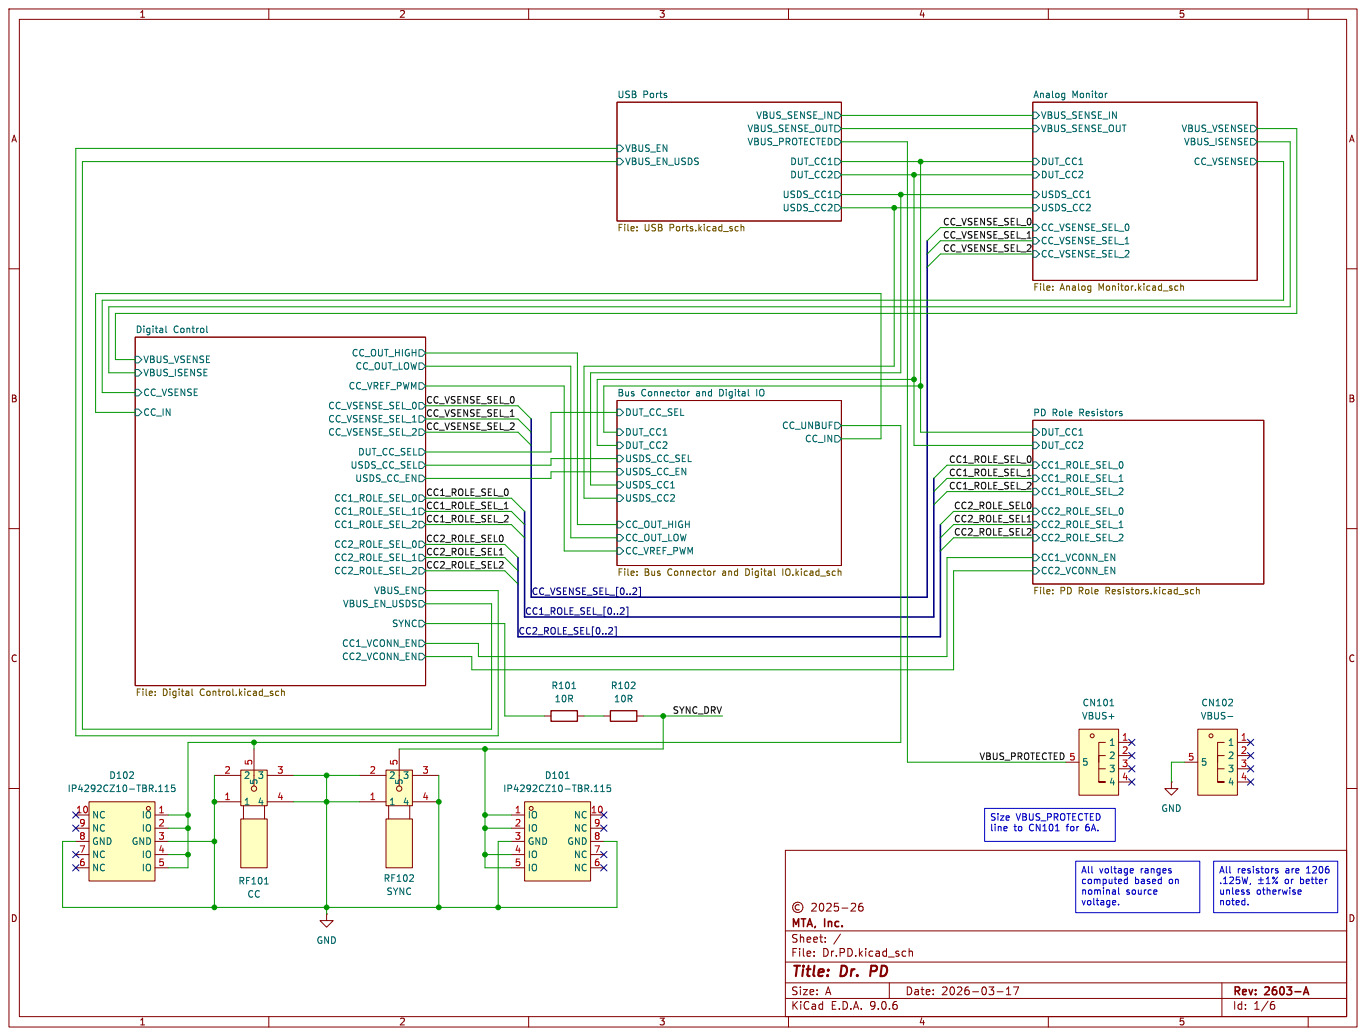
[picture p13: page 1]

VBUS_EN_USDS Digital Control File: Digital Control.kicad_sch

Size VBUS_PROTECTED
line to CN101 for 6A. All voltage ranges

.125W, þÿ±1%or better unless otherwise

Id: 1/6 Title: Dr. PD

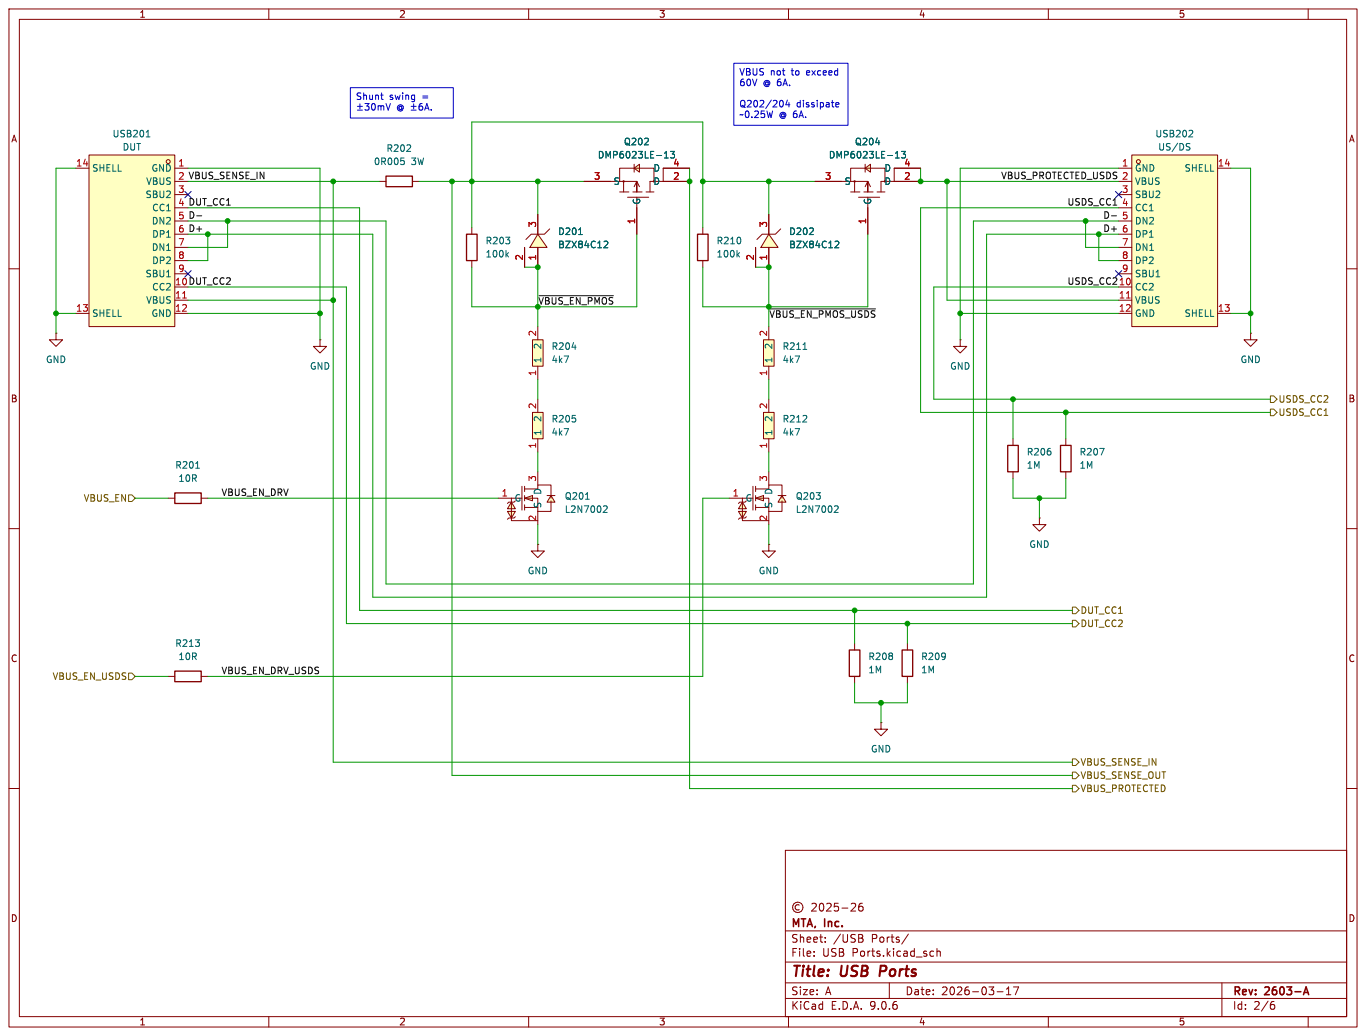
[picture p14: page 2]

Id: 2/6 Title: USB Ports

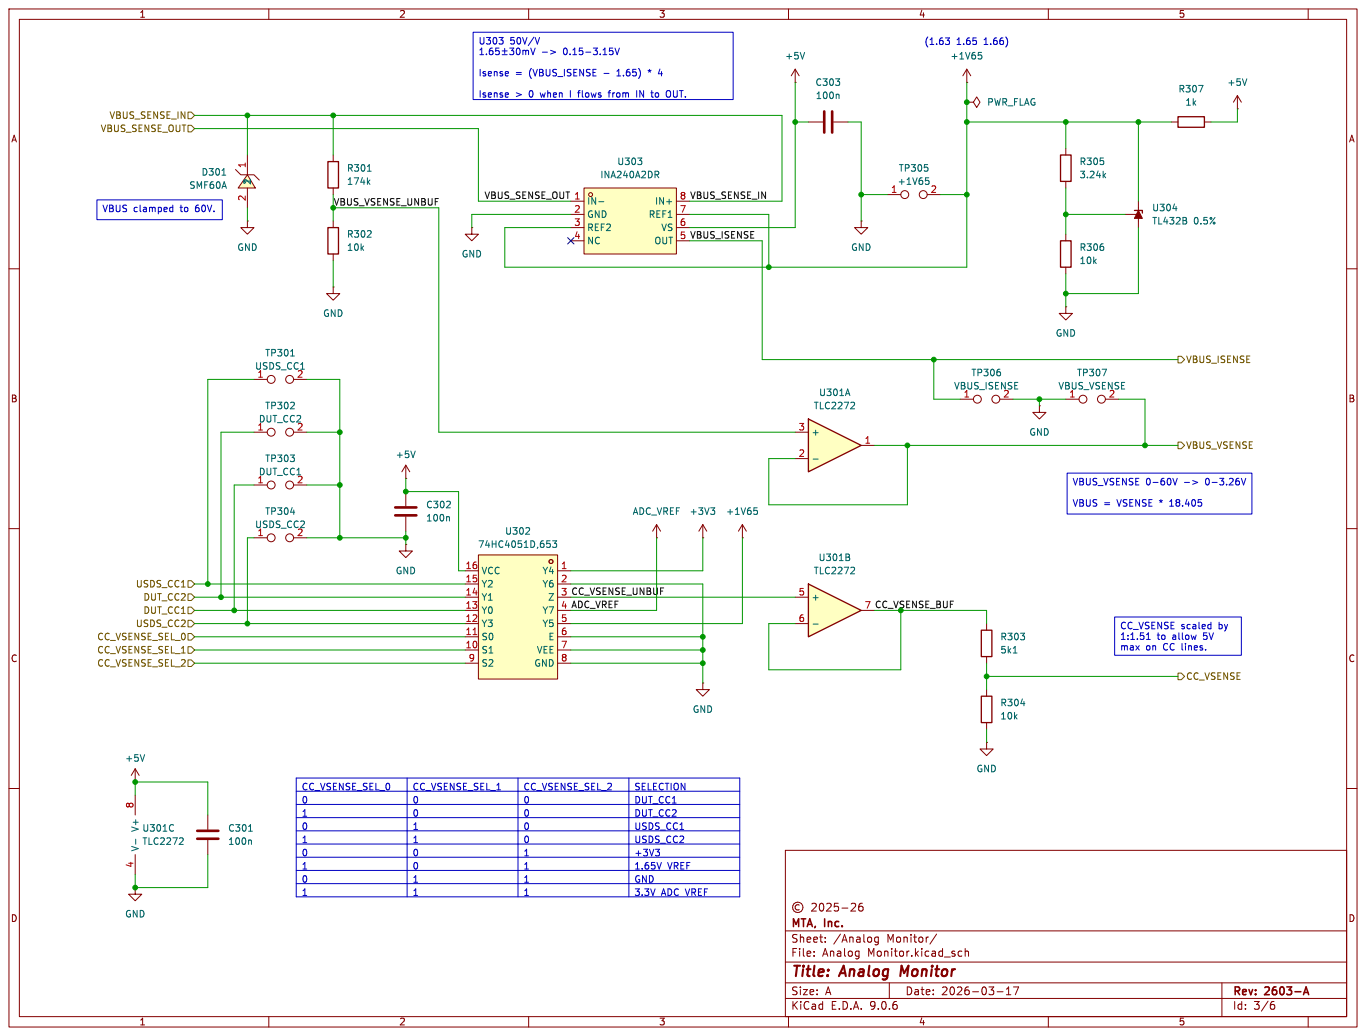
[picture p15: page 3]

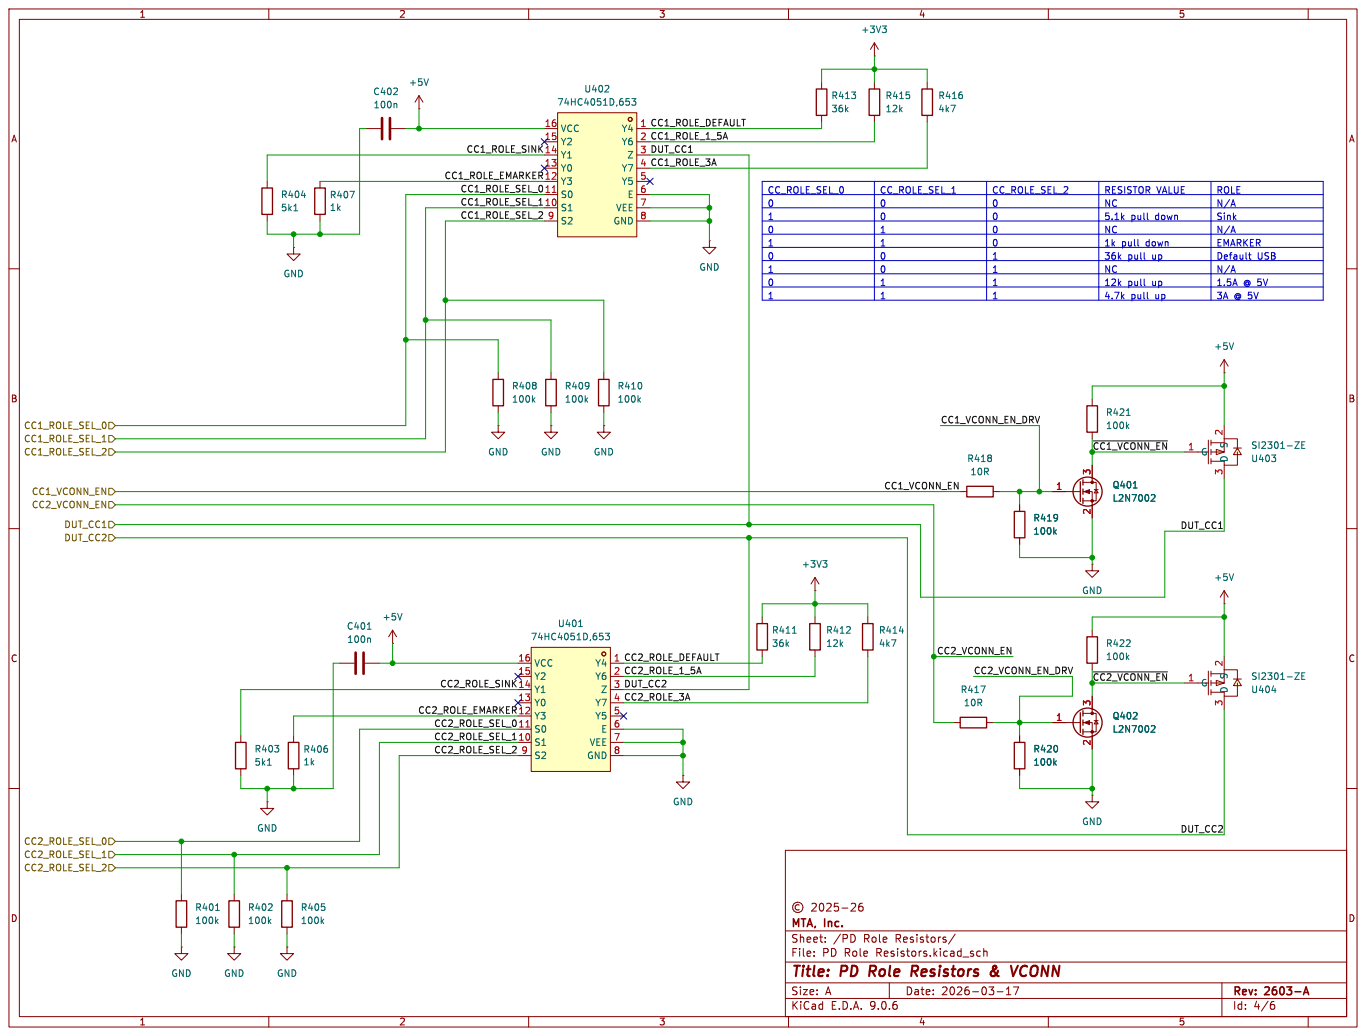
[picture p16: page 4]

Id: 4/6 Title: PD Role Resistors & VCONN

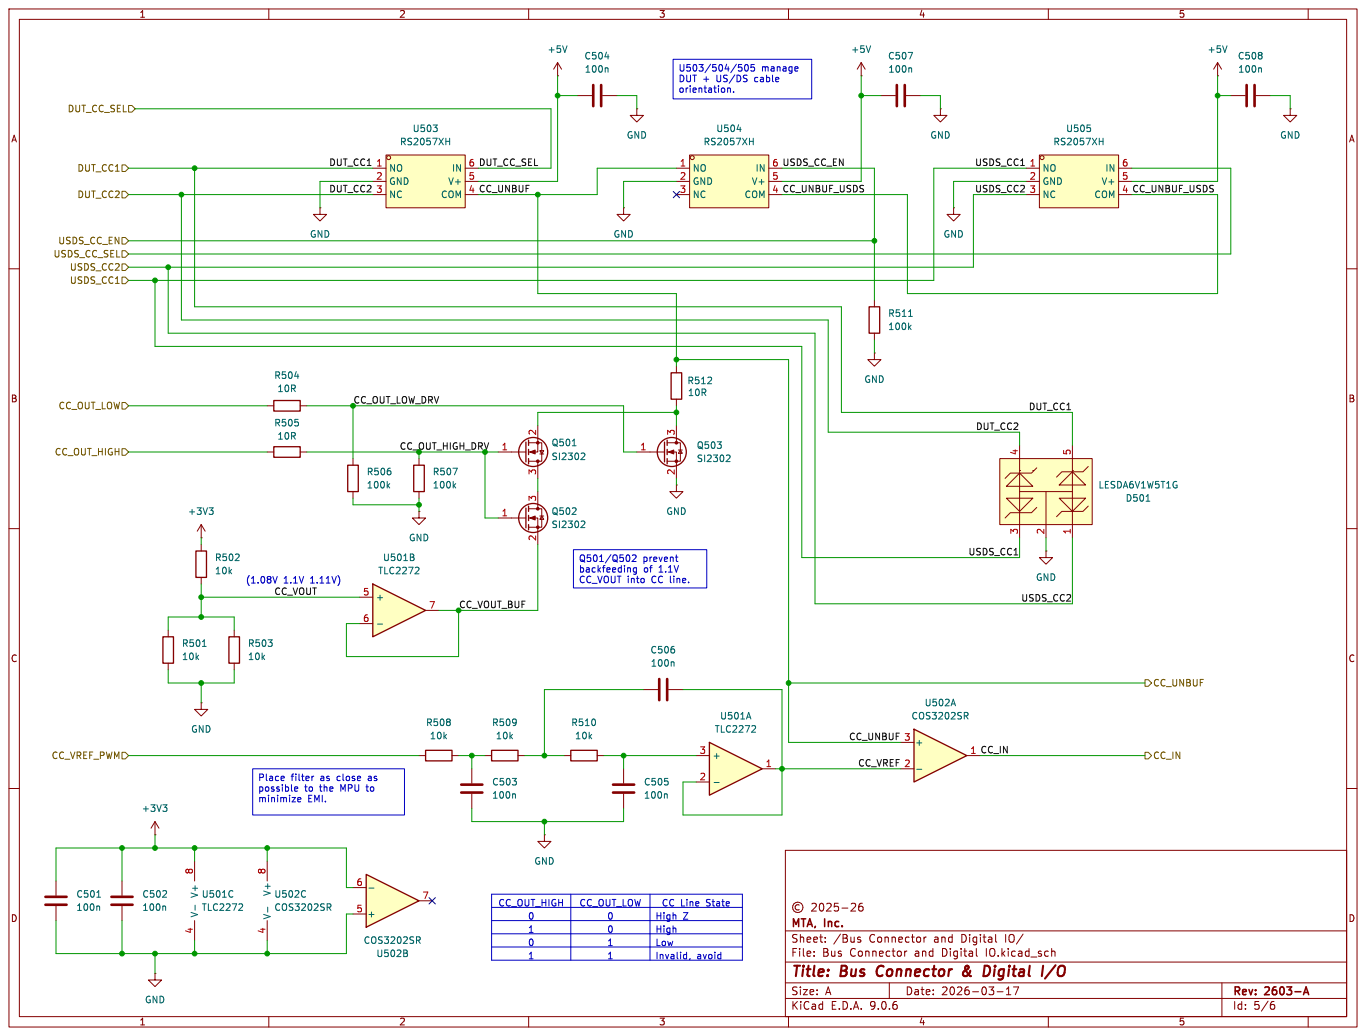
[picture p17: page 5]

Id: 5/6 Title: Bus Connector & Digital I/O

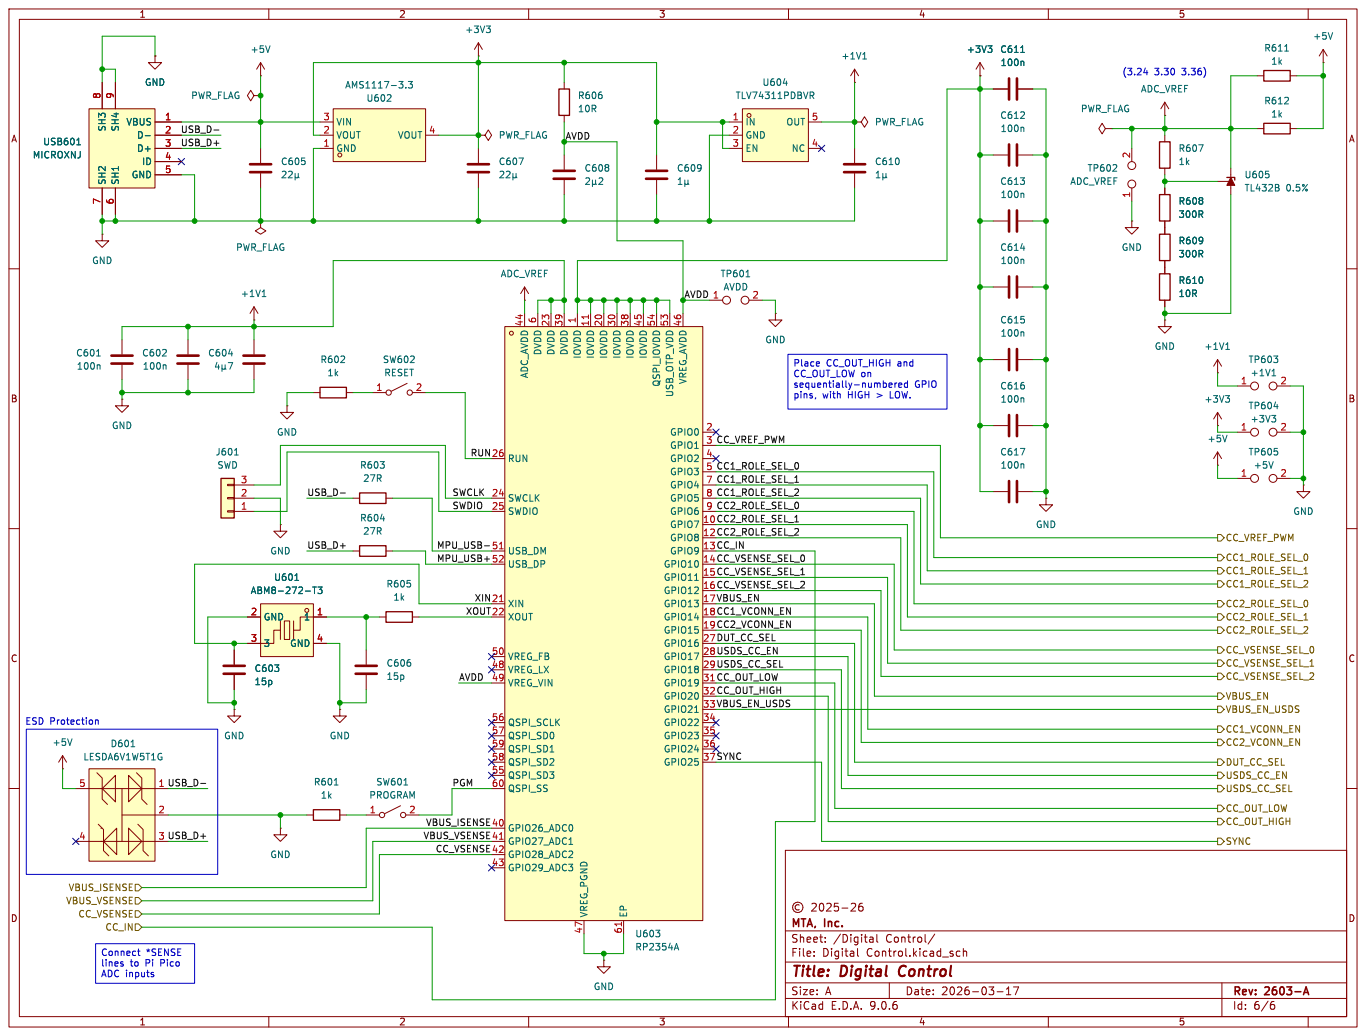
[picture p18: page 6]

1 VREG_PGND 47 IOVDD 11 IOVDD 20 IOVDD 30 EP 61 IOVDD 38 IOVDD 45 QSPI_IOVDD 54 USB_OTP_VDD 53 VREG_AVDD46 GPIO0 2 GPIO1 3 GPIO2 4 GPIO3 5 GPIO4 7 GPIO5 8 GPIO6 9 GPIO7 10 GPIO8 12 GPIO9 13 GPIO10 14 GPIO11 15 GPIO12 16 GPIO13 17 GPIO14 18 GPIO15 19 GPIO16 27 GPIO17 28 GPIO18 29 GPIO19 31 GPIO20 32 GPIO21 33 GPIO22 34 GPIO23 35 GPIO24 36 GPIO25 37 U603 RP2354A C606

pins, with HIGH > LOW. ESD Protection

lines to Pi Pico ADC inputs

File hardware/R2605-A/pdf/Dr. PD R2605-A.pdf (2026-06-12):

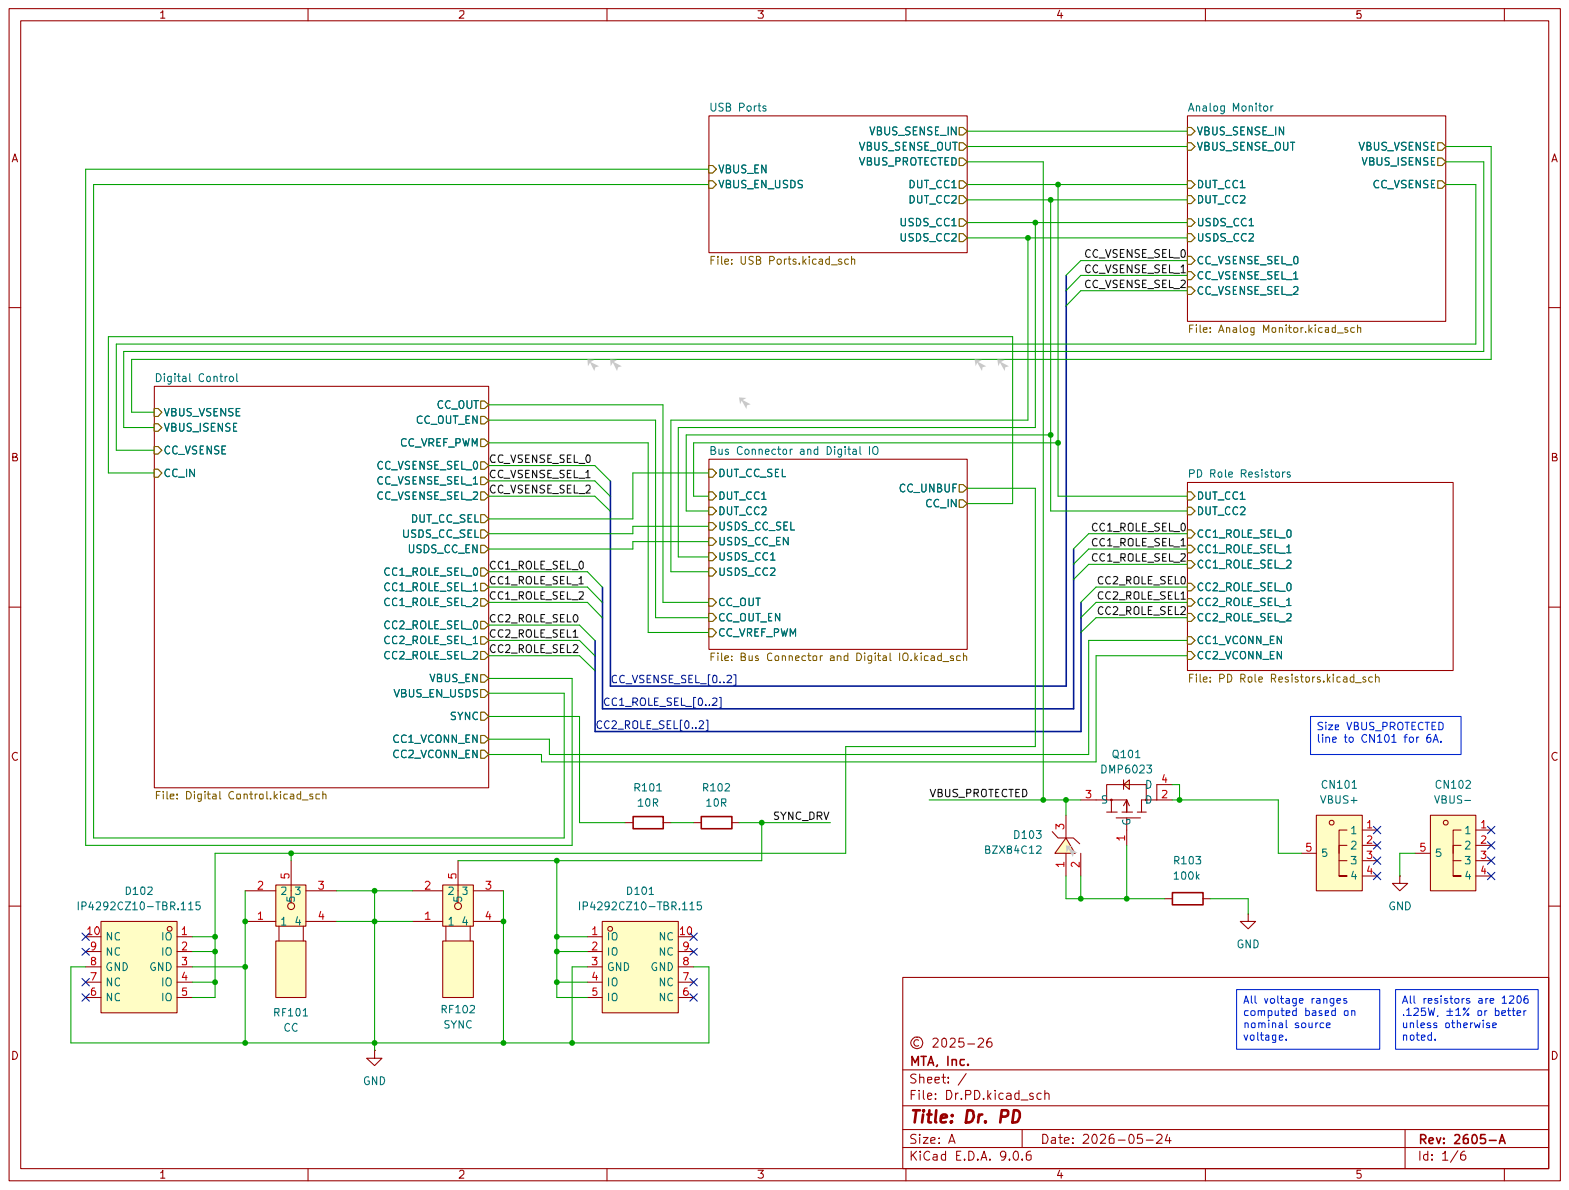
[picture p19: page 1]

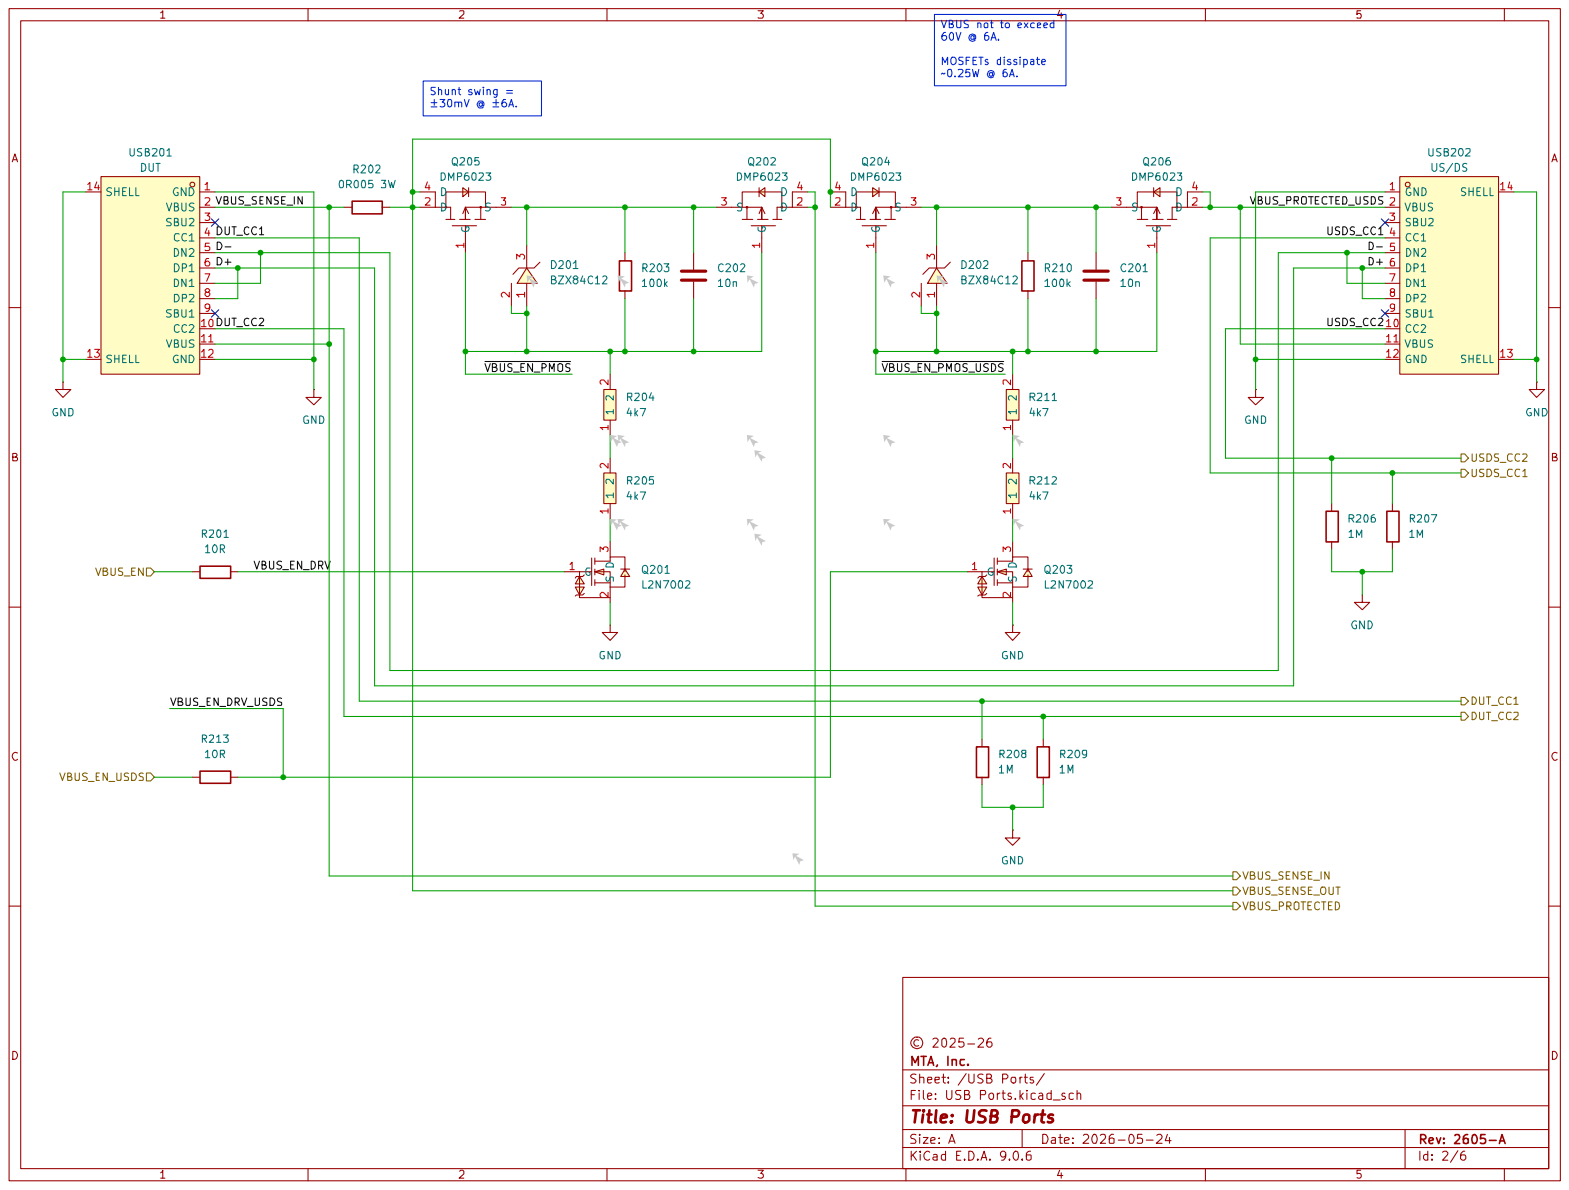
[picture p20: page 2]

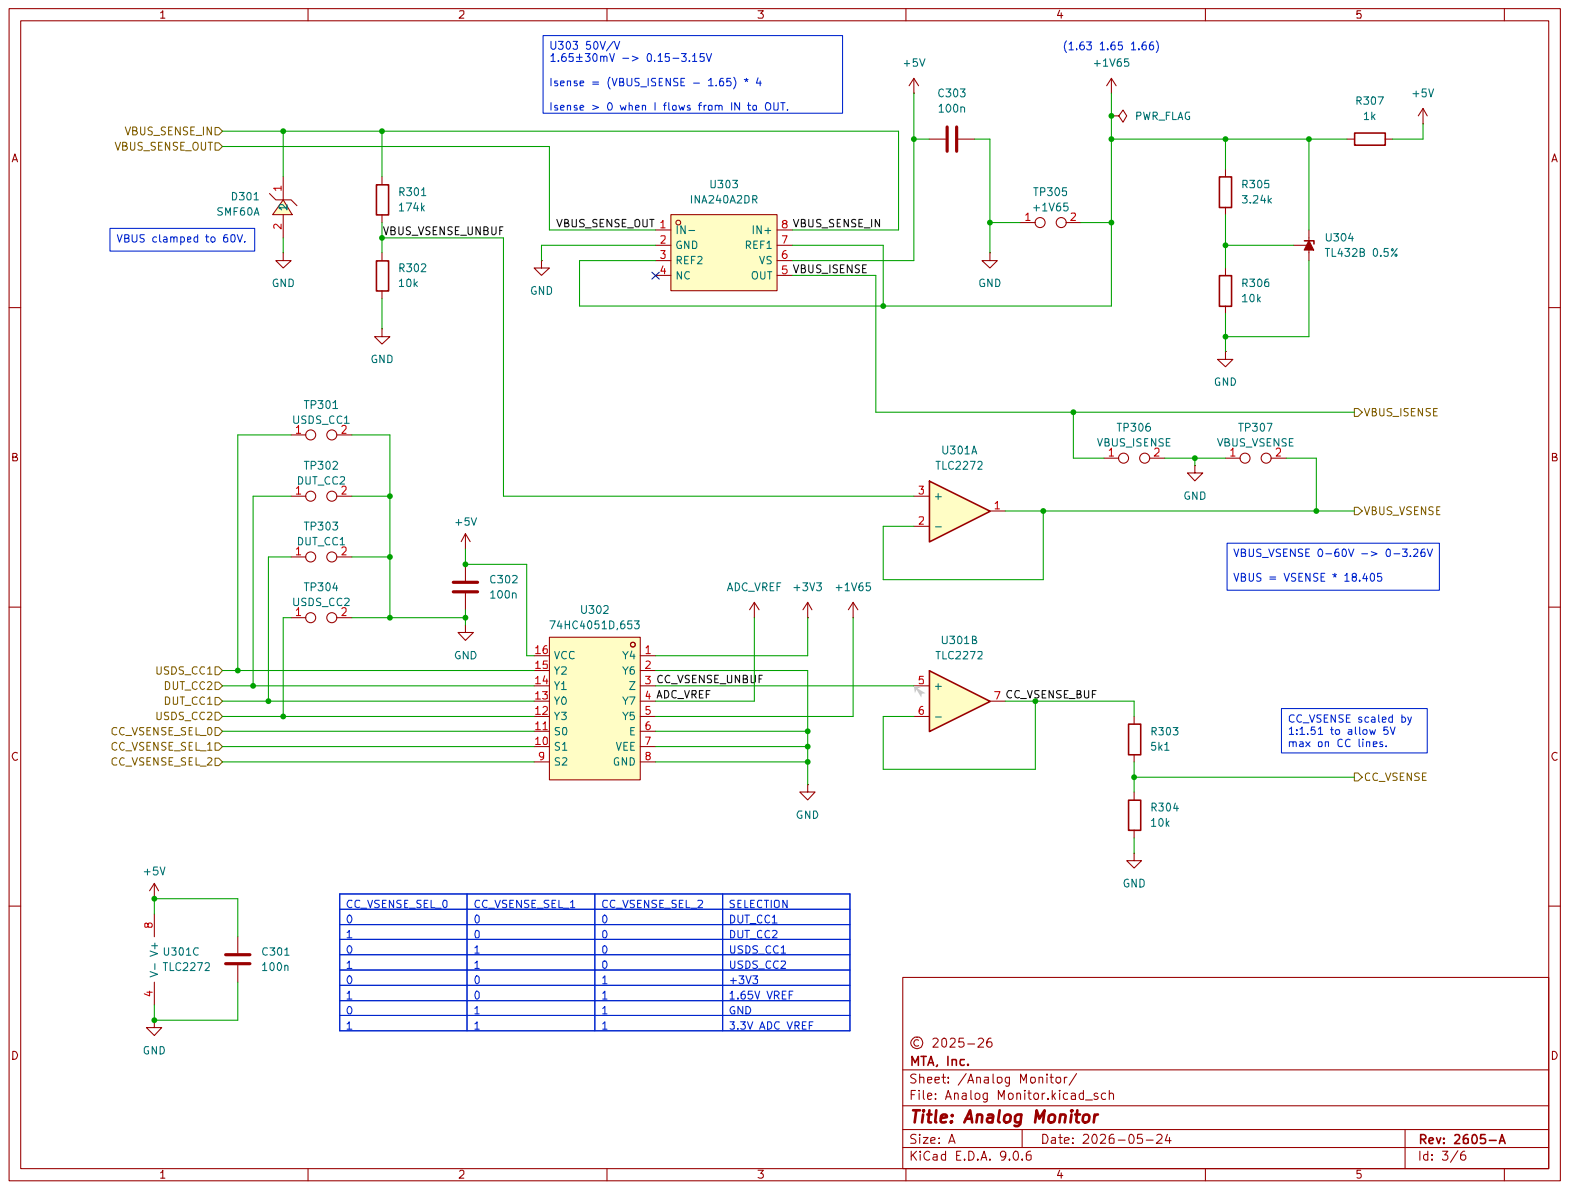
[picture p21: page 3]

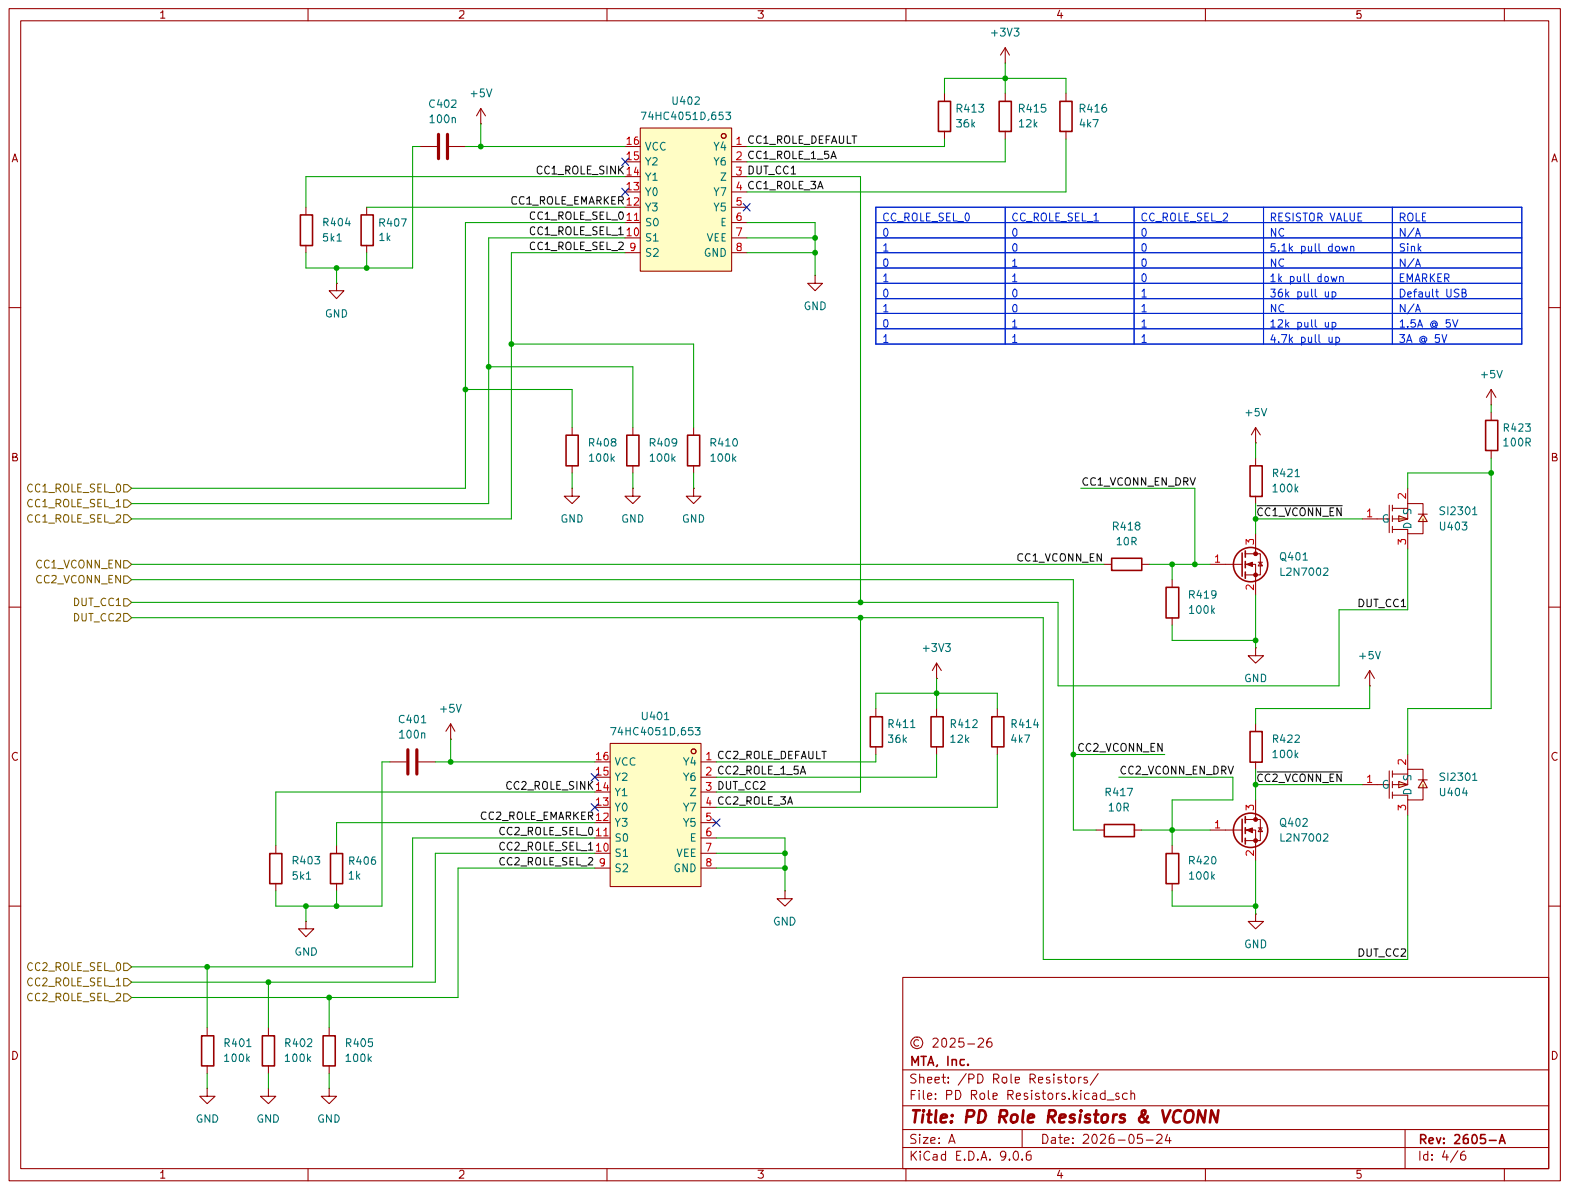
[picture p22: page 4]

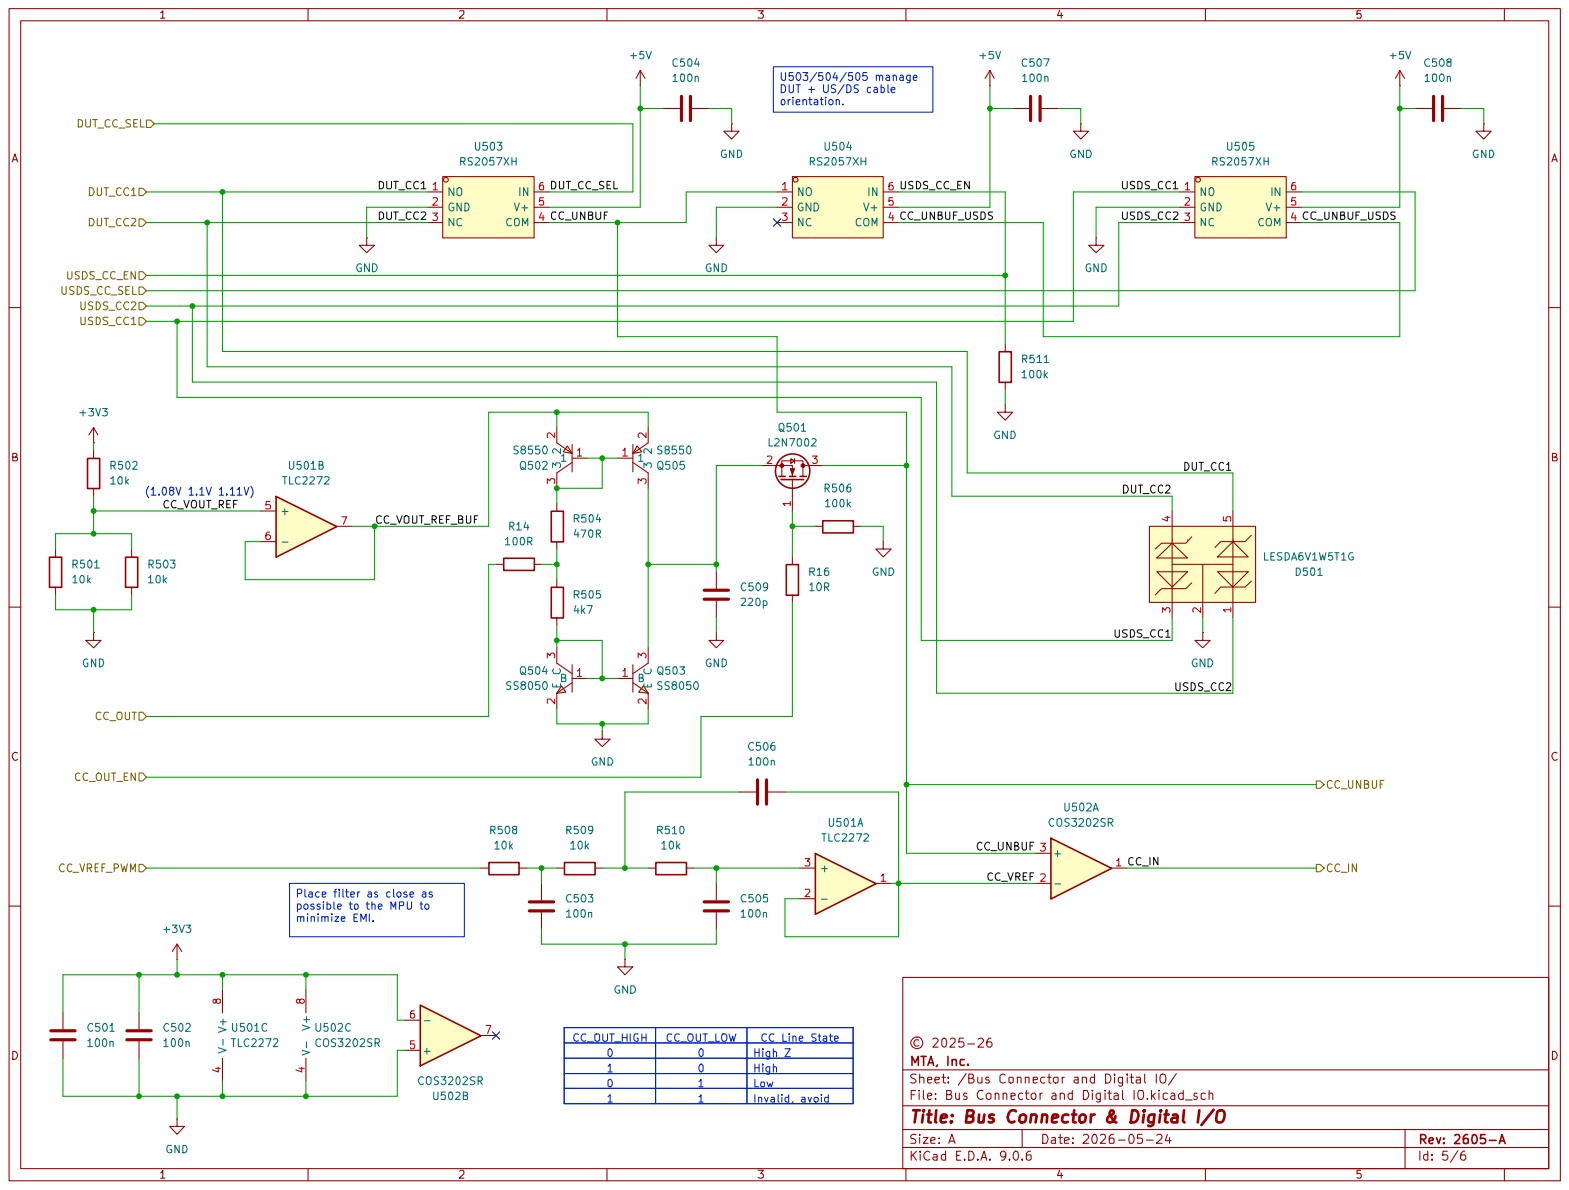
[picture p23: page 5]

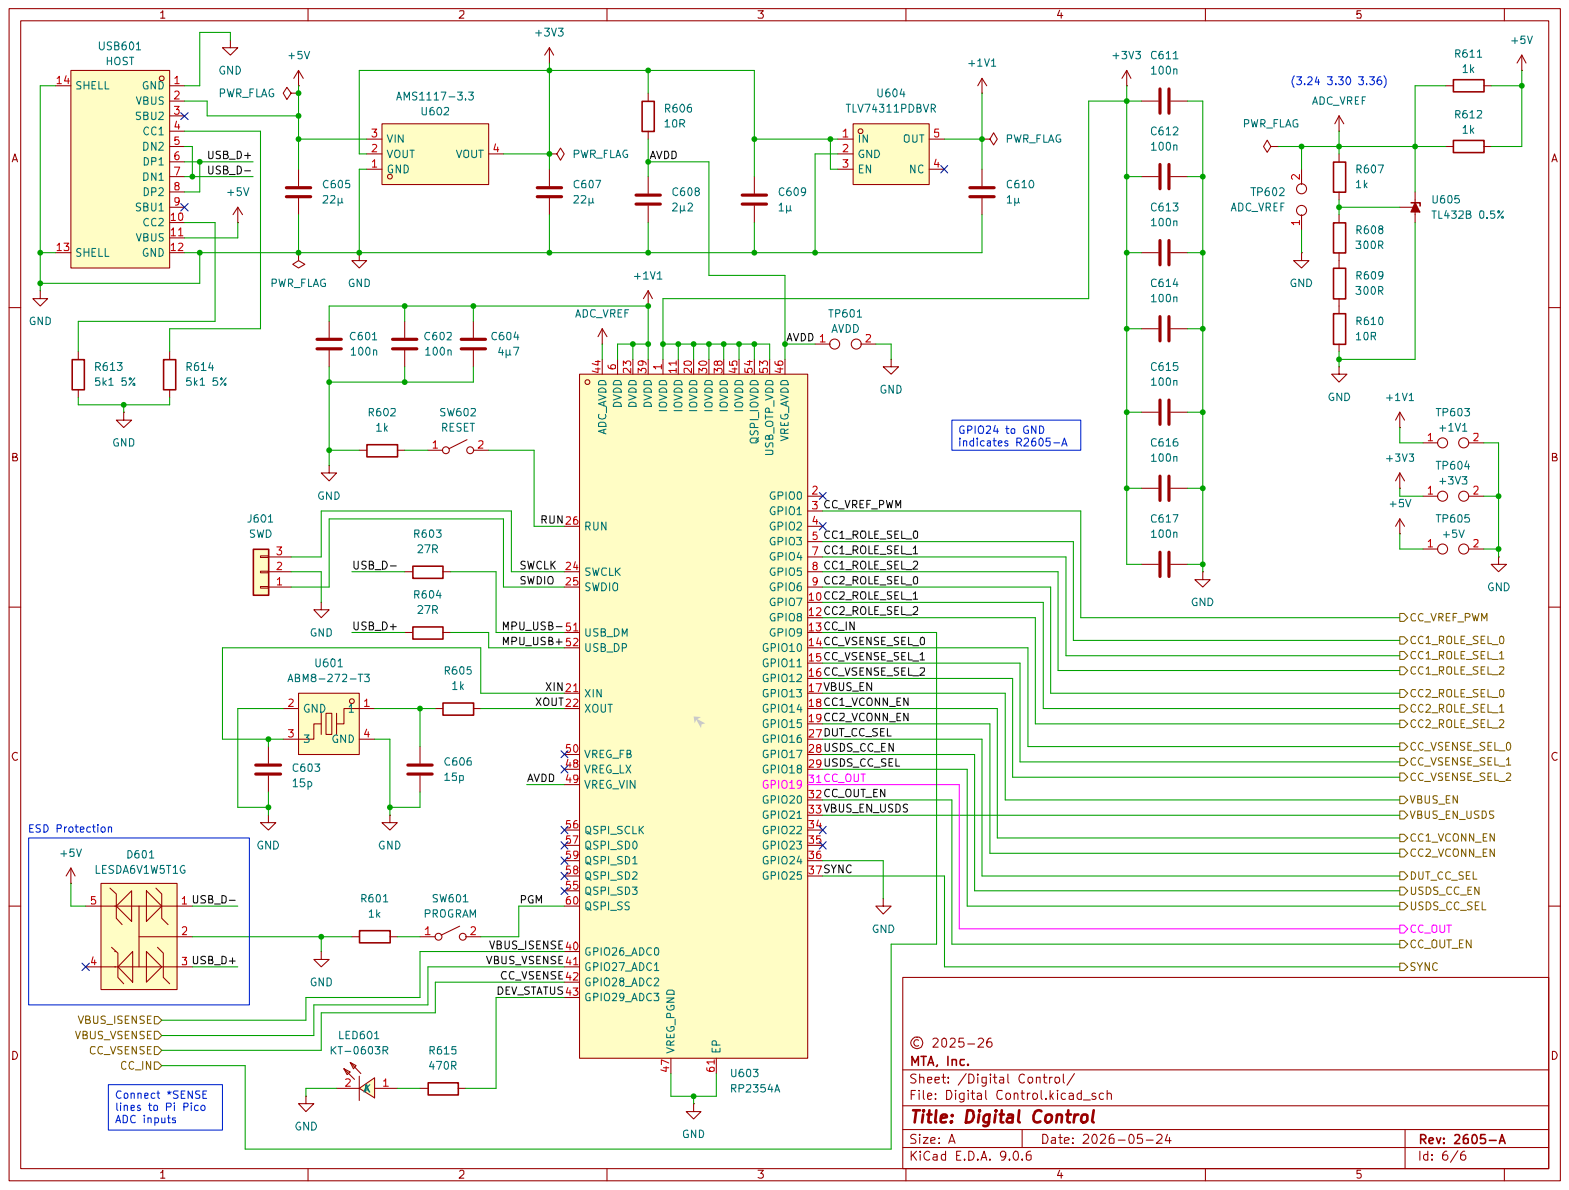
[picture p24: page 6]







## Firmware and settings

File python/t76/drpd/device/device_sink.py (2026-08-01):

"""
Copyright (c) 2025 MTA, Inc.

The Device class enables communication with DRPD devices
over USB using SCPI commands.
"""

import asyncio
from collections import deque
from dataclasses import dataclass
from decimal import Decimal
from typing import TYPE_CHECKING, Deque, Optional

from t76.drpd.device.device_sink_pdos import DeviceSinkPDO
from t76.drpd.device.types import (
    AuthenticationCertificateInquiryData,
    AuthenticationChallengeInquiryData,
    AuthenticationDigestsInquiryData,
    AuthenticationErrorInquiryData,
    BatteryCapabilitiesInquiryData,
    BatteryCapacity,
    BatteryCapacityMeaning,
    BatteryChargingState,
    BatteryInquiryFailureAction,
    BatteryStatusInquiryData,
    BatterySurveyResult,
    CableDiscoverIdentityInquiryRequest,
    CableDiscoverModesInquiryRequest,
    CableDiscoverSVIDsInquiryRequest,
    CableManufacturerInfoInquiryRequest,
    CablePlug,
    CableRevisionInquiryRequest,
    CableStatusInquiryData,
    CableStatusInquiryRequest,
    ChallengeInquiryRequest,
    CountryCodesInquiryData,
    CountryInfoInquiryData,
    CountryInquiryFailureAction,
    CountryInquiryWorkflowResult,
    DiscoverIdentityInquiryData,
    DiscoverIdentityInquiryRequest,
    DiscoverModesInquiryData,
    DiscoverModesInquiryRequest,
    DiscoverSVIDsInquiryData,
    DiscoverSVIDsInquiryRequest,
    ExtendedSourceCapabilitiesInquiryData,
    GetCertificateInquiryRequest,
    GetDigestsInquiryRequest,
    GetCountryCodesInquiryRequest,
    GetCountryInfoInquiryRequest,
    GetBatteryCapabilitiesInquiryRequest,
    GetBatteryStatusInquiryRequest,
    GetManufacturerInfoInquiryRequest,
    ManufacturerInfoInquiryData,
    ManufacturerInfoTarget,
    Mode,
    PPSStatusInquiryData,
    RevisionInquiryData,
    SinkInquiryDecodedData,
    SinkRequestOutcome,
    SinkRequestStatus,
    SinkInquiryOutcome,
    SinkInquiryRequest,
    SinkInquiryResult,
    SinkInquiryStatus,
    SinkInquiryType,
    SinkState,
    SourceCapabilitiesInquiryData,
    SourceInfoInquiryData,
    SourceStatusInquiryData,
    StructuredVDMHeaderData,
    StructuredVDMNegativeResponseData,
    VDMDiscoveryFailureAction,
    VDMDiscoveryWorkflowResult,
)
from t76.drpd.message.data_objects import SourcePDO

from .device_internal import DeviceInternal

if TYPE_CHECKING:
    from t76.drpd.device.device import Device


@dataclass
class SinkInfo:
    """
    Represents comprehensive information about the sink system of the DRPD device.
    """

    status: SinkState
    negotiated_pdo: Optional[DeviceSinkPDO]
    negotiated_voltage: float
    negotiated_current: float
    error_status: bool


class SinkInquirySupersededError(RuntimeError):
    """Raised when firmware's latest result no longer belongs to this run."""


class SinkInquiryRunner:
    """Serialize, correlate, and retain semantic Sink inquiry executions."""

    MAX_HISTORY = 256
    MAX_POLLS = 10000
    MAX_POLL_INTERVAL_SECONDS = 60.0

    def __init__(self, sink: "DeviceSink", history_limit: int = 64):
        if not 1 <= history_limit <= self.MAX_HISTORY:
            raise ValueError(
                f"history_limit must be between 1 and {self.MAX_HISTORY}"
            )
        self._sink = sink
        self._lock = asyncio.Lock()
        self._history: Deque[SinkInquiryResult] = deque(maxlen=history_limit)

    @property
    def history(self) -> tuple[SinkInquiryResult, ...]:
        """Return oldest-to-newest completed host-side inquiry history."""
        return tuple(self._history)

    async def run(
        self,
        request: SinkInquiryRequest,
        *,
        poll_interval_seconds: float = 0.01,
        max_polls: int = 1000,
    ) -> SinkInquiryResult:
        """Run one inquiry and return its correlated terminal result."""
        self._validate_run_options(poll_interval_seconds, max_polls)

        async with self._lock:
            return await self._run_locked(
                request, poll_interval_seconds, max_polls
            )

    def _validate_run_options(
        self, poll_interval_seconds: float, max_polls: int
    ) -> None:
        if not 0 <= poll_interval_seconds <= self.MAX_POLL_INTERVAL_SECONDS:
            raise ValueError(
                "poll_interval_seconds must be between 0 and "
                f"{self.MAX_POLL_INTERVAL_SECONDS}"
            )
        if not 1 <= max_polls <= self.MAX_POLLS:
            raise ValueError(f"max_polls must be between 1 and {self.MAX_POLLS}")

    async def _run_locked(
        self,
        request: SinkInquiryRequest,
        poll_interval_seconds: float,
        max_polls: int,
    ) -> SinkInquiryResult:
        """Run one validated inquiry while caller holds the runner lock."""
        baseline = await self._sink.get_inquiry_status()
        await self._sink.send_inquiry(request)
        request_id: int | None = None

        for poll_index in range(max_polls):
            status = await self._sink.get_inquiry_status()

            if request_id is None and status.request_id == baseline.request_id:
                if poll_index + 1 < max_polls and poll_interval_seconds:
                    await asyncio.sleep(poll_interval_seconds)
                continue

            if status.type != request.type:
                raise SinkInquirySupersededError(
                    "Inquiry result type changed before this request completed"
                )

            if request_id is None:
                request_id = status.request_id
            elif status.request_id != request_id:
                raise SinkInquirySupersededError(
                    f"Inquiry {request_id} was superseded by "
                    f"inquiry {status.request_id}"
                )

            if status.outcome == SinkInquiryOutcome.PENDING:
                if poll_index + 1 < max_polls and poll_interval_seconds:
                    await asyncio.sleep(poll_interval_seconds)
                continue

            raw_response = None
            if (
                status.outcome == SinkInquiryOutcome.RESPONSE
                or status.response_length > 0
            ):
                raw_response = await self._sink.get_inquiry_response()
                if len(raw_response) != status.response_length:
                    raise ValueError(
                        "Inquiry response length does not match status: "
                        f"expected {status.response_length}, "
                        f"got {len(raw_response)}"
                    )

            decoded = None
            if raw_response is not None:
                decoded = _decode_inquiry_response(request, status, raw_response)

            result = SinkInquiryResult(request, status, raw_response, decoded)
            self._history.append(result)
            return result

        raise TimeoutError(
            "Inquiry did not publish a correlated terminal result within "
            f"{max_polls} polls"
        )
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

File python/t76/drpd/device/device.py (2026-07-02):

"""
Copyright (c) 2025 MTA, Inc.

The Device class enables communication with DRPD devices
over USB using SCPI commands.
"""

import asyncio
import logging

from typing import Any, Optional

import usb

from t76.drpd.device.types import DeviceStatusFlags

from ..message.bmc_sequence import BMCSequence, FirmwareCaptureEvent
from ..message.header import Header
from ..message import Message

from .device_analog_monitor import DeviceAnalogMonitor
from .device_capture import DeviceCapture
from .device_events import DeviceEvents
from .device_internal import DeviceInternal
from .device_mode import DeviceMode
from .device_sink import DeviceSink
from .device_system import DeviceSystem
from .device_test import DeviceTest
from .device_trigger import DeviceTrigger
from .device_vbus import DeviceVBus

from .events import (
    BMCSequenceCaptured,
    CCBusStateChanged,
    CaptureStatusChanged,
    DeviceConnected,
    DeviceDisconnected,
    FirmwareEventCaptured,
    InterruptReceived,
    RoleChanged,
    SinkInfoChanged,
    SinkPDOListChanged,
    TriggerStatusChanged,
    VBusManagerStateChanged,
)


class Device:
    """
    Represents a DRPD device connected via USB over USBTMC.

    :param usb_device: The USB device object representing the DRPD device.
    :type usb_device: usb.core.Device
    """

    def __init__(self, usb_device: usb.core.Device):
        self.events = DeviceEvents()
        self._internal = DeviceInternal(usb_device, self._interrupt_handler)
        self._disconnecting = False

        self.analog_monitor = DeviceAnalogMonitor(self._internal, self)
        self.mode = DeviceMode(self._internal)
        self.capture = DeviceCapture(
            self._internal, self._capture_fetched_callback)
        self.sink = DeviceSink(self._internal, self)
        self.system = DeviceSystem(self._internal)
        self.test = DeviceTest(self._internal)
        self.trigger = DeviceTrigger(self._internal)
        self.vbus = DeviceVBus(self._internal)

    async def connect(self) -> None:
        """
        Connect to the device and set up event handling.
        """
        self._disconnecting = False
        await self._internal.connect()

        await self.events.dispatch_event(DeviceConnected(self))

    async def disconnect(self) -> None:
        """
        Disconnect from the device and clean up event handling.
        """
        self._disconnecting = True
        try:
            await self.events.dispatch_event(DeviceDisconnected(self))
        except Exception as e:
            logging.warning(
                "Ignoring observer error while dispatching disconnect for %s: %s",
                self,
                e,
            )
        finally:
            await self._internal.disconnect()

    @property
    def name(self) -> Optional[str]:
        """
        Get the name of the device.

        :return: The name of the device.
        :rtype: str
        """
        return self._internal.name

    async def _process_interrupt(self) -> None:
        if self._disconnecting or not self._internal.connected:
            return

        # Fetch device status
        device_status = int((await self._internal.query_ascii_values_and_check("STAT:DEV?"))[0])

        if device_status & DeviceStatusFlags.VBUS_STATUS_CHANGED.value:
            bus_info = await self.vbus.get_info()
            ev = VBusManagerStateChanged(self, bus_info)
            await self.events.dispatch_event(ev)

        if device_status & DeviceStatusFlags.ROLE_CHANGED.value:
            new_role = await self.mode.get()
            ev = RoleChanged(self, new_role)
            await self.events.dispatch_event(ev)

        if device_status & DeviceStatusFlags.CAPTURE_STATUS_CHANGED.value:
            is_capturing = await self.capture.get_status()
            ev = CaptureStatusChanged(self, is_capturing)
            await self.events.dispatch_event(ev)

        if device_status & DeviceStatusFlags.CC_BUS_STATUS_CHANGED.value:
            cc_bus_state = await self.mode.get_status()
            ev = CCBusStateChanged(self, cc_bus_state)
            await self.events.dispatch_event(ev)

        if device_status & DeviceStatusFlags.TRIGGER_STATUS_CHANGED.value:
            trigger_info = await self.trigger.get_trigger_info()
            ev = TriggerStatusChanged(self, trigger_info)
            await self.events.dispatch_event(ev)

        if device_status & DeviceStatusFlags.SINK_PDO_LIST_CHANGED.value:
            try:
                pdo_count = await self.sink.get_pdo_count()
                new_pdos = []

                for index in range(pdo_count):
                    new_pdos.append(await self.sink.get_pdo_at_index(index))

                ev = SinkPDOListChanged(self, new_pdos)
                await self.events.dispatch_event(ev)
            except RuntimeError as ex:
                logging.warning("Failed to get PDO list: %s", ex)

        if device_status & DeviceStatusFlags.SINK_STATUS_CHANGED.value:
            try:
                sink_info = await self.sink.get_sink_info()
                ev = SinkInfoChanged(self, sink_info)
                await self.events.dispatch_event(ev)
            except RuntimeError as ex:
                logging.warning("Failed to get sink info: %s", ex)

        if device_status & DeviceStatusFlags.MESSAGE_RECEIVED.value:
            try:
                await self.capture.fetch_extant_captures()
            except RuntimeError as ex:
                if self._disconnecting or not self._internal.connected:
                    return
                logging.warning("Failed to fetch capture data: %s", ex)

        ev = InterruptReceived(self)

        await self.events.dispatch_event(ev)

    async def _safe_process_interrupt(self) -> None:
        try:
            await self._process_interrupt()
        except (AssertionError, RuntimeError, ValueError, TimeoutError) as e:
            if self._disconnecting or not self._internal.connected:
                return
            logging.warning("Ignoring interrupt handling error: %s", e)

    def _interrupt_handler(self, _: Any, __: Any, ___: Any) -> None:
        if self._disconnecting or not self._internal.connected:
            return

        try:
            loop = asyncio.get_running_loop()
        except RuntimeError:
            asyncio.run(self._safe_process_interrupt())
            return

        loop.create_task(self._safe_process_interrupt())

    def _capture_fetched_callback(
            self,
            capture: BMCSequence | FirmwareCaptureEvent) -> None:
        # Advise observers of the interrupt event
        if isinstance(capture, FirmwareCaptureEvent):
            ev = FirmwareEventCaptured(self, capture)
        else:
            ev = BMCSequenceCaptured(self, capture)

        asyncio.create_task(self.events.dispatch_event(ev))
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

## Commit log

2026-02-13 Add R2601-A schematics
    [Analog Monitor.kicad_sch, Bus Connector and Digital IO.kicad_sch, Digital Control.kicad_sch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]
2026-02-13 Refactor Sink State Management: Encapsulate Runtime State and Context
    - Introduced SinkRuntimeState class to encapsulate all mutable runtime data previously spread across the Sink class.
    - Created SinkContext class to manage interactions between state handlers and the SinkRuntimeState.
    - Updated state handlers (TransitionSinkStateHandler, WaitForCapabilitiesStateHandler) to use SinkContext for state management and message handling.
    - Removed direct access to Sink internals from state handlers, promoting better encapsulation and reducing coupling.
    - Modified handler lifecycle methods to accept SinkContext as a parameter, ensuring explicit context management.
    - Updated related header files to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
2026-02-13 Validate voltage range in AVS operation: return false for zero voltage in requestPDO and mark message as invalid in AugmentedPDO
2026-02-13 Refactor power role validation in message handling: use optional check for improved clarity
2026-02-14 Refactor message handling: replace BMCDecodedMessage with CapturedMessage to reduce memory footprint and improve efficiency; update related configurations for message queue and pulse buffer sizes
2026-02-16 Allocate Sink statically, rather than dynamically. Add threadsafe guards around callback setters/getters.
2026-02-16 Implement device connection panel reconciliation and enhance device management
    - Introduced periodic device discovery and reconciliation in the DRPD app.
    - Updated device selection screen to auto-highlight the first detected device.
    - Enhanced disconnect logic in DeviceInternal to ensure proper resource cleanup.
    - Added unit tests for device reconciliation and selection behavior.
    - Created an ExecPlan document to outline the reconciliation process and decisions.
2026-02-17 Enhance logic sink and BMC encoder functionality
    - Added new compile definitions for maximum extended payload sizes in sink configuration.
    - Updated BMC encoder configuration to include maximum encoded words and message body size.
    - Enabled static memory allocation in FreeRTOS configuration for improved memory management.
    - Refactored sink message handling to utilize static queue and task structures, enhancing performance and reliability.
    - Replaced dynamic vector usage with static arrays in various components to reduce heap fragmentation and improve efficiency.
    - Improved handling of extended message fragments in sink logic, ensuring proper payload management and error handling.
    - Updated E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
2026-02-18 Remove repeating timer setup in core 1 and directly call BMC decoder and encoder callbacks in the loop
2026-02-18 feat: Implement Sink-specific Core-1 alarm pool
    - Added SinkAlarmService to manage a dedicated Pico SDK alarm pool for Sink timers.
    - Updated Sink state handlers and message sender to use the new alarm service for timer management.
    - Introduced initCore1 method to initialize the alarm pool from Core 1.
    - Replaced direct calls to add_alarm_in_us and cancel_alarm with service methods in relevant files.
    - Created documentation for the new alarm service and migration plan.
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2026-02-19 Make core1 work single-threaded; fix bug in BMCDecoder
2026-02-20 Fix hanging on timeouts and crashes when device disconnects
    [device.py, device_internal.py]
2026-02-21 Enhance AVS and PPS setup modals with validation for voltage/current steps and update tests
2026-02-23 feat: Enhance DRPD sink and VBus functionality with new PDO types and improved parsing
    - Added support for SPR_PPS and AVS PDO types in DrpdSinkControlInstrumentView.
    - Updated parsing logic for sink PDOs to handle new types and their properties.
    - Enhanced VBus methods to use scaled milli-units for voltage and current thresholds.
    - Improved test coverage for new functionalities and edge cases.
    - Refactored data object imports to maintain consistent naming conventions.
2026-02-24 Implement worker-backed transport and logging services
    - Add worker service client for DRPD transport and logging.
    - Create log store proxy for handling log operations in the worker.
    - Implement transport proxy to manage USBTMC requests through the worker.
    - Define message protocol for communication between main thread and worker.
    - Introduce serialization helpers for error handling in worker messaging.
    - Establish heartbeat mechanism to monitor worker health and auto-refresh on failure.
2026-02-25 Refactor Dr.PD PDO Request Popup to Two-Pane List and Form Layout
    - Redesigned the Sink Control instrument's PDO request popup to feature a scrollable list of PDOs on the left and voltage/current request controls on the right.
    - Updated validation logic to ensure immediate feedback for user inputs, including dynamic AVS current limits based on requested voltage.
    - Replaced the previous dropdown selection with a button-based list that displays both primary and secondary information for each PDO.
    - Implemented functionality to allow voltage editing for specific PDO types while ensuring fixed-voltage PDOs are read-only.
    - Enhanced user experience by adding Cancel and Escape key functionality to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
2026-02-25 feat: add VBUS instrument for Dr. PD telemetry and update device status instrument
    - Introduced DrpdVbusInstrument class to represent VBUS telemetry.
    - Updated DrpdDeviceStatusInstrument to reflect changes in identifier and layout.
    - Refactored DrpdDeviceStatusInstrumentView to remove analog monitor dependencies and focus on role/capture controls.
    - Created DrpdVbusInstrumentView to display VBUS voltage, current, and derived power.
    - Added corresponding CSS styles for the new VBUS instrument view.
    - Implemented tests for the new VBUS instrument view to ensure correct rendering of values.
2026-02-25 feat(logging): Enhance logging subsystem with diagnostics and log counts
    - Implemented logging diagnostics retrieval in DRPDDevice and DRPDWorkerDeviceProxy.
    - Added methods to get current log row counts for analog samples and captured messages.
    - Introduced a new logging backend diagnostics interface for better inspection.
    - Updated SQLiteWasmStore to support memory fallback and improved retention management.
    - Enhanced logging behavior on capture state changes, ensuring logging starts/stops appropriately.
    - Added documentation for the logging subsystem, detailing storage backends, log lifecycle, and DevTools helpers.
    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
2026-03-04 fix: update humanReadableMetadata to use baseInformation for message descriptions
    - Refactored the humanReadableMetadata getter in multiple message classes to replace the use of `metadata.insertEntryAt` with `metadata.baseInformation.insertEntryAt` for setting the 'messageDescription' entry.
    - This change ensures consistency in how metadata is structured across various USB-PD message types, enhancing clarity and maintainability.
2026-03-07 Enhance USB-PD message parsing with detailed human-readable metadata
    - Updated RequestMessage to include metadata for request data objects.
    - Enhanced ReservedDataMessage to display raw data objects in human-readable format.
    - Improved ReservedExtendedMessage to show raw payload bytes.
    - Added metadata for revision data objects in RevisionMessage.
    - Updated SecurityRequestMessage and SecurityResponseMessage to include security data blocks.
    - Enhanced SinkCapabilitiesExtendedMessage and SourceCapabilitiesExtendedMessage to display detailed capability metrics.
    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
2026-03-07 Enhance USB-PD Metadata Rendering and Parsing Tests
    - Updated the parsing logic in DataObjects.ts to correct the interpretation of VBUS requirements and improve metadata formatting for various VDOs.
    - Added new formatting functions for USB-PD metadata, including versions, capabilities, and power requirements.
    - Expanded unit tests in MessageDecoding.test.ts to validate the rendering of coded PDO and VDO metadata with raw values and decoded meanings.
    - Ensured comprehensive coverage for UFP, DFP, and passive cable VDOs, including detailed checks for each metadata entry.
2026-03-08 feat: add device state handling and selection display to message detail instrument view
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2026-03-09 feat: add DrpdUsbPdLogTimeStrip component with styling and utility functions
    - Implemented DrpdUsbPdLogTimeStrip component for visualizing message log data.
    - Created associated CSS module for styling the time strip interface.
    - Developed utility functions for handling time window management, including clamping and zooming.
    - Added tests for utility functions to ensure correct behavior.
    - Integrated D3 for rendering pulse and analog data on canvas elements.
2026-03-09 feat: enhance pulse trace computation and logging
    - Introduced computePulseTraceEndTimestampUs utility to calculate waveform end timestamps based on pulse widths.
    - Updated DrpdUsbPdLogInstrumentView to utilize the new trace end timestamp in rendering.
    - Removed zoom controls from the time strip as part of UI simplification.
    - Refactored CSS styles for the time strip to streamline layout and appearance.
    - Modified SQLiteWasmStore to track and utilize maximum observed pulse trace durations for better message visibility.
    - Enhanced tests to cover new functionality and ensure correct behavior of pulse trace calculations.
2026-03-09 feat: refactor device menu and header popover for improved layout and responsiveness
2026-03-09 feat: update button label from "Add Device" to "Pair Device" for clarity
2026-03-11 refactor: update font size for header and adjust instrument slot padding for layout consistency
2026-03-11 refactor: replace placeholder instrument with device status panel and update related components for consistency
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2026-03-11 refactor: enhance log handling by integrating analog samples and updating related components for clarity
2026-03-12 refactor: enhance device identity handling and update related UI labels in RackView
2026-03-12 feat: Refactor DRPD USB PD Log Instrument View and add standalone Time Strip Instrument View
    - Removed the DrpdUsbPdLogTimeStrip component from DrpdUsbPdLogInstrumentView.
    - Updated styles for the time strip shell to ensure proper width and minimum width.
    - Enhanced DrpdUsbPdLogTimeStrip to manage selection state and synchronize with the driver.
    - Added a new DrpdTimeStripInstrumentView component to encapsulate the time strip functionality.
    - Implemented comprehensive tests for the DrpdTimeStripInstrumentView to ensure correct rendering and behavior.
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2026-03-13 feat(analog_monitor): add accumulation tracking for charge and energy
    - Introduced accumulation fields in AnalogMonitor for tracking elapsed time, accumulated charge (mAh), and accumulated energy (mWh).
    - Updated the AnalogMonitor class to initialize and reset these new fields.
    - Enhanced readVBusValues method to calculate and accumulate charge and energy based on voltage and current readings.
    - Added new methods to retrieve accumulated charge, energy, and elapsed time.
    - Updated SCPI commands to query and reset accumulated values.
    - Modified frontend components to display accumulated charge and energy metrics.
    - Added unit tests for parsing and retrieving accumulation fields in DeviceAnalog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
    [device_analog_monitor.py, types.py]
2026-03-13 feat: add DrpdAccumulatorInstrument and associated view
    - Implemented DrpdAccumulatorInstrument class for handling accumulated charge and energy measurements.
    - Created DrpdAccumulatorInstrumentView component to display accumulated values and reset functionality.
    - Updated RowRenderer to include the new accumulator instrument.
    - Enhanced tests for the accumulator instrument view to verify display and reset functionality.
    - Added parsing logic for accumulated measurements in the DRPD device.
    - Introduced CSS styles for the accumulator instrument view.
    - Updated instrument catalog to register the new accumulator instrument.
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2026-03-14 feat(logging): add wall clock synchronization to DRPD logging
    - Introduced wallClockUs field in LoggedAnalogSample and LoggedCapturedMessage interfaces to store estimated host wall-clock timestamps in microseconds.
    - Implemented clock synchronization logic in DRPDDevice, including methods for periodic synchronization and handling connection events.
    - Updated logging schema to include wall_clock_us column in both analog_samples and captured_messages tables.
    - Enhanced SQLiteWasmStore to handle wall clock timestamps during data insertion and retrieval.
    - Modified tests to validate the new wall clock synchronization feature and ensure correct data handling.
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2026-03-23 Add methods for VBUS voltage correction management in AnalogMonitor
    - Introduced `vBusVoltageCorrectionByRawVolt()` to retrieve the full correction table.
    - Added `vBusVoltageCorrectionByRawVolt(size_t bucket, float correctionVolts)` to update specific correction entries.
    - Enhanced documentation for new methods to clarify usage and parameters.
2026-03-24 Add VBUS calibration functionality and related scripts
    - Implemented VBUS voltage calibration in AnalogMonitor, allowing raw scaled VBUS readings below 1V to bypass the correction table.
    - Updated AnalogMonitor header to define MinimumCalibratedVBusVoltage constant.
    - Enhanced DeviceAnalogMonitor class with methods to retrieve and calibrate VBUS correction table.
    - Added tests for new DeviceAnalogMonitor methods to ensure correct functionality.
    - Created a calibration script (calibrate_vbus_dps150.py) for automating VBUS bucket calibration using a FNIRSI DPS150 power supply.
    - Added a setup script (setup_vbus_calibration_env.sh) to create a virtual environment and install necessary dependenc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
    [device_analog_monitor.py]
2026-03-26 feat: Implement WinUSB transport for DRPD devices
    - Introduced a new transport layer for DRPD devices using WinUSB.
    - Refactored device connection logic to support both USBTMC and WinUSB transports.
    - Updated device verification to check for WinUSB interfaces.
    - Enhanced logging for transport selection and errors.
    - Added tests for the new transport functionality and integration with existing device logic.
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2026-04-05 feat: migrate rack device management to support paired devices
    - Introduced `pairedDevices` in the rack document structure to manage devices globally.
    - Updated the `RackView` and `RackRenderer` components to utilize the new paired devices structure.
    - Refactored device connection logic to handle paired devices, ensuring proper connection and disconnection behavior.
    - Implemented migration logic to convert legacy device structures into the new paired devices format.
    - Enhanced tests to cover the new paired devices functionality and ensure correct behavior during device connection and disconnection.
2026-04-05 fix: update PIO instance in BMC decoder and initialize state machine in encoder
2026-04-14 Add R2603-A schematics.
    [Analog Monitor.kicad_sch, Bus Connector and Digital IO.kicad_sch, Digital Control.kicad_sch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]
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2026-04-24 fix: update button label from 'Menu' to 'Settings' in RackView component and tests
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2026-04-27 refactor: replace Popover components with Dialog components for better accessibility and usability
    - Removed PopoverLifecycle component and replaced it with Dialog in various overlays.
    - Updated RoleMenu to RoleDialog for role selection using Dialog.
    - Refactored FieldHelpButton to utilize Dialog for displaying explanations.
    - Converted SinkRequestPopover, TriggerConfigurePopover, and MessageLog popovers to Dialogs.
    - Enhanced MessageLogFilterPopover to use Dialog for filter options.
    - Added vbusConfigureDialogState utility for managing VBUS configuration dialog state.
    - Improved styling and z-index management for Dialog components.
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2026-04-27 fix: handle negative current values in resolveHeaderCurrentFlow function
2026-04-27 feat: add 'choose power contract' shortcut and update related functionality
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2026-04-29 feat(rack): implement layout switching functionality and associated shortcuts
2026-04-29 feat(rack): implement layout mode persistence and remove layout switch shortcut
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2026-04-30 fix(calibrate_vbus): update DEFAULT_SETTLE_SECONDS and improve reset logic in calibration script
    fix(device_internal): enhance instrument initialization checks and error handling
    test(device_disconnect): add test for disconnect method to ensure command lock is respected
    [device_internal.py]
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2026-04-30 Refactor USBTMC transport tests and remove VisaTransport module
    - Expanded unit tests for DeviceInternal's USBTMC transport, including parsing and instrument interaction.
    - Introduced fake USB device and endpoint classes to simulate USB communication in tests.
    - Removed the VisaTransport module as it is no longer needed.
    - Added a live smoke test for the Dr. PD USBTMC device to verify basic functionality.
    [device.py, device_internal.py]
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2026-05-08 feat(docs): update USB-PD documentation with new characterizing device guide and protection mechanisms
    - Removed dependency on @docusaurus/faster from package.json.
    - Added new documentation on characterizing USB-PD sources and sinks, including testing methods and tips.
    - Introduced a new section on Dr. PD's protection mechanisms, detailing overvoltage, overcurrent, and reverse polarity protections.
    - Created a new warnings and safety precautions document to emphasize safe testing practices with Dr. PD.
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2026-05-20 feat: Add export and import functionality for VBUS calibration tables
    - Introduced new command options for exporting and importing VBUS calibration tables in the `calibrate_vbus_dps150.py` script.
    - Implemented validation for input and output paths during export and import operations.
    - Added methods in `DeviceAnalogMonitor` to set individual calibration table points and replace entire tables for both voltage and current.
    - Created a JSON schema for calibration tables and added a new `tables.json` file containing example data.
    - Enhanced unit tests for the `DeviceAnalogMonitor` to cover new calibration table functionalities.
    [device_analog_monitor.py]
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2026-06-06 feat: implement timestrip zoom functionality and refactor related components
    - Added zoom handling in DrpdTimeStripInstrumentView to pause live follow on user interactions.
    - Introduced clampTimestripZoomDenominator and related functions for managing zoom levels.
    - Created timestripZoom module to encapsulate zoom logic, including reading/writing zoom settings to local storage.
    - Updated timestripCoordinates and timestripLayout to utilize new zoom functions.
    - Added tests for zoom functionality, ensuring correct clamping and formatting of zoom denominators.
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2026-06-10 feat: add hardware revision detection and display in RackView
    - Updated the device identity model to include an optional hardware revision field.
    - Enhanced the DRPDSystem class to query and return the hardware revision from the device.
    - Modified the RackView component to display the hardware revision in the paired device submenu.
    - Added tests to ensure the hardware revision is correctly retrieved and displayed.
    - Implemented hardware revision detection in the firmware using GPIO to differentiate between R2603-A and R2605-A revisions.
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2026-06-12 - Release 0.9.17 - R2605-A documentation
    [Analog Monitor.kicad_sch, Bus Connector and Digital IO.kicad_sch, Digital Control.kicad_sch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]
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2026-06-22 feat(RackView): update fixed voltage label in sink power contract selection
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2026-06-22 feat(MessageLogFilterPopover): enhance message type filtering with dual list selection and reset functionality
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2026-07-01 feat: implement Hard Reset and Cable Reset signaling handling with associated metadata and tests
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2026-07-02 feat: Enhance device system and trigger functionalities
    - Added methods for resetting the device and entering firmware updater in DeviceSystem.
    - Implemented hardware revision retrieval with error handling in DeviceSystem.
    - Introduced sender filter and message type filter functionalities in DeviceTrigger.
    - Enhanced TriggerInfo to include sender filter and message type filters.
    - Added event classes for firmware capture events in events module.
    - Created a DeviceTest class for SCPI command access related to firmware testing.
    - Implemented tests for new functionalities in DeviceSystem, DeviceTrigger, and DeviceTest.
    - Added SCPI parity tests to ensure consistency between Python and TypeScrip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
    [device.py, device_analog_monitor.py, device_capture.py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]
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2026-07-22 Fix SPR AVS current-band reporting and sink limits (#200)
    [device_sink_pdos.py]
2026-07-23 Fix zero-current EPR AVS sink requests (#207)
2026-07-29 Add reusable hardware viewer deep links (#233)
    Closes #226
    [Analog Monitor.kicad_sch, Bus Connector and Digital IO.kicad_sch, Digital Control.kicad_sch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]
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2026-08-01 Revert "Add source inquiry messaging in Sink mode (#260)"
    This reverts commit 3cafd6ac54804b16bede845b34741d11dc06b3b8, reversing
    changes made to 2530ab683e0845d3ae5da02f8fcb5ea1f297f361.
    [authentication.py, device_sink.py, types.py]
2026-08-02 Reapply "Add source inquiry messaging in Sink mode (#260)"
    This reverts commit bc1b3f53f7431f40e3fd868b868bc7e830da393b.
    [authentication.py, device_sink.py, types.py]
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2026-10-06 Avoid copying completed WinUSB response frames (#274)
2026-10-06 Add single-ended cable identity testing on Port 1 (#277)
    * Add standalone cable identity test mode
    * Refine Cable Test status text and theme-aware styling
    * Present cable capabilities in a fixed-height user-focused dialog
    [device_mode.py, types.py]
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2026-10-20 Fix OCP detection for negative current (#282)
